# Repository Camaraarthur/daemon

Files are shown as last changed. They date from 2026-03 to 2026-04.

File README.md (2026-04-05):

<div align="center">
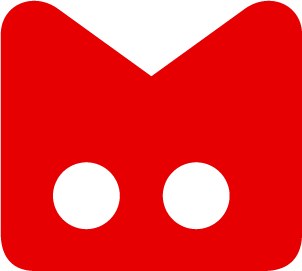
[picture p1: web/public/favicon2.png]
  
  <h1>daemon</h1>
  <p><strong>One AI agent. Terminal access to every device you own.</strong></p>
  <p>Open source &bull; Multi-device &bull; Free tier included &bull; Bring your own keys</p>

  <a href="https://daemon.page">Website</a> &bull;
  <a href="https://daemon.page/download">Download</a> &bull;
  <a href="SPEC.md">Spec</a> &bull;
  <a href="docs/">Docs</a>
</div>

---

## What is Daemon?

Daemon connects all your devices -- laptop, phone, server -- into one AI-powered workspace. Chat with your daemon, and it runs commands on any connected device, syncs your clipboard, deploys your apps, and remembers everything across sessions.

**Free tier**: Qwen3-Coder via OpenRouter. No credit card needed.
**Bring your own key**: Paste your Anthropic/OpenAI/DeepSeek key.
**Link Claude Max**: Use your $100/mo subscription through Daemon.

## Quick Start

```bash
# Install on any device (macOS, Linux, Windows)
curl -sSL daemon.page/install.sh | bash

# Pair with your account
daemon pair <CODE>  # Get code at daemon.page/download

# That's it. Your device is connected.
```

## Features

- **Multi-device mesh** -- Connect phone, laptop, server. Run commands on any device from anywhere.
- **Clipboard sync** -- Copy on your phone, paste on your laptop. Automatic.
- **One-click deploy** -- `/deploy` publishes to username.daemon.page instantly.
- **Persistent memory** -- Your daemon remembers across sessions. Never re-explain context.
- **Slash commands** -- `/commit`, `/deploy`, `/review`, `/search` -- power tools built in.
- **Your data stays yours** -- Local-first. Open source. Self-hostable.
- **Any model** -- Qwen (free), DeepSeek, Claude, GPT -- bring your own keys.
- **Native apps** -- Android, Windows, macOS, Linux. Same experience everywhere.

## How it works

<div align="center">
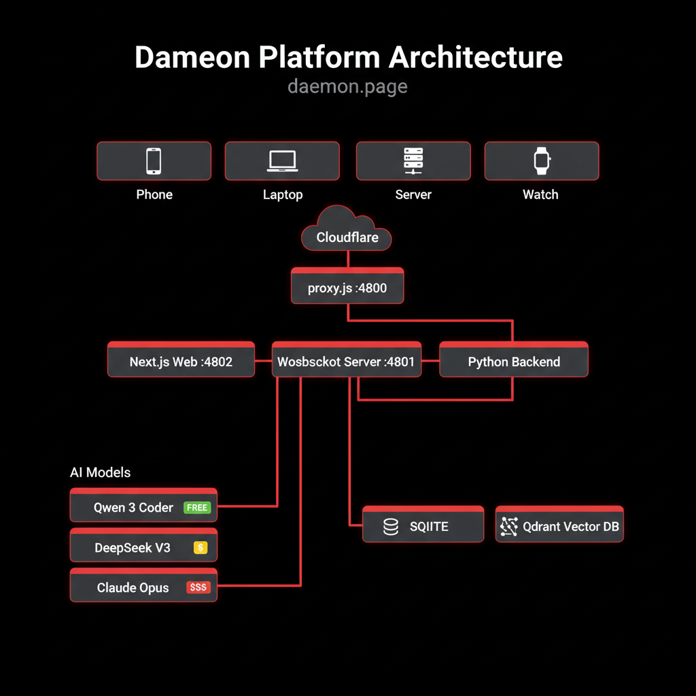
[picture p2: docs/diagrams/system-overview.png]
Daemon system overview
  
</div>

1. Install daemon on your devices
2. Each device connects via WebSocket to the daemon server
3. Chat with your AI -- it can run commands on any connected device
4. Deploy apps, sync files, search memory -- all through one conversation

## vs. Alternatives

| | Daemon | Claude Code | Cursor | Windsurf |
|---|---|---|---|---|
| Multi-device | All devices | One terminal | One IDE | One IDE |
| Free tier | Qwen unlimited | $20+/mo | $20/mo | $15/mo |
| Deploy apps | your.daemon.page | -- | -- | -- |
| Clipboard sync | Cross-device | -- | -- | -- |
| Memory | Persistent | Session only | -- | -- |
| Open source | MIT | -- | -- | -- |
| Self-hostable | Docker compose | -- | -- | -- |
| BYOK | Any provider | Anthropic only | Multiple | Multiple |

## Architecture

Daemon is a monorepo with four main components:

- **`web/`** -- Next.js web UI and API server (port 4800)
- **`cli/`** -- Cross-platform device bridge (Node.js)
- **`android/`** -- Native Android app (Kotlin/Jetpack Compose)
- **`desktop/`** -- Desktop bridge (Tauri/Rust)
- **`protocol/`** -- Shared protocol types (TypeScript)

The server coordinates WebSocket connections between devices and routes AI requests through a 3-tier model router (free Qwen -> mid DeepSeek -> premium Claude/GPT via BYOK).

See [SPEC.md](SPEC.md) for the full v0 specification (7,300 words covering protocol, security, agent architecture, and deployment).

## Self-hosting

```bash
git clone https://github.com/arthurcamara/daemon.git
cd daemon
docker compose up -d
```

Requires: Node.js 20+, SQLite. See [docs/](docs/) for detailed setup.

## Contributing

We welcome contributions. Daemon is built in the open.

- Read [CONTRIBUTING.md](CONTRIBUTING.md) before making changes
- Read [SPEC.md](SPEC.md) for architecture decisions
- Follow the rules in [CLAUDE.md](CLAUDE.md)

## License

[MIT](LICENSE) -- Copyright 2026 Arthur Camara

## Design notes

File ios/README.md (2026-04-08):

# Daemon iOS

Swift native iOS app for daemon. Thin client to `my.daemon.page`. The
brain runs on the user's laptop, daemon-key, or server — the iPhone is
just a face.

- iOS 17+ (required for App Intents, Live Activities)
- Swift 5.9+
- Zero third-party dependencies
- XcodeGen-managed project — no `.xcodeproj` committed

## What's in here

```
ios/Daemon/
├── project.yml                    # XcodeGen spec, materialize with `xcodegen`
├── SupportingFiles/
│   ├── Info.plist
│   ├── Daemon.entitlements        # APNs + App Groups
│   ├── NotificationServiceExtension-Info.plist
│   └── NotificationServiceExtension.entitlements
├── Sources/
│   ├── Daemon/
│   │   ├── DaemonApp.swift              # @main, AppDelegate, silent-push drain
│   │   ├── ContentView.swift            # SwiftUI chat UI
│   │   ├── DaemonClient.swift           # HTTP + WSS + Keychain client
│   │   ├── MockRelay.swift              # fake responses for simulator
│   │   ├── Views/QRScannerView.swift    # AVCaptureSession QR scanner
│   │   ├── AppIntents/
│   │   │   ├── DaemonAppShortcuts.swift       # AppShortcutsProvider
│   │   │   ├── ChatWithDaemonIntent.swift
│   │   │   ├── ReadFileIntent.swift
│   │   │   ├── WriteFileIntent.swift
│   │   │   ├── RemindMeIntent.swift
│   │   │   ├── WhereAmIIntent.swift
│   │   │   └── ClipboardToDaemonIntent.swift
│   │   ├── LiveActivities/
│   │   │   ├── DaemonActivityAttributes.swift
│   │   │   └── DaemonActivityView.swift       # WidgetKit ActivityConfiguration
│   │   ├── Shortcuts/ShortcutsInstaller.swift # first-run Siri donations
│   │   └── Resources/
│   │       ├── Shortcuts/shortcuts.json       # bundled phrase library
│   │       └── MockChatResponse.json
│   └── NotificationServiceExtension/
│       └── NotificationService.swift          # rich push + action buttons
└── README.md
```

## First-time setup (one-time)

1. Install XcodeGen:
   ```sh
   brew install xcodegen
   ```
2. Generate the Xcode project:
   ```sh
   cd ios/Daemon
   xcodegen generate
   open Daemon.xcodeproj
   ```
3. In Xcode → Signing & Capabilities for both targets:
   - Set your **Development Team**
   - Confirm the **Push Notifications** capability
   - Confirm **Background Modes → Remote notifications**
   - Confirm the **App Groups** capability (`group.page.daemon.shared`)
   - Confirm **Live Activities** is enabled (auto from `NSSupportsLiveActivities`)

## Running on the simulator

1. Pick any iOS 17+ simulator
2. Build & run (`⌘R`)
3. On the unpair screen, tap **Use Mock Relay (dev)** to bypass the network
   and exercise the chat UI against the bundled fixtures

The simulator cannot receive real APNs pushes, but you can simulate them:

```sh
xcrun simctl push booted page.daemon.ios ios/Daemon/test/silent-push.apns
```

(Create `silent-push.apns` locally with `{"aps":{"content-available":1}}`.)

## Running on device

1. Plug in an iPhone running iOS 17+
2. Trust the developer cert in Settings → General → VPN & Device Management
3. Build & run — first launch will ask for notification permission and
   camera permission (for QR scan)
4. Pair: on my.daemon.page → Settings → Pair new device → show QR → scan

## Deploying to TestFlight

Arthur's checklist once he has an Apple Developer account (\$99/yr):

1. **App Store Connect** → My Apps → **New App**
   - Name: `Daemon`
   - Bundle ID: `page.daemon.ios` (register under Certificates, Identifiers & Profiles first)
   - Primary language: English
2. **Register the App ID** in the Developer portal with:
   - Push Notifications
   - App Groups (`group.page.daemon.shared`)
3. **Register the extension App ID**: `page.daemon.ios.NotificationService`
4. **APNs Auth Key**: create an `.p8` key in the Developer portal and upload to
   the daemon relay (`web/`) so the relay can send pushes
5. **In Xcode**:
   - Set `MARKETING_VERSION` / `CURRENT_PROJECT_VERSION` in `project.yml`,
     then re-run `xcodegen generate`
   - Product → Archive
   - Window → Organizer → Distribute App → TestFlight & App Store → Upload
6. **In App Store Connect** → TestFlight:
   - Add internal testers (instant) or external testers (Beta App Review, ~24h)
   - Up to 10,000 external testers worldwide, free
7. **Send the invite link** — testers install via the TestFlight app

## Relay endpoints the app talks to

- `POST https://my.daemon.page/api/pair` — `{action: "claim", code, device_id, device_name, platform}` → `{device_token, ws_url}`
- `POST https://my.daemon.page/api/chat` — `{message, threadId?, stream: false}` → `{message, threadId}`
- `WSS wss://my.daemon.page/ws/client` — foreground-only subscription
- `POST https://my.daemon.page/api/devices/apns` — register APNs token (relay must implement this route; stub for now)

## Known limitations / TODOs

- No background WebSocket (Apple kills it — all durable sync is APNs silent push)
- `drainPendingEvents` is a stub — needs a real "fetch events since cursor" endpoint on the relay
- `POST /api/devices/apns` doesn't exist yet on the relay — the client calls it, the relay needs to accept it
- Live Activities widget is declared on the main target; if builds complain, split it into a dedicated Widget Extension target in `project.yml`
- No unit tests yet — add `DaemonTests` target to `project.yml` once behavior stabilizes

## Protocol source of truth

Don't reinvent the protocol — read `/home/arthur/daemon/protocol/types.ts`.
The relay endpoints live in `/home/arthur/daemon/web/src/app/api/`.

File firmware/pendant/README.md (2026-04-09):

# Honest Puck v3.2 — firmware

Privacy-first wearable microphone pendant. ESP32-S3-WROOM-1. ESP-IDF v5.2.

This tree is a fork/rewrite of
[BasedHardware/omi](https://github.com/BasedHardware/omi) `omiGlass/firmware/`
(MIT). The upstream was Arduino + PlatformIO and assumed a Seeed XIAO
ESP32-S3 Sense board with built-in camera. We keep the BLE audio protocol
and the PDM capture pattern, strip the camera + display + all Arduino
dependencies, and target bare ESP-IDF with NimBLE. See [`NOTICE`](NOTICE) for
the per-file credit map.

## What runs on the board

```
app_main()
  |
  |-- honest_gate_init()         IO4 HIGH => mic VDD = 0 V, red LEDs dark
  |-- nvs + NimBLE stack
  |-- honest_ui_init()           buttons + WS2812C RMT driver
  |-- honest_ble_init()          GATT server: Omi audio service (19B10000-...)
  |-- boot self-test             pulse rail ON for 150 ms, then OFF
  |-- idle
        ^
        |  BTN_MAIN press OR BLE control write 0x01
        v
  honest_gate_set_mic_power(true)    IO4 LOW  => mic + LEDs hot
  honest_mic_start()                 i2s_pdm RX @ 16 kHz/16-bit/mono
    -> every 100 ms frame ->
  honest_ble_send_audio_pcm()        Omi framing, notify on AudioData char
```

## Hardware privacy interlock (the whole point)

The mic VDD and the four red WS2812C LEDs share a single copper net that
is the drain of a Si2301BDS PMOS load switch gated by IO4. There is **no**
software path that can record without lighting the ring. See the WARNING
block in
[`components/honest_mic/include/honest_gate.h`](components/honest_mic/include/honest_gate.h)
and the boot self-test in `main/honest_puck_main.c`.

## Pin map

From
[`/media/arthur/CA2247E02247D05D/projects/pendant/ARCHITECTURE.md`](../../)
— see `components/honest_common/include/honest_puck_pins.h`.

| GPIO  | Function |
|---|---|
| IO0 | BTN_MAIN (strapping, normal boot = HIGH) |
| IO1 | BTN_PROG1 |
| IO4 | MIC_ENABLE_N (Si2301BDS PMOS gate) |
| IO5 | PDM_CLK |
| IO6 | PDM_DATA |
| IO7 | LED_BOOST_EN (TPS61023) |
| IO8 | WS2812C data (4 pixels) |
| IO9 | BTN_BATT |
| IO14  | BTN_PROG2 |
| IO10-13, IO2, IO3 | QSPI NAND flash (W25N02KV) (driver not yet wired) |

## Build

Requires ESP-IDF **v5.2** (tested against the release/v5.2 branch).

```bash
. $IDF_PATH/export.sh
cd /home/arthur/daemon/firmware/pendant
idf.py set-target esp32s3
idf.py build
# then on the MSI box that has the serial cable:
idf.py -p /dev/ttyACM0 flash monitor
```

`sdkconfig.defaults` enables NimBLE, octal PSRAM (flip to
`CONFIG_SPIRAM_MODE_QUAD` if your WROOM-1 is the R2 variant, not R8), and
the new I2S driver. No menuconfig steps are required for a first build.

## BLE protocol (client side)

Exactly matches the Omi audio subset:

- Service UUID       `19B10000-E8F2-537E-4F6C-D104768A1214`
- Audio data (notify) `19B10001-...` — 2-byte index + 1-byte sub-index + payload
- Audio codec (read)  `19B10002-...` — one byte; **currently `0` (PCM16)**
- Control (write)     `19B10006-...` — `0x01` = start recording, `0x00` = stop

The daemon Android app (`/home/arthur/daemon/android/`) already speaks Omi
so the only thing it needs to learn is that codec id `0` means raw 16-bit
little-endian PCM at 16 kHz, mono. No changes to pairing or discovery.

## Deliberate decisions made without asking

1. **Codec is raw PCM16, not Opus.** To keep the dep graph MIT/Apache only
   and to guarantee a clean first `idf.py build`, we do not pull libopus.
   The framing and the GATT layout are unchanged, so switching is a
   one-file swap inside `honest_ble_send_audio_pcm()`. Flagged below.
2. **No photo characteristics.** omi uses `19B10005/6` for JPEG transfer.
   The pendant has no camera, so these are removed entirely (not
   advertised, not mounted).
3. **No OTA characteristics.** `19B10010/11/12` removed. The partition
   table still reserves two OTA slots so this can be added later without
   a factory reflash.
4. **No photo button, no camera pins, no OLED** — all stripped from
   omiGlass. ~3000 lines of `app.cpp` became ~150 lines of `honest_ble.c`.
5. **Integer mic gain ×2** kept from upstream as a reasonable default.
6. **Buttons wake the CPU from light sleep implicitly** via GPIO ISR. Deep
   sleep wake-on-button is NOT configured — see below.

## What is NOT done (known limits)

- **Opus encoding** — codec id is PCM16. A 32 kbps Opus path exists in
  upstream and is a straightforward port once libopus or a managed
  component is added.
- **Firmware OTA over BLE** — upstream has a full WiFi+HTTP OTA path
  (`src/ota.cpp`, 408 lines). Partition table has two OTA slots but the
  service is not implemented.
- **Deep sleep + wake-on-button** — the pendant boots straight into idle.
  No light/deep sleep entry, no RTC GPIO wake.
- **W25N02KV NAND driver** — pins are reserved but there is no SPI NAND
  init, no offline recording buffer, no wear levelling.
- **Battery monitoring** — `BTN_BATT` is polled by `honest_ui_button_level()`
  but there is no ADC-based battery voltage reading. The pendant has a
  TP4056 + TPS63031 rail so we'd need a divider added on a spare ADC pin,
  which is not in the current netlist.
- **Audio compression tuning** — no DC blocking filter, no AGC, no noise
  gate.
- **BLE pairing / encryption** — currently no bonding. Any central can
  connect. Fine for bench, not fine for shipping.
- **WS2812 self-test robustness** — the boot self-test just pulses the
  rail for 150 ms; it does not read back current draw or verify the RMT
  TX actually completed. A hardware interlock test jig is the proper fix.
- **Build has not been executed on this machine** (no ESP-IDF v5.2 in
  path). Source is believed to compile clean against release/v5.2 but has
  not been proven — see "Untested" below.

## Untested

- `idf.py build` has not been run. The code targets ESP-IDF v5.2 APIs
  (`driver/i2s_pdm.h`, `driver/rmt_tx.h`, NimBLE host on `bt` component)
  which all exist in v5.2. Most likely breakage would be a missing
  `REQUIRES` entry or an RMT encoder field rename.
- No hardware has been flashed. User will flash from MSI.

## Repo layout

```
pendant/
  CMakeLists.txt                    top-level IDF project
  sdkconfig.defaults                flash/psram/BLE/I2S defaults
  partitions.csv                    (using built-in "two_ota" table)
  LICENSE                           MIT
  NOTICE                            per-file credit to BasedHardware/omi
  README.md
  main/
    CMakeLists.txt
    honest_puck_main.c              boot order + recording FSM
  components/
    honest_common/                  shared pin map header
    honest_mic/
      honest_gate.c                 Si2301BDS IO4 interlock
      honest_mic.c                  i2s_pdm RX task
    honest_ui/
      honest_buttons.c              debounce ISR + task
      honest_leds.c                 WS2812C RMT driver
      honest_ui.c                   init glue
    honest_ble/
      honest_ble.c                  NimBLE GATT + Omi framing
```

## License

MIT. Upstream is MIT. See `LICENSE` + `NOTICE`.

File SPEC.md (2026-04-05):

# Daemon v0 Specification

**Version:** 0.1.0
**Date:** April 5, 2026
**Status:** Canonical. All implementation decisions reference this document.

---

## 1. VISION

### What Daemon IS

Daemon is an open-source AI coding agent with terminal access to every device you own. You sign up, pair your devices, and chat with an AI that can run commands on your laptop, read files on your phone, sync your clipboard, and deploy apps to your personal page -- all through one conversation. It ships with a free model (Qwen via OpenRouter), supports bring-your-own-key for any provider, and treats multi-device connectivity as a first-class feature rather than an afterthought.

### What Daemon is NOT

- **Not a billing platform.** v0 has no Stripe, no credits, no subscriptions. Revenue comes later.
- **Not a voice companion.** No personality engine, no emotional AI, no character customization.
- **Not a skills marketplace.** No third-party plugin registry. Every tool is MCP-standard and user-installed.
- **Not an IDE.** Daemon is a chat-first agent, not a code editor. It executes commands on your behalf.
- **Not a hardware product.** No ESP32, no pendant, no watch app in v0.

### Three-Year Trajectory

| Version | Timeframe | Identity | Core Capability |
|---|---|---|---|
| **v0** | Now | Coding agent | Multi-device chat + terminal + deploy |
| **v1** | 6-12 months | Personal AI | Memory import, calendar, email, photos |
| **v2** | 18-36 months | Device OS | Intent system, app ecosystem, agent-to-agent |

### Core Principles

1. **Data sovereignty.** User data lives on the user's devices. The server is a relay and coordinator, not a data warehouse. Users can self-host the entire stack.
2. **Open protocol.** The Daemon Protocol is a spec, not just an implementation. Anyone can build a compatible client or server. The protocol is the product; the reference implementation proves it works.
3. **Progressive trust.** Daemon asks for zero permissions upfront. Each capability (terminal, files, clipboard, camera) is requested when first needed and can be revoked at any time.
4. **Community-built.** MIT license. Monorepo. No skills marketplace -- MCP servers are the extension format. Contributions go through automated security gates + AI review + human maintainer approval.

---

## 2. USER STORIES

### 2.1 Vibe Coder (Primary Target)

**Maya, 24, self-taught developer. Uses Claude Code and Cursor. Has a MacBook and a Pixel phone.**

1. Maya sees a Show HN post: "Daemon -- open-source AI agent that connects all your devices."
2. She visits **daemon.page**. The hero says "One AI. All your devices." with a 30-second demo video showing a conversation flowing from laptop to phone.
3. She clicks "Get Started" and signs in with Google. Takes 3 seconds.
4. She gets **maya.daemon.page** as her personal page.
5. The dashboard says "Connect a device to get started." She sees her OS auto-detected (macOS) and a one-liner: `npx daemon-cli pair`.
6. She runs it in her terminal. A 6-character code appears: `XK7M2P`. She types it into the web UI.
7. Her MacBook appears in the device list with a green dot. The chat says: "Connected to Maya's MacBook. I can now run commands and access files. What would you like to build?"
8. She types: "Build me a personal blog with a dark theme."
9. Daemon (using free Qwen model) scaffolds a Next.js site in her home directory, writes the pages, and says: "Ready. Type /deploy to publish it to maya.daemon.page."
10. She types `/deploy`. Daemon builds the site and deploys it. She opens maya.daemon.page on her phone and sees her blog.
11. She copies the URL on her phone. It appears on her MacBook clipboard automatically (clipboard sync).
12. Later, she pastes her OpenAI API key in settings. Now Daemon uses GPT-5 for her requests.

**Time from discovery to first deployed app: under 10 minutes.**

### 2.2 Power Developer

**Raj, 32, senior engineer. Claude Max subscriber. Has a Linux workstation, a Windows laptop, and an Android phone.**

1. Raj installs Daemon and links all three devices. Each appears in his mesh with its capabilities listed.
2. He pastes his Anthropic API key. Daemon routes through Claude Opus for all requests.
3. He creates a project called "invoice-api" and starts chatting: "Set up a FastAPI project with SQLite, auth, and CRUD for invoices."
4. Daemon writes the code on his Linux workstation (the device with the project directory), runs tests, and reports results -- all visible in the web UI and on his phone.
5. He types `/commit` -- Daemon creates a clean git commit with a generated message.
6. He types `/deploy` -- Daemon builds a Docker container and deploys to raj.daemon.page.
7. On the bus home, he opens Daemon on his phone, reviews the code diff in the chat, and says "Add input validation for the amount field." Daemon makes the change on his workstation remotely.
8. Memory persists: next week, when he returns to the project, Daemon remembers the stack, the file structure, and the pending TODO for pagination.

### 2.3 Non-Technical User (Future -- NOT v0)

**Elena, 45, marketing director. Has an iPhone and a MacBook.**

1. Elena signs up and imports her WhatsApp chat history.
2. Daemon learns her communication style (concise, no emojis, prefers bullet points).
3. She says "Draft a response to the email from Paolo about the Q2 budget."
4. Daemon reads the email (via connected Gmail), drafts a response in Elena's voice, and asks for confirmation before sending.
5. She says "What did I discuss with Luca last Tuesday?" Daemon searches her conversation memory and summarizes.

This persona validates the long-term vision but requires v1 features (email integration, chat import, personality engine). v0 does not target Elena.

---

## 3. PROTOCOL SPECIFICATION

### 3.0 Transport and Encoding

- **Transport:** JSON messages over WebSocket (WSS).
- **Encoding:** UTF-8.
- **Max message size:** 10 MB (for file transfers; base64-encoded data). Messages exceeding this MUST use the HTTP file transfer endpoint instead.
- **Versioning:** Every message includes a `v` field. v0 protocol version is `"0"`. Servers MUST reject messages with unsupported versions.
- **Error format:** `{ "type": "error", "code": "string", "message": "string", "request_id": "string|null" }`
- **Request IDs:** All request-response pairs use `request_id` (UUID v4). The server echoes the `request_id` in the response.

### 3.1 Authentication

**Device registration (after pairing):**
```json
// Client -> Server
{
  "v": "0",
  "type": "auth.hello",
  "device_token": "raw-64-byte-hex-token",
  "device_id": "unique-device-uuid",
  "device_name": "Maya's MacBook",
  "platform": "macos",
  "capabilities": {
    "shell": true,
    "files": true,
    "clipboard": true,
    "notifications": false,
    "camera": false,
    "browser": false
  }
}

// Server -> Client
{
  "v": "0",
  "type": "auth.session",
  "device_id": "unique-device-uuid",
  "user_id": 42,
  "session_id": "ws-session-uuid",
  "message": "Connected as Maya's MacBook"
}
```

The server validates `device_token` by hashing with SHA-256 and looking up the hash in the `device_tokens` table. If validation fails, the server sends an `error` message with code `"auth_failed"` and closes the WebSocket.

### 3.2 Heartbeat

```json
// Client -> Server (every 60 seconds)
{
  "v": "0",
  "type": "device.heartbeat",
  "timestamp": 1712345678000,
  "state": {
    "battery": 85,
    "online": true,
    "active_project": "invoice-api"
  }
}

// Server -> Client
{
  "v": "0",
  "type": "device.heartbeat_ack",
  "server_time": 1712345678123
}
```

If no heartbeat is received for 120 seconds, the server marks the device as offline and removes it from the active connections map. The client MUST implement reconnection with exponential backoff: 1s, 2s, 4s, 8s, 16s, 32s, 60s max.

### 3.3 Command Execution

```json
// Server -> Device
{
  "v": "0",
  "type": "device.invoke",
  "request_id": "uuid-v4",
  "command": "ls -la ~/projects",
  "timeout_ms": 30000,
  "permission_tier": 3
}

// Device -> Server
{
  "v": "0",
  "type": "device.result",
  "request_id": "uuid-v4",
  "result": {
    "stdout": "total 48\ndrwxr-xr-x ...",
    "stderr": "",
    "exit_code": 0,
    "duration_ms": 45
  }
}
```

The `permission_tier` field tells the device what level of permission this command requires (see Section 5.2). The device MUST check that the user has granted the required permission tier before executing.

### 3.4 MCP Tool Discovery

```json
// Server -> Device
{
  "v": "0",
  "type": "skill.list"
}

// Device -> Server
{
  "v": "0",
  "type": "skill.list_result",
  "tools": [
    {
      "name": "read_file",
      "description": "Read file contents from this device",
      "inputSchema": {
        "type": "object",
        "properties": {
          "path": { "type": "string", "description": "Absolute file path" }
        },
        "required": ["path"]
      }
    },
    {
      "name": "run_command",
      "description": "Execute a shell command on this device",
      "inputSchema": {
        "type": "object",
        "properties": {
          "command": { "type": "string" },
          "working_directory": { "type": "string" }
        },
        "required": ["command"]
      }
    }
  ]
}
```

Each device bridge acts as an MCP server. The Daemon AI agent is an MCP client that discovers tools across all connected devices. Tools are namespaced by device: `macbook.run_command`, `pixel.read_file`.

### 3.5 MCP Tool Call

```json
// Server -> Device
{
  "v": "0",
  "type": "skill.invoke",
  "request_id": "uuid-v4",
  "name": "read_file",
  "arguments": { "path": "/home/maya/projects/blog/index.tsx" }
}

// Device -> Server
{
  "v": "0",
  "type": "skill.result",
  "request_id": "uuid-v4",
  "result": {
    "content": "import React from 'react';\n..."
  }
}
```

### 3.6 Clipboard Sync

```json
// Device -> Server
{
  "v": "0",
  "type": "clipboard.update",
  "content": "https://maya.daemon.page",
  "source_device": "macbook-uuid",
  "timestamp": 1712345678000
}
```

The server broadcasts the clipboard update to ALL other connected devices of the same user. No acknowledgment required. Max clipboard content size: 1 MB. Binary clipboard content (images) is NOT supported in v0.

### 3.7 File Transfer

**Small files (<1 MB): binary WebSocket frames.**

```json
// Metadata message first
{
  "v": "0",
  "type": "file.transfer",
  "request_id": "uuid-v4",
  "filename": "report.pdf",
  "size": 524288,
  "target_device": "pixel-uuid"
}
// Followed by binary WebSocket frame with file contents
```

**Medium/large files (>1 MB): HTTP upload/download.**

Upload to `POST /api/files/upload` (multipart form data, auth via `daemon_token` cookie). The server stores the file temporarily and sends a download notification to the target device via WebSocket. The target device downloads via `GET /api/files/:id`.

Files are auto-deleted after 24 hours.

### 3.8 Chat Messages

```json
// Client -> Server (via HTTP POST /api/chat, not WebSocket)
{
  "message": "Build me a todo app",
  "thread_id": "thread-uuid",
  "project_id": 5,
  "stream": true
}

// Server -> Client (via SSE stream)
data: {"type":"chunk","content":"I'll create a todo app..."}
data: {"type":"tool_call","name":"macbook.run_command","arguments":{"command":"mkdir -p ~/projects/todo-app"}}
data: {"type":"tool_result","content":""}
data: {"type":"chunk","content":"Created the project directory..."}
data: {"type":"done","message_id":"msg-uuid","model":"qwen/qwen3-coder","usage":{"input_tokens":1200,"output_tokens":800}}
```

Chat messages flow over HTTP/SSE, not WebSocket. WebSocket is reserved for device communication. This separation ensures chat works even when no devices are connected.

---

## 4. ARCHITECTURE

### 4.1 Web Server (Next.js)

**Purpose:** Serves the chat UI, dashboard, settings pages, and all API routes.

**Port:** 4802 (proxied through 4800 by proxy.js).

**Key pages:**

| Route | Purpose |
|---|---|
| `/` | Landing page (daemon.page) |
| `/chat` | Chat interface with project sidebar |
| `/devices` | Device mesh dashboard |
| `/settings` | API keys, account, preferences |
| `/download` | OS-detected download page |
| `[subdomain].daemon.page` | User's deployed apps |

**Auth:** All authenticated routes check the `daemon_token` cookie. The cookie is httpOnly, Secure, SameSite=Strict, 30-day expiry. The server validates the token hash against the `sessions` table AND checks `expires_at`.

**Dependencies:** SQLite (via better-sqlite3), Python server module (for auth operations in v0, to be consolidated).

### 4.2 WebSocket Server

**Purpose:** Maintains persistent connections with paired devices. Routes commands from the AI agent to specific devices. Broadcasts clipboard updates.

**Port:** 4801 (proxied through 4800 at `/ws` path).

**Connection lifecycle:**
1. Device opens WSS connection to `wss://my.daemon.page/ws/device`
2. Device sends `auth.hello` with device token
3. Server validates token, adds device to per-user device map
4. Heartbeat loop begins (60-second interval)
5. Server can send `device.invoke` or `skill.invoke` at any time
6. Device can send `clipboard.update`, `device.heartbeat`, or `skill.result` at any time
7. On disconnect, device is removed from map after 120s timeout

**Critical design requirements:**
- Device maps MUST be per-user, not global. A user MUST NOT see or interact with another user's devices.
- Device ID matching MUST be exact (no fuzzy/partial matching).
- The server MUST validate the device token on every WebSocket connection, not just check for existence.

**Dependencies:** ws (Node.js WebSocket library), SQLite for token validation.

### 4.3 Proxy

**Purpose:** Single entry point on port 4800. Routes HTTP to Next.js (4802), WebSocket to WS server (4801).

**Implementation:** ~70 lines of Node.js. Checks the `Upgrade` header for WebSocket connections and the URL path for routing.

**Security requirement for v0:** Add rate limiting at this layer. 60 requests/minute per IP for auth endpoints. 10 requests/second per IP for chat. 5 WebSocket connections per IP.

### 4.4 Device Bridge

**Purpose:** Software that runs on each user device, maintains a WebSocket connection to the server, and exposes local capabilities as MCP tools.

**Platforms:**

| Platform | Implementation | Distribution |
|---|---|---|
| macOS / Linux | Node.js CLI (`daemon-cli`) | `npx daemon-cli pair` |
| Windows | Tauri desktop app | `.msi` download from daemon.page/download |
| Android | Kotlin/Compose app | `.apk` download, later Google Play |

**Common capabilities (all platforms):**
- Shell command execution (with permission gating)
- File read/write (within allowed paths)
- Clipboard read/write (platform-dependent; Android can only write)
- Device info (OS, battery, hostname)

**Platform-specific notes:**

- **macOS/Linux CLI:** Installs as a systemd service (Linux) or LaunchAgent (macOS). Auto-updates by checking the server every 6 hours.
- **Windows/Tauri:** Runs as a system tray app. Shell commands use PowerShell. File paths use backslashes.
- **Android:** Uses a foreground service for active sessions. Transitions to FCM-only for idle state (wake on push, connect, execute, disconnect). Progressive permissions: the app requests ZERO Android permissions at install. Each capability (notifications, camera, files) is requested the first time the AI agent needs it.

**Auto-reconnection:** All bridges implement exponential backoff reconnection (1s, 2s, 4s, 8s, 16s, 32s, 60s max).

### 4.5 AI Chat Engine

**Purpose:** Receives user messages, routes to the appropriate model, executes tool calls, streams responses.

**Model routing:**

| Tier | Model | Provider | Trigger |
|---|---|---|---|
| Free | Qwen3-Coder | OpenRouter | Default for new users |
| BYOK | User's choice | User's API key | User pastes key in settings |
| Premium | Claude Opus | Anthropic API / Claude CLI | User provides Anthropic key or links Max |

All non-Claude models use the OpenAI-compatible chat completions API format. Claude uses the Anthropic SDK or Claude CLI.

**Agent loop:**
1. Receive user message
2. Build context: system prompt + project memory + recent messages (last 20 turns or 30K tokens, whichever is smaller)
3. Call model with tool definitions (derived from connected devices' MCP tools + built-in tools)
4. If response contains tool calls: execute each tool, collect results, go to step 3
5. If response is text: stream to client via SSE, save to database
6. Max iterations: 10. If exceeded, return partial result with explanation.

**Built-in tools (always available, no device required):**
- `read_file` -- read a file on the server (within user's workspace)
- `write_file` -- write a file on the server
- `run_command` -- execute a command in the user's sandbox
- `search` -- search files by content (grep)
- `list_files` -- list directory contents

**Slash commands:**
- `/deploy` -- build and deploy current project to username.daemon.page
- `/commit` -- create a git commit with AI-generated message
- `/memory` -- show/search project memory
- `/devices` -- list connected devices
- `/model` -- switch model for current session
- `/clear` -- clear conversation context

**Streaming:** Responses stream via Server-Sent Events (SSE). Each chunk is a JSON object on a `data:` line. The client renders markdown progressively.

### 4.6 Memory System

**v0 implementation:** Markdown files per project, inspired by Claude Code's CLAUDE.md pattern.

**Storage structure:**
```
data/
  memory/
    user_42/
      global/
        MEMORY.md          # User-level preferences and facts
      projects/
        invoice-api/
          MEMORY.md         # Project-specific memory
          context.json      # Structured data (stack, paths, dependencies)
```

**How memory is created:**
1. At the end of each conversation (or every 10 messages), the AI generates a summary
2. Key facts, decisions, and preferences are extracted
3. The summary is appended to the project's MEMORY.md
4. The structured context (tech stack, file paths, etc.) is updated in context.json

**How memory is used:**
1. On each chat request, the project's MEMORY.md and context.json are loaded into the system prompt
2. Global MEMORY.md is always included
3. Total memory budget: 4K tokens (to leave room for conversation)

**Search:** `grep` over markdown files. No vector search in v0. The Qdrant vector database exists but is not required for v0 launch. It becomes the backend for semantic memory search in v1.

**Why not Qdrant in v0:** Simplicity. Markdown files are inspectable, editable, and portable. They work offline. They can be version-controlled. Vector search adds latency and complexity that is not justified until the memory corpus grows beyond what grep can handle (roughly 1000+ memory entries per user).

### 4.7 Project Management

**Data model:** Each user has projects. Each project has threads. Each thread has messages.

```
User (1) ---> (many) Projects
Project (1) ---> (many) Threads
Thread (1) ---> (many) Messages
```

**Project fields:** name, display_name, local_path (on which device), git_remote, git_branch, stack, domain (for deploy), settings (JSON).

**Thread behavior:**
- One active thread per project at a time
- Switching projects preserves the thread; switching back resumes it
- Threads can be archived but not deleted in v0
- Thread titles are AI-generated from the first user message

**Project creation:** Explicit via the sidebar ("New Project") or implicit when the user starts chatting about a new codebase. The AI can create projects via tool calls.

### 4.8 Hosting (daemon.page)

**How it works:**
1. User types `/deploy` in chat
2. Daemon builds the project (runs `npm run build` or equivalent)
3. Build output is copied to `/var/daemon/sites/{username}/`
4. Cloudflare DNS has a wildcard CNAME: `*.daemon.page -> my.daemon.page`
5. The Next.js server checks the `Host` header; if it matches `{username}.daemon.page`, it serves static files from that user's directory

**Constraints in v0:**
- Static sites only (HTML/CSS/JS). No server-side rendering, no database-backed apps.
- Max 50 MB per site.
- No custom domains (just username.daemon.page).
- Automated security scan before deployment: scan for known malicious patterns (crypto miners, data exfiltration). Block deployment if flagged.

**Future (v1):** Per-user Docker containers for dynamic apps. Custom domain support via Cloudflare.

---

## 5. SECURITY MODEL

### 5.1 Authentication

**Methods:**
- Google OAuth 2.0 (primary, recommended)
- Email + password (fallback)

**Password hashing:** bcrypt with cost factor 12. No SHA-256 fallback. The SHA-256 path in the current codebase MUST be removed before launch.

**Session tokens:**
- Generated as `crypto.randomBytes(32).toString('hex')` (64 hex characters)
- Stored as SHA-256 hash in the `sessions` table
- Cookie: `daemon_token`, httpOnly, Secure, SameSite=Strict, Path=/
- Expiry: 30 days from creation. Enforced in both the cookie `maxAge` AND the `expires_at` database column.
- Middleware MUST validate the token hash against the database on every request, not just check cookie existence.

**Device tokens:**
- Generated as `crypto.randomBytes(32).toString('hex')` (64 hex characters)
- Stored as SHA-256 hash in `device_tokens` table
- Expiry: 30 days from last use (auto-renewed on each heartbeat)
- Revocable via the web UI (Settings > Devices)
- Stored on the device at `~/.daemon/config.json` (chmod 600)

### 5.2 Authorization

**User isolation:** Every database query that touches user data MUST include `WHERE user_id = ?`. There are no admin queries that return cross-user data in any API route.

**Device isolation:** The WebSocket server maintains a `Map<userId, Map<deviceId, WebSocket>>`. A user can only send commands to devices in their own map.

**Permission tiers for device commands:**

| Tier | Permission Level | Examples | Approval |
|---|---|---|---|
| 0 | Always allowed | get_device_info, ping, get_time, get_battery | None |
| 1 | Granted once, logged | list_files, get_clipboard, get_notifications | First-time prompt |
| 2 | Per-session | read_file, write_file, take_screenshot | Granted at session start |
| 3 | Per-action | run_command, send_notification, install_app | Every time, with command preview |

The device bridge enforces these tiers locally. The server sends the `permission_tier` with each command. If the user has not granted the required tier, the device bridge returns an error and the AI explains to the user what permission is needed and why.

### 5.3 Command Execution Sandboxing

**Server-side (for built-in tools):**
- All commands run inside bubblewrap (bwrap) sandboxes
- Read-only bind mounts for system directories (/usr, /bin, /lib)
- Read-write only for the user's workspace directory
- Network isolation (`--unshare-net`) by default; opt-in per command
- Process isolation (`--unshare-pid`)
- Auto-cleanup on parent death (`--die-with-parent`)
- 30-second timeout per command

**Device-side:**
- CLI/desktop bridges: commands run as the bridge's OS user but with a blocklist of known-dangerous patterns (rm -rf /, dd if=/dev/zero, fork bombs, etc.)
- Android: no raw `run_command`. Instead, a curated set of 15 MCP tools (open_app, set_alarm, toggle_wifi, read_contacts, etc.)

**Post-launch (multi-user):** Switch from bubblewrap to Firecracker microVMs. Each user gets their own VM with dedicated filesystem, network namespace, and resource limits (2 GB RAM, 1 CPU, 256 PIDs).

### 5.4 Transport Security

- All external connections via WSS through Cloudflare Tunnel (TLS 1.3)
- API calls over HTTPS only
- CORS policy: only `daemon.page` and `*.daemon.page` origins
- CSRF protection: SameSite=Strict cookie + custom `X-Daemon-Client` header on all API requests

### 5.5 Data at Rest

**v0 minimum:**
- SQLite with WAL mode
- bcrypt for passwords
- SHA-256 for token hashing
- API keys (BYOK) stored in users.settings JSON column (encrypted with a server-side key in v1)
- Daily automated backups at 03:00 via cron, 30-day retention

**Post-launch:**
- SQLCipher for database encryption
- Per-user encryption keys derived from user credentials
- Cloudflare R2 for off-site backup storage

### 5.6 Rate Limiting

| Endpoint | Limit | Window |
|---|---|---|
| POST /api/auth (login/signup) | 10 | per minute per IP |
| POST /api/chat | 30 | per minute per user |
| POST /api/pair | 10 | per minute per user |
| WebSocket connections | 5 | per IP |
| File uploads | 10 | per hour per user |

Rate limiting is enforced at the proxy layer using in-memory counters with sliding windows.

### 5.7 Input Sanitization

- Shell commands from the AI agent MUST be passed as array arguments to `execFile`, never interpolated into strings.
- The current shell injection vulnerability in `chat/route.ts` (token interpolated into Python code) MUST be fixed: pass the token via `process.argv` or environment variable.
- All user-provided strings stored in SQLite MUST use parameterized queries (already the case in most code, but MUST be verified for all paths).

---

## 6. DATABASE SCHEMA

All tables live in a single SQLite database at `data/users.db` with WAL mode enabled.

```sql
-- Users: account information
CREATE TABLE users (
    id INTEGER PRIMARY KEY AUTOINCREMENT,
    email TEXT UNIQUE NOT NULL,
    password_hash TEXT NOT NULL,              -- bcrypt hash, prefixed "bcrypt:"
    daemon_name TEXT UNIQUE NOT NULL,          -- username for {name}.daemon.page
    created_at TEXT NOT NULL DEFAULT (datetime('now')),
    last_login TEXT,
    settings TEXT DEFAULT '{}'                 -- JSON: { byok_keys: {}, preferences: {} }
);

-- Sessions: login tokens
CREATE TABLE sessions (
    token_hash TEXT PRIMARY KEY,               -- SHA-256 of raw token
    user_id INTEGER NOT NULL,
    created_at TEXT NOT NULL DEFAULT (datetime('now')),
    expires_at TEXT NOT NULL,                   -- datetime('now', '+30 days')
    FOREIGN KEY (user_id) REFERENCES users(id)
);

-- Projects: code projects
CREATE TABLE projects (
    id INTEGER PRIMARY KEY AUTOINCREMENT,
    user_id INTEGER NOT NULL,
    name TEXT NOT NULL,                         -- slug: "invoice-api"
    display_name TEXT,                          -- "Invoice API"
    local_path TEXT,                            -- absolute path on device
    device_id TEXT,                             -- which device has this project
    git_remote TEXT,
    git_branch TEXT DEFAULT 'main',
    stack TEXT,                                 -- "nextjs", "fastapi", etc.
    domain TEXT,                                -- subdomain for deploy
    settings TEXT DEFAULT '{}',
    created_at TEXT NOT NULL DEFAULT (datetime('now')),
    last_active TEXT,
    UNIQUE(user_id, name),
    FOREIGN KEY (user_id) REFERENCES users(id)
);

-- Chat threads: conversations within projects
CREATE TABLE chat_threads (
    id TEXT PRIMARY KEY,                        -- UUID v4
    project_id INTEGER,
    user_id INTEGER NOT NULL,
    title TEXT DEFAULT 'New conversation',
    created_at TEXT NOT NULL DEFAULT (datetime('now')),
    last_message_at TEXT,
    FOREIGN KEY (project_id) REFERENCES projects(id),
    FOREIGN KEY (user_id) REFERENCES users(id)
);

-- Chat messages: individual messages
CREATE TABLE chat_messages (
    id TEXT PRIMARY KEY,                        -- UUID v4
    thread_id TEXT NOT NULL,
    role TEXT NOT NULL,                          -- 'user', 'assistant', 'tool'
    content TEXT,
    tool_calls TEXT,                             -- JSON array of tool calls
    tool_call_id TEXT,                           -- for role='tool', links to the tool call
    model TEXT,                                  -- which model generated this
    tokens_used INTEGER,
    created_at TEXT NOT NULL DEFAULT (datetime('now')),
    FOREIGN KEY (thread_id) REFERENCES chat_threads(id)
);

-- Device tokens: paired device credentials
CREATE TABLE device_tokens (
    id INTEGER PRIMARY KEY AUTOINCREMENT,
    user_id INTEGER NOT NULL,
    device_id TEXT NOT NULL UNIQUE,              -- UUID, self-reported at pair time
    device_name TEXT,                            -- "Maya's MacBook"
    platform TEXT,                               -- "macos", "linux", "windows", "android"
    token_hash TEXT NOT NULL UNIQUE,             -- SHA-256 of raw token
    permissions TEXT DEFAULT '{"tier":0}',       -- JSON: granted permission tiers
    created_at TEXT NOT NULL DEFAULT (datetime('now')),
    last_seen TEXT,
    expires_at TEXT,                             -- datetime('now', '+30 days'), renewed on heartbeat
    revoked INTEGER DEFAULT 0,
    FOREIGN KEY (user_id) REFERENCES users(id)
);

-- Conversation memory: AI-generated summaries
CREATE TABLE conversation_memory (
    id INTEGER PRIMARY KEY AUTOINCREMENT,
    thread_id TEXT NOT NULL,
    project_id INTEGER,
    user_id INTEGER NOT NULL,
    tldr TEXT NOT NULL,
    key_decisions TEXT,                          -- JSON array
    key_facts TEXT,                              -- JSON array
    problems TEXT,                               -- JSON array
    solutions TEXT,                              -- JSON array
    tags TEXT,                                   -- comma-separated
    created_at TEXT NOT NULL DEFAULT (datetime('now')),
    FOREIGN KEY (thread_id) REFERENCES chat_threads(id)
);

-- Usage log: for analytics and future billing
CREATE TABLE usage_log (
    id INTEGER PRIMARY KEY AUTOINCREMENT,
    user_id INTEGER NOT NULL,
    model TEXT NOT NULL,
    provider TEXT NOT NULL,                      -- "openrouter", "anthropic", "byok"
    input_tokens INTEGER DEFAULT 0,
    output_tokens INTEGER DEFAULT 0,
    cost_usd REAL DEFAULT 0,
    key_source TEXT DEFAULT 'daemon',            -- "daemon" or "byok"
    project_id INTEGER,
    thread_id TEXT,
    created_at TEXT NOT NULL DEFAULT (datetime('now')),
    FOREIGN KEY (user_id) REFERENCES users(id)
);

-- Indexes
CREATE INDEX idx_projects_user ON projects(user_id);
CREATE INDEX idx_threads_project ON chat_threads(project_id);
CREATE INDEX idx_threads_user ON chat_threads(user_id);
CREATE INDEX idx_messages_thread ON chat_messages(thread_id);
CREATE INDEX idx_messages_created ON chat_messages(created_at);
CREATE INDEX idx_memory_user ON conversation_memory(user_id);
CREATE INDEX idx_memory_project ON conversation_memory(project_id);
CREATE INDEX idx_device_tokens_hash ON device_tokens(token_hash);
CREATE INDEX idx_device_tokens_user ON device_tokens(user_id);
CREATE INDEX idx_usage_user_date ON usage_log(user_id, created_at);
```

**Tables removed from current codebase for v0:**
- `subscriptions` -- no billing in v0
- `credit_usage` -- no billing in v0
- `imported_sessions` -- not a v0 feature

---

## 7. FILE STRUCTURE

```
daemon/
├── SPEC.md                  # THIS DOCUMENT - the canonical spec
├── README.md                # Public-facing, links to spec
├── LICENSE                  # MIT
├── package.json             # Monorepo root (workspaces)
│
├── protocol/                # Protocol specification and shared types
│   ├── PROTOCOL.md          # Human-readable protocol spec (extracted from SPEC.md Section 3)
│   └── types.ts             # TypeScript type definitions for all message types
│
├── web/                     # Next.js web UI + API routes
│   ├── src/
│   │   ├── app/
│   │   │   ├── page.tsx             # Landing page
│   │   │   ├── chat/page.tsx        # Chat interface
│   │   │   ├── devices/page.tsx     # Device mesh dashboard
│   │   │   ├── settings/page.tsx    # User settings
│   │   │   ├── download/page.tsx    # OS-detected download page
│   │   │   └── api/
│   │   │       ├── auth/route.ts        # Login, signup, Google OAuth
│   │   │       ├── chat/route.ts        # Send message, stream response
│   │   │       ├── projects/route.ts    # CRUD projects
│   │   │       ├── threads/route.ts     # List threads, get messages
│   │   │       ├── pair/route.ts        # Generate and claim pairing codes
│   │   │       ├── devices/route.ts     # List and manage devices
│   │   │       ├── memory/route.ts      # Search memory
│   │   │       ├── settings/route.ts    # Get/update user settings
│   │   │       ├── files/route.ts       # File upload/download for transfers
│   │   │       └── deploy/route.ts      # Build and deploy to daemon.page
│   │   ├── lib/
│   │   │   ├── db.ts                # SQLite connection + migrations
│   │   │   ├── auth.ts              # Session validation, token management
│   │   │   ├── agent-loop.ts        # Model call -> tool exec -> repeat
│   │   │   ├── model-router.ts      # Route to Qwen/BYOK/Claude
│   │   │   ├── streaming.ts         # SSE response helpers
│   │   │   ├── safety-check.ts      # Command blocklist
│   │   │   ├── sandbox.ts           # Bubblewrap command execution
│   │   │   ├── memory.ts            # Read/write markdown memory files
│   │   │   └── mcp-bridge.ts        # MCP client for device tools
│   │   ├── components/
│   │   │   ├── ChatPanel.tsx
│   │   │   ├── ProjectSidebar.tsx
│   │   │   ├── DeviceList.tsx
│   │   │   ├── MessageBubble.tsx
│   │   │   ├── ToolCallBlock.tsx
│   │   │   └── SettingsForm.tsx
│   │   └── store/
│   │       ├── chat.ts              # Zustand: messages, streaming state
│   │       ├── projects.ts          # Zustand: project list, active project
│   │       └── devices.ts           # Zustand: connected devices
│   ├── package.json
│   └── next.config.js
│
├── ws/                      # WebSocket server (separate process)
│   ├── server.ts            # Device connection handling, per-user routing
│   ├── clipboard.ts         # Clipboard broadcast logic
│   └── package.json
│
├── proxy/                   # Entry point proxy
│   ├── proxy.ts             # Port 4800 -> 4802 (HTTP) / 4801 (WS)
│   ├── rate-limiter.ts      # In-memory sliding window rate limiting
│   └── package.json
│
├── cli/                     # CLI device bridge (Node.js)
│   ├── daemon-cli.ts        # Entry point: pair, connect, status
│   ├── bridge.ts            # WebSocket client + MCP server
│   ├── tools/               # Platform-specific tool implementations
│   │   ├── shell.ts
│   │   ├── files.ts
│   │   └── clipboard.ts
│   ├── auto-update.ts       # Check server for updates every 6 hours
│   └── package.json
│
├── android/                 # Kotlin/Compose Android app
│   ├── app/src/main/
│   │   ├── java/.../daemon/
│   │   │   ├── DaemonApp.kt
│   │   │   ├── DaemonService.kt        # Foreground service + WS client
│   │   │   ├── PairActivity.kt         # Pairing flow
│   │   │   ├── ChatActivity.kt         # WebView chat
│   │   │   ├── PermissionManager.kt    # Progressive permission requests
│   │   │   └── tools/                  # MCP tool implementations
│   │   │       ├── ShellTool.kt
│   │   │       ├── FilesTool.kt
│   │   │       ├── ClipboardTool.kt
│   │   │       └── NotificationTool.kt
│   │   └── AndroidManifest.xml
│   └── build.gradle.kts
│
├── desktop/                 # Tauri desktop app (Windows/Mac/Linux)
│   ├── src-tauri/
│   │   ├── src/main.rs
│   │   └── Cargo.toml
│   └── src/                 # Shared web UI via WebView
│
├── data/                    # Runtime data (gitignored)
│   ├── users.db             # SQLite database
│   ├── backups/             # Daily database backups
│   ├── memory/              # Markdown memory files per user/project
│   ├── sites/               # Deployed static sites per user
│   └── files/               # Temporary file transfer storage
│
├── docker/
│   ├── sandbox/
│   │   └── Dockerfile       # Sandbox image for tool execution
│   └── qdrant/
│       └── docker-compose.yml
│
├── docs/
│   ├── OVERVIEW.md          # Architecture overview with diagrams
│   ├── V0_DECISIONS.md      # Architecture decisions log
│   ├── WAR_ROOM.md          # Technical reality assessment
│   └── research/            # Deep research documents
│
├── scripts/
│   ├── backup.sh            # Database backup (cron)
│   ├── deploy-site.sh       # Build + deploy user site
│   └── setup.sh             # First-time setup script
│
└── config/
    ├── proxy.js             # Current proxy (to be migrated to proxy/)
    └── ws-server.js         # Current WS server (to be migrated to ws/)
```

---

## 8. API REFERENCE

All endpoints require authentication via `daemon_token` cookie unless marked PUBLIC.

### Authentication

**POST /api/auth** PUBLIC

```
Action: "login"
Body: { action: "login", email: string, password: string }
Response 200: { user: { id, email, daemon_name }, token: string }
Response 401: { error: "Invalid credentials" }
Cookie set: daemon_token (httpOnly, Secure, SameSite=Strict, maxAge=30d)

Action: "signup"
Body: { action: "signup", email: string, password: string, daemon_name: string }
Response 201: { user: { id, email, daemon_name }, token: string }
Response 400: { error: "Email already registered" | "Name taken" }
Cookie set: daemon_token

Action: "google"
Body: { action: "google", credential: string }  // Google ID token
Response 200: { user: { id, email, daemon_name }, token: string }
Cookie set: daemon_token

Action: "logout"
Body: { action: "logout" }
Response 200: { success: true }
Cookie cleared: daemon_token
```

### Projects

**GET /api/projects**
```
Response 200: { projects: [{ id, name, display_name, local_path, device_id, git_remote, git_branch, stack, domain, created_at, last_active }] }
```

**POST /api/projects**
```
Body: { name: string, display_name?: string, local_path?: string, device_id?: string, git_remote?: string, stack?: string }
Response 201: { project: { id, name, ... } }
Response 400: { error: "Project name already exists" }
```

**PUT /api/projects/:id**
```
Body: { display_name?: string, local_path?: string, ... }  // partial update
Response 200: { project: { id, name, ... } }
Response 404: { error: "Project not found" }
```

**DELETE /api/projects/:id**
```
Response 200: { success: true }
Response 404: { error: "Project not found" }
```

### Chat

**POST /api/chat**
```
Body: {
  message: string,
  thread_id?: string,      // omit to create new thread
  project_id?: number,
  stream?: boolean          // default true
}

If stream=true:
  Response: SSE stream (Content-Type: text/event-stream)
  Events:
    data: { type: "chunk", content: "..." }
    data: { type: "tool_call", id: "...", name: "...", arguments: {...} }
    data: { type: "tool_result", id: "...", content: "..." }
    data: { type: "done", message_id: "...", thread_id: "...", model: "...", usage: { input_tokens, output_tokens } }
    data: { type: "error", message: "..." }

If stream=false:
  Response 200: { message: { id, role: "assistant", content, model, usage }, thread_id }
```

### Threads

**GET /api/threads?project_id=:id**
```
Response 200: { threads: [{ id, project_id, title, created_at, last_message_at }] }
```

**GET /api/threads/:id/messages?limit=50&before=:message_id**
```
Response 200: { messages: [{ id, role, content, tool_calls, model, created_at }] }
```

**DELETE /api/threads/:id**
```
Response 200: { success: true }
```

### Device Pairing

**POST /api/pair**
```
Action: "generate"
Body: { action: "generate" }
Response 200: { code: "XK7M2P", expires_in: 300 }

Action: "claim"
Body: { action: "claim", code: "XK7M2P", device_id: "uuid", device_name: "Maya's MacBook", platform: "macos" }
Response 200: { token: "raw-64-byte-hex-token", device_id: "uuid" }
Response 400: { error: "Invalid or expired code" }
Response 429: { error: "Rate limit exceeded" }
```

### Devices

**GET /api/devices**
```
Response 200: {
  devices: [{
    id: string,
    device_id: string,
    device_name: string,
    platform: string,
    online: boolean,
    last_seen: string,
    permissions: { tier: number },
    capabilities: { shell, files, clipboard, ... }
  }]
}
```

**DELETE /api/devices/:id** (revoke)
```
Response 200: { success: true }
```

### Memory

**GET /api/memory?project_id=:id&q=:query**
```
Response 200: {
  memories: [{
    source: "project" | "global",
    content: string,      // raw markdown
    project_id?: number
  }]
}
```

### Settings

**GET /api/settings**
```
Response 200: {
  email: string,
  daemon_name: string,
  byok_keys: { anthropic?: "sk-...masked", openai?: "sk-...masked" },
  preferences: { model?: string, theme?: string }
}
```

**PUT /api/settings**
```
Body: {
  byok_keys?: { anthropic?: string, openai?: string, google?: string },
  preferences?: { model?: string, theme?: string }
}
Response 200: { success: true }
```

### File Transfer

**POST /api/files/upload** (multipart/form-data)
```
Fields: file (binary), target_device_id (string)
Response 200: { file_id: "uuid", filename: "report.pdf", size: 524288 }
```

**GET /api/files/:id**
```
Response 200: binary file download
Response 404: { error: "File not found or expired" }
```

### Deploy

**POST /api/deploy**
```
Body: { project_id: number }
Response 200 (SSE stream):
  data: { type: "log", message: "Building..." }
  data: { type: "log", message: "Deploying to maya.daemon.page..." }
  data: { type: "done", url: "https://maya.daemon.page" }
  data: { type: "error", message: "Build failed: ..." }
```

### Health

**GET /api/health** PUBLIC
```
Response 200: { status: "ok", version: "0.1.0", uptime: 86400 }
```

**Error codes used across all endpoints:**

| HTTP Status | Meaning |
|---|---|
| 400 | Bad request (invalid params) |
| 401 | Not authenticated |
| 403 | Not authorized (wrong user) |
| 404 | Resource not found |
| 429 | Rate limit exceeded |
| 500 | Internal server error |

---

## 9. IMPLEMENTATION PHASES

### Phase 0: Foundation (Week 1)

**Goal:** Secure the base. Strip non-v0 code. Establish the protocol.

- [ ] Extract protocol types from SPEC.md Section 3 into `protocol/types.ts`
- [ ] Fix shell injection in `chat/route.ts` (pass token via process.argv, not string interpolation)
- [ ] Remove SHA-256 password fallback; bcrypt-only
- [ ] Add `expires_at` enforcement to session middleware
- [ ] Validate token hash against DB in middleware (not just cookie existence)
- [ ] Add rate limiting to proxy (in-memory sliding window)
- [ ] Move to per-user device maps in WebSocket server (no global map)
- [ ] Remove non-v0 API routes: billing, webhooks, voice, esp32-data, sensor-stream, import, camera, share, stream-push, apis, knowledge, tier
- [ ] Remove non-v0 tables: subscriptions, credit_usage, imported_sessions
- [ ] Strip server/ Python code to auth-only (remove personality, voice, ESP32, gemini_live, knowledge)
- [ ] Add bubblewrap sandbox wrapper for server-side command execution
- [ ] Android: remove raw `run_command`, replace with curated MCP tools
- [ ] Android: implement progressive permission requests (zero permissions at install)

**Dependencies:** None. This is parallel work.

### Phase 1: Core Experience (Week 2)

**Goal:** The primary loop works: sign up, pair, chat, build, deploy.

- [ ] Chat works reliably with Qwen free tier via OpenRouter (test 50 diverse prompts)
- [ ] BYOK flow: paste API key in settings, verify it works, use it for chat
- [ ] Device pairing end-to-end: web UI generates code -> CLI runs `npx daemon-cli pair CODE` -> device appears in dashboard
- [ ] MCP tool discovery: server queries device for available tools, adds them to AI's tool list
- [ ] Agent loop with device tools: AI can `run_command` on connected device, read/write files
- [ ] Slash commands: `/deploy`, `/commit`, `/memory`, `/model`
- [ ] Project memory: auto-generate MEMORY.md after conversations, load on project switch
- [ ] Thread management: create, list, switch, archive

**Dependencies:** Phase 0 must be complete.

### Phase 2: Polish (Week 3)

**Goal:** The experience is smooth enough for beta testers.

- [ ] Download page with OS detection (macOS -> CLI instructions, Windows -> .msi link, Android -> .apk link)
- [ ] Auto-deploy to username.daemon.page (static sites)
- [ ] Clipboard sync working between CLI bridge and web UI
- [ ] CLI auto-update mechanism (check server every 6 hours)
- [ ] Graceful error handling in chat (model failures, device disconnects, timeout)
- [ ] Mobile-responsive chat UI
- [ ] Project sidebar with search
- [ ] Settings page for managing devices (view, revoke)
- [ ] Memory search (`/memory search "authentication"`)

**Dependencies:** Phase 1 must be complete.

### Phase 3: Launch (Week 4)

**Goal:** Public GitHub repo. 10 beta testers.

- [ ] Clean the repo: remove all non-v0 files (KiCad, hardware, research, watch)
- [ ] Write README.md: tagline, 30-second GIF, quick start, comparison table, architecture diagram
- [ ] Record 30-second demo video: sign up -> pair -> chat -> deploy
- [ ] Set up GitHub Actions: lint, test, build (Android APK, Tauri, CLI)
- [ ] CONTRIBUTING.md with the "no marketplace, no bloat" stance
- [ ] Open 10 `good-first-issue` issues
- [ ] Invite 10 beta testers (from HN contacts, Twitter followers)
- [ ] Write the Show HN post
- [ ] Monitor: set up basic health check ping (every 5 minutes) with alerts

**Dependencies:** Phase 2 must be complete.

---

## 10. ACCEPTANCE CRITERIA

v0 is done when ALL of the following are true:

### Onboarding
- [ ] A new user can sign up with Google, see their dashboard, and start chatting in under 60 seconds
- [ ] A new user can pair a macOS/Linux device via `npx daemon-cli pair` in under 2 minutes
- [ ] The download page auto-detects the user's OS and shows the right instructions

### Chat
- [ ] Free Qwen model responds correctly to coding questions (tested with 20 diverse prompts)
- [ ] BYOK user can paste an OpenAI API key and get GPT responses
- [ ] BYOK user can paste an Anthropic API key and get Claude responses
- [ ] Streaming works: tokens appear progressively, not all at once
- [ ] Tool calls are visible in the UI (expand/collapse blocks showing command + output)
- [ ] Slash commands work: `/deploy`, `/commit`, `/memory`, `/model`

### Device Mesh
- [ ] Paired device shows as online in the dashboard with correct name and platform
- [ ] AI can run a shell command on the paired device and show the output in chat
- [ ] AI can read a file from the paired device
- [ ] AI can write a file to the paired device
- [ ] Clipboard sync works: copy on laptop, paste on web UI (and vice versa)
- [ ] Device reconnects automatically after network interruption (within 60 seconds)

### Deploy
- [ ] User can say "deploy this" and see their static site at username.daemon.page
- [ ] Deployed site is accessible from any browser without login

### Memory
- [ ] Memory persists across sessions: close chat, reopen, the AI remembers the project context
- [ ] Memory is stored as readable markdown files in `data/memory/`
- [ ] `/memory` command shows relevant memories for the current project

### Security
- [ ] No shell injection vulnerabilities (verified by code review)
- [ ] Session tokens expire after 30 days (verified by checking expired token returns 401)
- [ ] Device tokens expire after 30 days of no use (verified by test)
- [ ] Rate limiting blocks brute-force login attempts (10/min)
- [ ] A user cannot see or command another user's devices (verified by test with 2 accounts)
- [ ] bubblewrap sandbox prevents command from accessing files outside workspace (verified by test)
- [ ] OWASP Top 10 checklist passed (injection, broken auth, XSS, CSRF, SSRF)

### Android
- [ ] App installs with zero permissions requested
- [ ] App opens the chat via WebView
- [ ] First permission request happens only when the AI needs a device capability
- [ ] App does not crash on rotate, background, or kill + restart
- [ ] Foreground service notification appears during active session

### Stability
- [ ] Server stays up for 72 hours under simulated load (10 concurrent users) without crash
- [ ] No white/black screens in the web UI under normal use
- [ ] No unhandled promise rejections in the Node.js processes
- [ ] Database backups run daily and can be restored (verified by test restore)

---

## Appendix A: Technology Stack Summary

| Component | Technology | Version | Why |
|---|---|---|-----|
| Web framework | Next.js | Latest | React SSR, API routes, established ecosystem |
| Database | SQLite + better-sqlite3 | 3.x | Simple, file-based, WAL mode, sufficient to ~50 users |
| WebSocket | ws (Node.js) | 8.x | Mature, performant, widely used |
| Android | Kotlin + Jetpack Compose | Latest | Native Android, best system integration |
| Desktop | Tauri v2 | 2.x | Rust + WebView, cross-platform, small binary |
| CLI | Node.js | 22+ | Runs everywhere, npm distribution |
| Sandbox | bubblewrap | Latest | Used by Chromium and Claude Code, minimal overhead |
| AI Gateway | OpenRouter | N/A | Unified billing, 290+ models, 5.5% fee |
| Tunnel | Cloudflare Tunnel | N/A | Free, global, DDoS protection, wildcard subdomains |
| State management | Zustand | 5.x | Simple, lightweight, no boilerplate |
| Styling | Tailwind CSS | 4.x | Utility-first, fast iteration |

## Appendix B: Environment Variables

```env
# Required
OPENROUTER_API_KEY=         # For free tier model routing
DATABASE_PATH=data/users.db

# Optional (for specific features)
GOOGLE_CLIENT_ID=           # Google OAuth
GOOGLE_CLIENT_SECRET=       # Google OAuth
ANTHROPIC_API_KEY=          # For premium tier (if not using BYOK)
DEEPSEEK_API_KEY=           # For mid tier

# Server config
PORT_PROXY=4800
PORT_WEB=4802
PORT_WS=4801
DAEMON_DOMAIN=daemon.page
NODE_ENV=production
```

## Appendix C: Glossary

| Term | Definition |
|---|---|
| **Bridge** | Software running on a user's device that connects to the Daemon server via WebSocket |
| **BYOK** | Bring Your Own Key -- user provides their own API key for an LLM provider |
| **Device mesh** | The network of all a user's connected devices, coordinated by the server |
| **MCP** | Model Context Protocol -- standard for AI-to-tool communication (Linux Foundation) |
| **Pairing code** | 6-character alphanumeric code used to link a new device to a user account |
| **Progressive permissions** | Requesting device capabilities only when first needed, not at install |
| **Sandbox** | Isolated execution environment (bubblewrap/Docker/Firecracker) for untrusted commands |
| **SSE** | Server-Sent Events -- one-way HTTP stream for real-time updates from server to client |
| **WAL** | Write-Ahead Logging -- SQLite journaling mode that improves concurrent access |

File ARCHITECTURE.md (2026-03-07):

# Daemon V0 – As-Built Architecture Reference

**Source authority:** `netlist/full_system.py`, `netlist/audio_subsystem.py`,
`layout/configure_constraints.py`
**Generated from code only. Every claim in this document is traceable to a
specific net assignment or constant in the source files listed above.**

**ECO #2026-02-V2 (Final Release)** — CAN bus removed; Goobay USB-C bridge,
RTL8152B Ethernet, WS2812B LEDs, IR blaster, chip antenna, WAGO terminal block added.
**ECO #2026-03-A (Critical Fixes)** — IR resistor 100Ω→33Ω; MagJack/Goobay clearance constraint; crystal SI separation constraint.
**ECO #2026-03-D (Advanced Power UX)** — Reset button removed; BSS84 wake-blocker, 2N7002 software kill, SW_PWR button, 3-pin power header added (Subsystem A6).
**ECO #2026-03-E (Kill List Fixes)** — Battery LEDs removed (I2C conflict); WS2812B 1kΩ pull-up; Ethernet center tap bias; SoftSPI nets renamed RF_*; ISET 17kΩ→27kΩ (250mA).
**ECO #2026-03-F (Critical Architecture Rescue)** — RF SoftSPI migrated off UART pins 8/10 to safe GPIOs 13/15/16/18; Ethernet RTL8152B VCC→3V3_CLEAN (LM1117); I2C0 470Ω series protection; IR driver 2N7002→AO3400A.
**ECO #2026-03-G (Signal Integrity & Thermal Rescue)** — 100µF tantalum power tank on 5V_SYS; 10kΩ NTC thermistor on IP5328P; BLM18 ferrite bead + 1nF EMI filter on BTL audio outputs; SD_MODE pull-up corrected to VDDIO (3V3_SYS); spi-gpio kernel driver mandate for CC1101.
**ECO #2026-03-H (Pin Mapping & Power Tuning)** — IP5328P I2C telemetry migrated from I2C0 pins 27/28 (disconnected on Zero 3W) to I2C1 pins 3/5 (Always-On); pins 27/28 tied to GND (NC); ISET 27kΩ→13kΩ (~500mA per Stinger port); SPI3/I2S0 no-overlap pin lock documented.
**ECO #2026-03-GOLD (Golden Master Cleanup)** — ESP32 removed from `audio_subsystem.py` (Radxa Zero 3W is I2S master via shared net names); LM1117-3.3 → AP2112K-3.3 LDO (250mV dropout vs 1.25V, SOT-23-5, 600mA, always-on EN pin); RF Pi-network parts explicitly named `C_RF1`/`L_RF1`/`C_RF2` for BOM traceability; `gen_golden_netlist.py` fully synchronized to current netlist state (17 stale nets, 8 stale components, 11 wrong header pins corrected).

---

## Table of Contents

1. [Nervous System Map – 40-Pin Radxa Header](#1-nervous-system-map--40-pin-radxa-header)
2. [Bus Topology – SPI, I2C, I2S](#2-bus-topology)
3. [Power Budget](#3-power-budget)
4. [Hacker Block – External Connector Pinouts](#4-hacker-block--external-connector-pinouts)
5. [Differential Pair Signal Integrity Constraints](#5-differential-pair-signal-integrity-constraints)
6. [Critical Warnings & Design Advisories](#6-critical-warnings--design-advisories)

---

## 1. Nervous System Map – 40-Pin Radxa Header

**Source:** `_build_radxa_header()` in `netlist/full_system.py`.

The connector is a standard 2×20 P2.54mm right-angle header, Raspberry-Pi
HAT-compatible. The table below is authoritative for the _netlist_; SoC
pin-mux is not modelled (see §6 Advisory A-1).

```
╔════╦═══════════════════════════════════════╦════════════════════════════════════════╦════╗
║ #  ║  Net (odd column / left)              ║  Net (even column / right)             ║ #  ║
╠════╬═══════════════════════════════════════╬════════════════════════════════════════╬════╣
║  1 ║  3V3_SYS   (power out from Radxa)     ║  5V_SYS    (IP5328P VOUT via J2)       ║  2 ║
║  3 ║  I2C1_SDA  (general I2C bus)          ║  5V_SYS    (second 5V supply pin)      ║  4 ║
║  5 ║  I2C1_SCL  (general I2C bus)          ║  GND                                   ║  6 ║
║  7 ║  SCREEN_BL (GPIO4, hardware PWM)      ║  STINGER_FLAG_2 (SY6280 port 2 FLAG)   ║  8 ║
║  9 ║  GND                                  ║  STINGER_FLAG_3 (SY6280 port 3 FLAG)   ║ 10 ║
║ 11 ║  STINGER_FLAG_1  (SY6280 port 1 FLAG) ║  I2S_BCLK  (audio bit clock)           ║ 12 ║
║ 13 ║  RF_MOSI   → CC1101 SI (SoftSPI)      ║  GND                                   ║ 14 ║
║ 15 ║  RF_MISO  ← CC1101 SO (SoftSPI)       ║  RF_CLK    → CC1101 SCLK (SoftSPI)     ║ 16 ║
║ 17 ║  3V3_SYS   (second 3.3V supply pin)   ║  RF_CS_N   → CC1101 CSN (SoftSPI)      ║ 18 ║
║ 19 ║  SPI3_MOSI → ST7789V2 SDA             ║  GND                                   ║ 20 ║
║ 21 ║  SPI3_MISO (ST7789V2 write-only)      ║  SCREEN_RST → ST7789V2 reset           ║ 22 ║
║ 23 ║  SPI3_CLK  → ST7789V2 SCL             ║  SPI3_CS → ST7789V2 chip select        ║ 24 ║
║ 25 ║  GND                                  ║  GND  (NC; was RF_CS_N; ECO #2026-03-F) ║ 26 ║
║ 27 ║  NC/GND (was I2C0_SDA; ECO #2026-03-H) ║  NC/GND (was I2C0_SCL; ECO #2026-03-H) ║ 28 ║
║ 29 ║  STINGER_EN_1 → SY6280 port 1 EN      ║  GND                                   ║ 30 ║
║ 31 ║  STINGER_EN_2 → SY6280 port 2 EN      ║  SCREEN_DC → ST7789V2 D/C control      ║ 32 ║
║ 33 ║  STINGER_EN_3 → SY6280 port 3 EN      ║  GND                                   ║ 34 ║
║ 35 ║  I2S_LRCLK (I2S exclusively)          ║  LED_DIN   → WS2812B data chain        ║ 36 ║
║ 37 ║  JOY_SW    (GPIO – joystick button)   ║  I2S_DATA_IN  ← INMP441 mic output     ║ 38 ║
║ 39 ║  GND                                  ║  I2S_DATA_OUT → MAX98357A amp input     ║ 40 ║
╚════╩═══════════════════════════════════════╩════════════════════════════════════════╩════╝
```

### Pin Function Summary

| Pin | Net Name | Function | Connected To |
|-----|---|---|---|
| 1 | 3V3_SYS | Power | Radxa 3.3V output; feeds all 3.3V on-board devices |
| 2 | 5V_SYS | Power | IP5328P VOUT (via J2); feeds SY6280 IN, USB hub VBUS |
| 3 | I2C1_SDA | I2C1 data | ADS1015 ADC (joystick) + IP5328P SDA telemetry via 470Ω (ECO #2026-03-H) |
| 4 | 5V_SYS | Power | Second 5V supply pin |
| 5 | I2C1_SCL | I2C1 clock | ADS1015 ADC (joystick) + IP5328P SCL telemetry via 470Ω (ECO #2026-03-H) |
| 6 | GND | Ground | — |
| 7 | SCREEN_BL | PWM output | ST7789V2 backlight; GPIO4 (hardware PWM capable) |
| 8 | STINGER_FLAG_2 | GPIO input | SY6280 port 2 FLAG (displaced from pin 13; ECO #2026-03-F) |
| 9 | GND | Ground | — |
| 10 | STINGER_FLAG_3 | GPIO input | SY6280 port 3 FLAG (displaced from pin 15; ECO #2026-03-F) |
| 11 | STINGER_FLAG_1 | GPIO input | SY6280 port 1 FLAG (open-drain, active-low) |
| 12 | I2S_BCLK | I2S clock | MAX98357A BCLK, INMP441 SCK |
| 13 | RF_MOSI | SoftSPI data out | CC1101 SI (moved from UART pin 8; ECO #2026-03-F) |
| 14 | GND | Ground | — |
| 15 | RF_MISO | SoftSPI data in | CC1101 SO (moved from UART pin 10; ECO #2026-03-F) |
| 16 | RF_CLK | SoftSPI clock | CC1101 SCLK (moved from pin 32; RF_GDO0 off header; ECO #2026-03-F) |
| 17 | 3V3_SYS | Power | Second 3.3V supply pin |
| 18 | RF_CS_N | SPI CS | CC1101 CSN chip select (moved from pin 26; ECO #2026-03-F) |
| 19 | SPI3_MOSI | SPI MOSI | ST7789V2 SDA (SPI3 hardware, display only) |
| 20 | GND | Ground | — |
| 21 | SPI3_MISO | SPI MISO | Available; ST7789V2 is write-only |
| 22 | SCREEN_RST | GPIO output | ST7789V2 hardware reset (active-low) |
| 23 | SPI3_CLK | SPI clock | ST7789V2 SCL (SPI3 hardware, display only) |
| 24 | SPI3_CS | SPI CS | ST7789V2 chip select (active-low; SPI3_CS0) |
| 25 | GND | Ground | — |
| 26 | GND | Ground | NC/GND (was RF_CS_N; Radxa SoC pin NC; ECO #2026-03-F) |
| 27 | GND | NC/GND | Disconnected on Zero 3W SoC; tied to GND (ECO #2026-03-H) |
| 28 | GND | NC/GND | Disconnected on Zero 3W SoC; tied to GND (ECO #2026-03-H) |
| 29 | STINGER_EN_1 | GPIO output | SY6280 port 1 EN (high=on; 10kΩ pull-up to 3V3) |
| 30 | GND | Ground | — |
| 31 | STINGER_EN_2 | GPIO output | SY6280 port 2 EN |
| 32 | SCREEN_DC | GPIO output | ST7789V2 Data/Command select (moved from pin 18; ECO #2026-03-F) |
| 33 | STINGER_EN_3 | GPIO output | SY6280 port 3 EN |
| 34 | GND | Ground | — |
| 35 | I2S_LRCLK | I2S clock | I2S3_LRCK_M0 exclusively |
| 36 | LED_DIN | GPIO output | WS2812B addressable LED data chain DIN (ECO #2026-02-V2) |
| 37 | JOY_SW | GPIO input | Joystick button (10kΩ pull-up to 3V3; active-low) |
| 38 | I2S_DATA_IN | I2S data | INMP441 microphone serial data output → Radxa |
| 39 | GND | Ground | — |
| 40 | I2S_DATA_OUT | I2S data | MAX98357A amplifier serial data input ← Radxa |

---

## 2. Bus Topology

### 2.1 SPI Buses

**SPI architecture:** Two segregated buses prevent CS assertion conflicts between
the ST7789V2 display and the CC1101 RF transceiver. CAN bus (MCP2515) removed per
ECO #2026-02-V2. SPI bus corrected to **SPI3** (Radxa Zero 3W hardware designation
for pins 19/21/23/24; was incorrectly labelled SPI0 in prior revisions).

#### SPI3 (Hardware SPI — display only)

```
Radxa SPI3 Master
      │
      ├── CLK  (pin 23 / SPI3_CLK)  ─────────────────────────────┐
      │                                                            │
      ├── MOSI (pin 19 / SPI3_MOSI) ─────────────────────────────┤
      │                                                            │
      └── MISO (pin 21 / SPI3_MISO) ─────────────────────────────┤
                                                                   │
          ┌────────────────────────────────────────────┐          │
          │         SPI Device          │  CS Net       │  CS Pin  │
          ├─────────────────────────────┼───────────────┼──────────┤
          │  ST7789V2  (SPI display)    │  SPI3_CS      │  pin 24  │
          └─────────────────────────────┴───────────────┴──────────┘

COLLISION CHECK: 1 device on SPI3. No contention possible.
```

#### SoftSPI / RF Bus (Bit-banged — CC1101 only; ECO #2026-03-F: migrated to safe GPIOs)

ECO #2026-03-E renamed SOFT_SPI_* → RF_*. ECO #2026-03-F moved all RF signals off
UART pins 8/10 (boot-console TX/RX) to safe GPIOs that do not conflict with OS boot.

```
Radxa GPIO (bit-banged)
      │
      ├── SCK  (pin 16 / RF_CLK)  ──────────────────────────────┐
      │                                                           │
      ├── MOSI (pin 13 / RF_MOSI) ──────────────────────────────┤
      │                                                           │
      └── MISO (pin 15 / RF_MISO) ──────────────────────────────┤
                                                                  │
          ┌────────────────────────────────────────────┐         │
          │         SPI Device          │  CS Net       │  CS Pin │
          ├─────────────────────────────┼───────────────┼─────────┤
          │  CC1101    (Sub-GHz RF)     │  RF_CS_N      │  pin 18 │
          └─────────────────────────────┴───────────────┴─────────┘

RF_GDO0 is NOT connected to any header pin (CC1101 operates in polling mode).
Pins 8/10 (freed from RF) now carry STINGER_FLAG_2/FLAG_3.

FIRMWARE MANDATE (ECO #2026-03-G): Use the Linux kernel 'spi-gpio' driver,
NOT userspace bit-banging (spidev/GPIO sysfs). Userspace scheduler round-trips
introduce >10µs jitter, violating CC1101 SPI timing (t_SCLK_min = 50ns).
Device-tree overlay: spi-gpio sck=GPIO16, mosi=GPIO13, miso=GPIO15.
```

**Voltage domains on SPI buses:**
- ST7789V2 — 3.3V logic (SPI3; VDD = 3V3_SYS)
- CC1101    — **3V3_CLEAN** (VDD = vcc_clean; AP2112K-3.3 LDO isolated rail, 250mV dropout; bus renamed RF_CLK/RF_MOSI/RF_MISO; ECO #2026-03-GOLD) ✓

### 2.2 I2C Buses

```
  I2C1  ──  SDA (pin 3),  SCL (pin 5)   → ADS1015 ADC (joystick VRX/VRY)
                                         → [470Ω] → I2C1_PMIC_SDA / I2C1_PMIC_SCL → IP5328P

  I2C0  ──  pins 27/28  NC/GND  (Zero 3W SoC lines disconnected; ECO #2026-03-H)
```

**ECO #2026-03-H I2C migration:** The IP5328P I2C telemetry was originally on I2C0
(pins 27/28) but those SoC pads are unconnected on the Radxa Zero 3W. Telemetry is
now on I2C1 (pins 3/5), the board's "Always-On" I2C bus shared with the ADS1015.
The two devices have different I2C addresses and coexist without conflict.

**ECO #2026-03-F / H series protection:** 470Ω resistors (`r_i2c_sda`, `r_i2c_scl`)
sit between pins 3/5 and the IP5328P. Protected-side nets are `I2C1_PMIC_SDA` and
`I2C1_PMIC_SCL`. This prevents the IP5328P internal pull-ups from back-driving the
Radxa I2C bus when the CPU is unpowered (latch-up mitigation; see RESOLVED A-9).

### 2.3 I2S Bus

Source: `audio_subsystem.py` (separate netlist, `daemon_v0_audio.net`).
The four I2S nets are also broken out on the Radxa header in `full_system.py`.

```
  Radxa I2S Master
        │
        ├── I2S_BCLK     (pin 12)  ──►  MAX98357A BCLK,  INMP441 SCK
        ├── I2S_LRCLK    (pin 35)  ──►  MAX98357A LRC,   INMP441 WS
        ├── I2S_DATA_OUT (pin 40)  ──►  MAX98357A DIN
        └── I2S_DATA_IN  (pin 38)  ◄──  INMP441 SD

  Topology: parallel clock (MAX98357A and INMP441 share BCLK and LRCLK).
  MAX98357A does not require MCLK.
  INMP441 L/R pin pulled low → left-channel output selected.
```

### 2.4 USB Topology

```
  Goobay 74446 USB-C receptacle (B.Cu, 8.85mm pitch)
       │  USB_UP_DP / USB_UP_DM
       ▼
  SL2.1A USB 2.0 Hub (QFN-28)
       │
       ├── Port 1  DP1/DM1  →  SY6280 #1  →  USB-A Stinger Port 1
       ├── Port 2  DP2/DM2  →  SY6280 #2  →  USB-A Stinger Port 2
       ├── Port 3  DP3/DM3  →  SY6280 #3  →  USB-A Stinger Port 3
       └── Port 4  DP4/DM4  →  RTL8152B   →  HanRun HR911105A RJ45
```

---

## 3. Power Budget

**Architecture (ECO #2026-03-G/GOLD):** IP5328P (QFN-40) boost converter supplies
5V_SYS. The Radxa SBC consumes 5V from the header (pins 2 and 4) and generates
3V3_SYS internally. An AP2112K-3.3 LDO (`_build_clean_3v3_rail`, SOT-23-5, 250mV
dropout, 600mA) derives 3V3_CLEAN from 5V_SYS for RF + Ethernet isolation. 3× SY6280 Stinger ports are
hardware-limited to **~500 mA each** via 13kΩ ISET resistors (ECO #2026-03-H). A 100µF tantalum
capacitor on 5V_SYS absorbs 4A transients; a 10kΩ NTC thermistor on the IP5328P
NTC pin provides hardware thermal throttling above Tj = 120°C.

**IP5328P capability:**
- Continuous output: ≥3A (vs. IP5306 derated 1.5A)
- Boost inductor: 4.7µH, **MPN: TDK VLF12560T-4R7M7R9** (Isat = 7.9A, Idc = 5.0A) — see RESOLVED A-20
- I2C telemetry on I2C1 (pins 3/5) for runtime PMIC monitoring (ECO #2026-03-H)
- NTC thermistor (10kΩ, `IP5328P_NTC` net → GND) for hardware thermal protection (ECO #2026-03-G)
- 100µF 6.3V tantalum (Case-B) on 5V_SYS bus for transient suppression (ECO #2026-03-G)

### 3.1 5V_SYS Direct Consumers

| Consumer | Typical (mA) | Peak (mA) | Source |
|---|---|---|---|
| Radxa SBC (CPU + memory + I/O) | 500 | 900 | typical SBC @ moderate load |
| AP2112K-3.3 LDO (3V3_CLEAN rail load) | 25 | 50 | RF consumer below |
| 3× SY6280 (quiescent, no USB load) | 0.3 | 1 | SOT-23-5 quiescent |
| WS2812B × 4 (all white full brightness) | 240 | 240 | 60mA each |
| NE555 heartbeat dummy load (61mA × 0.07% duty) | 4 avg | 61 (pulse) | r_dummy = "82", 5V/82Ω |
| IP5328P internal quiescent | 5 | 10 | datasheet |
| **5V subtotal (no USB devices on Stinger ports)** | **~775** | **~1260** | |

### 3.2 3V3_CLEAN Consumers (AP2112K-3.3 LDO rail — RF + Ethernet)

ECO #2026-03-F: RTL8152B VCC now sourced from `vcc_clean` instead of `vcc_3v3` (Radxa
3.3V switching regulator, insufficient for 80mA USB-Ethernet peak). ECO #2026-03-GOLD:
LDO upgraded from LM1117-3.3 (1.25V dropout, 800mA) to AP2112K-3.3 (250mV dropout,
600mA, SOT-23-5). The 250mV dropout ensures 3V3_CLEAN stays above 3.1V even when
5V_SYS sags to 3.35V — the previous LM1117 would brown out CC1101 in this scenario.
All RF and Ethernet components share this isolated, low-noise LDO rail.

| Consumer | Typical (mA @ 3.3V) | Source |
|---|---|---|
| CC1101 (RX mode) | 16 | CC1101 datasheet Rev. E |
| CC1101 (TX mode, +10 dBm) | 30 | CC1101 datasheet |
| RTL8152B (USB-Ethernet) | 80 | RTL8152B datasheet (ECO #2026-03-F: moved here from 3V3_SYS) |
| **3V3_CLEAN subtotal** | **~110 (TX+ETH)** | AP2112K-3.3 rated 600mA; 490mA headroom ✓ |

### 3.3 3V3_SYS Consumers (indirect 5V load via Radxa regulator)

Assume Radxa DC-DC efficiency η = 0.88 (conservative).
Reflected 5V current = (I_3V3 × 3.3V) / (5.0V × η).

| Consumer | Typical (mA @ 3.3V) | Source |
|---|---|---|
| SL2.1A USB hub (VDD33 = vcc_3v3) | 30 | SL2.1A datasheet |
| ST7789V2 display core (1.69″) | 10 | ST7789V2 datasheet |
| ST7789V2 backlight (LED) | 60 | typical 1.69″ module |
| ISO1212 logic side (VCC2 = vcc_3v3) | 5 | ISO1212 datasheet |
| ADS1015 ADC (joystick) | 1 | ADS1015 datasheet |
| INMP441 microphone | 1.4 | INMP441 datasheet |
| Pull-up resistors + misc passives | 5 | estimated |
| **3.3V subtotal** | **~112** | |
| **Reflected to 5V_SYS** | **~84** | via Radxa reg |

### 3.4 Total 5V_SYS Budget

**ECO #2026-03-H: Stinger ports hardware-limited to ~500 mA each (ISET = 13kΩ, R_ISET = 6800/I_OC).**
(Previously 27kΩ = 250mA, ECO #2026-03-E; increased to allow modern USB peripherals at full current draw.)

```
Scenario                                  5V Current   Margin vs. IP5328P 3A limit
──────────────────────────────────────────────────────────────────────────────────
Idle (Radxa at rest, no USB devices)        ~450 mA     2550 mA headroom  ✓
Active (Radxa loaded, RF RX, Ethernet)      ~960 mA     2040 mA headroom  ✓
Active + 1 USB device at 500 mA (ISET)    ~1460 mA     1540 mA headroom  ✓
Active + 2 USB devices at 500 mA ea       ~1960 mA     1040 mA headroom  ✓
Active + 3 USB devices at 500 mA ea       ~2460 mA      540 mA headroom  ✓
```

> ✅ **PDN-BUDGET-01 RESOLVED** — IP5328P + 13kΩ ISET limiting prevents brownout
> at all populated-port scenarios. All remain within the 3A continuous output
> capability of the IP5328P with >540 mA headroom at worst-case full load.

### 3.5 Thermal Budget — Pocket Environment

> ⚠ **BRINGUP NOTE:** The Daemon V0 is intended to be used in a pocket or enclosed
> bag. The RK3566 SBC relies on convection cooling only; there is no heatsink.

**Conservative thermal model (pocket, still air):**
- Effective junction-to-ambient: R_θja_eff ≈ 70°C/W (still-air pocket vs. datasheet 45°C/W open bench)
- Ambient in pocket: T_amb ≈ 37°C (body temperature)
- RK3566 Tjmax = 87°C (throttle onset); absolute max = 125°C
- Maximum sustainable power dissipation: ΔT / R_θja = (87 − 37) / 70 ≈ **0.71 W**

**Observed RK3566 idle dissipation: ~0.5–0.8 W**

This means the SBC is near its thermal ceiling in a pocket environment even at idle.
The hardware will **not** be destroyed — the RK3566 DVFS governor throttles CPU frequency
automatically at Tj = 85°C (reduces power to ~0.3W) — but sustained compute workloads
will be continuously throttled.

**Firmware implication:** Maximum continuous CPU load must stay below approximately
**60% of base clock** in a pocket environment to avoid DVFS intervention. Burst loads
(scanning, packet bursts) are acceptable; continuous high-load loops are not.

---

## 4. Hacker Block – External Connector Pinouts

### 4.1 Auxiliary GPIO Header (4-pin, 2.54mm pitch)

**Footprint:** `FP_CONN_1X04_254` =
`Connector_PinHeader_2.54mm:PinHeader_1x04_P2.54mm_Vertical`

**Source:** `generate_daemon_v0_full_system()` in `full_system.py` (ECO #2026-02-V2):
```python
aux_hdr[1] += iso_do1     # ISO1212 OUT1 (3.3V CMOS logic)
aux_hdr[2] += iso_do2     # ISO1212 OUT2 (3.3V CMOS logic)
aux_hdr[3] += ir_gpio     # IR blaster gate drive (active-high)
aux_hdr[4] += gnd
```

```
┌───────────────────────────────────────────────────────┐
│  Pin  │  Net         │  Signal Description             │
├───────┼──────────────┼─────────────────────────────────┤
│   1   │  ISO_DO1     │  ISO1212 OUT1 – 3.3V CMOS;      │
│       │              │  logical representation of       │
│       │              │  industrial IN1 field signal     │
├───────┼──────────────┼─────────────────────────────────┤
│   2   │  ISO_DO2     │  ISO1212 OUT2 – 3.3V CMOS;      │
│       │              │  logical representation of       │
│       │              │  industrial IN2 field signal     │
├───────┼──────────────┼─────────────────────────────────┤
│   3   │  IR_GPIO     │  IR blaster gate drive;          │
│       │              │  active-high → AO3400A gate →    │
│       │              │  VSMB294008 IR LED (~106 mA)     │
├───────┼──────────────┼─────────────────────────────────┤
│   4   │  GND         │  PCB ground reference            │
└───────┴──────────────┴─────────────────────────────────┘
```

### 4.2 ISO1212 Field-Side Terminal Block (4-position, WAGO 2060-404)

**Footprint:** `FP_WAGO_4P` =
`TerminalBlock_WAGO:TerminalBlock_WAGO_2060-404_1x04_P3.50mm_Horizontal`

**ECO #2026-02-V2:** Pin-header replaced with WAGO 2060-404 screw-less
push-in terminal block (3.5mm pitch) for industrial field wiring.

**Source:** `_build_industrial_iso()` in `full_system.py`:
```python
field_conn[1] += gnd1     # ISO_GND1    – isolated field ground
field_conn[2] += vcc1     # ISO_VCC1    – 8–35V field supply
field_conn[3] += in1_raw  # ISO_IN1_RAW – raw input ch1 (before protection chain)
field_conn[4] += in2_raw  # ISO_IN2_RAW – raw input ch2 (before protection chain)
```

```
┌───────────────────────────────────────────────────────────────────────┐
│  Pos  │  Net          │  Description                                  │
├───────┼───────────────┼───────────────────────────────────────────────┤
│   1   │  ISO_GND1     │  Isolated field ground (≥2.5kV from PCB GND; │
│       │               │  do NOT connect to system GND)                │
├───────┼───────────────┼───────────────────────────────────────────────┤
│   2   │  ISO_VCC1     │  Field supply (8–35V PLC output)              │
├───────┼───────────────┼───────────────────────────────────────────────┤
│   3   │  ISO_IN1_RAW  │  PLC digital output → ch1 (enters protection  │
│       │               │  chain before ISO1212 IN1)                    │
├───────┼───────────────┼───────────────────────────────────────────────┤
│   4   │  ISO_IN2_RAW  │  PLC digital output → ch2                    │
└───────┴───────────────┴─────────────────────────────────────────────-─┘
```

**IND-SAF-01 Per-channel input protection chain (both channels identical):**

```
Connector pin → [Littelfuse 60R PTC] ─┬─[Vishay VCAN26A2 TVS]─→ ISO_GND1
                                       │   (26V clamp; EN 61000-4-5)
                                       └─[562Ω 1%]─┬─[1kΩ 1%]─→ ISO_GND1
                                                    │  (IEC 61131-2 threshold)
                                                    ├─[10nF 100V X7R]─→ ISO_GND1
                                                    │  (HF noise filter)
                                                    └─→ ISO1212 INx
```

ISO_GND1 is strictly isolated from PCB GND throughout. All protection
components connect to ISO_GND1 (field ground), not GND (board ground).

### 4.3 Stinger Port USB-A Connectors (× 3)

Each Stinger port exposes a standard USB-A receptacle. Power is gated by a
SY6280AAC per port. Data is routed from SL2.1A downstream pairs 1–3.

```
┌────────────────────────────────────────────────────────────────┐
│  Port  │  VBUS net    │  D+ net        │  D− net        │  EN  │
├────────┼──────────────┼────────────────┼────────────────┼──────┤
│   1    │  USB_VBUS_1  │  USB_DN_DP_1   │  USB_DN_DM_1   │ pin 29│
│   2    │  USB_VBUS_2  │  USB_DN_DP_2   │  USB_DN_DM_2   │ pin 31│
│   3    │  USB_VBUS_3  │  USB_DN_DP_3   │  USB_DN_DM_3   │ pin 33│
└────────┴──────────────┴────────────────┴────────────────┴──────┘
```

### 4.4 Ethernet RJ45 (HanRun HR911105A MagJack)

SL2.1A hub port 4 feeds the RTL8152B USB-to-100Base-TX Ethernet chip.
The HanRun HR911105A MagJack provides integrated magnetics and LED indicators.

```
┌───────────────────────────────────────────────────────────────────────┐
│  RJ45 Pin │  Net          │  Description                              │
├───────────┼───────────────┼───────────────────────────────────────────┤
│     1     │  ETH_MDI_TXP  │  TX+ (transmit)                          │
│     2     │  ETH_MDI_TXN  │  TX− (transmit)                          │
│     3     │  ETH_MDI_RXP  │  RX+ (receive)                           │
│     4     │  3V3_SYS      │  CT1 TX center tap → 3V3 bias (ECO-03-E) │
│     5     │  3V3_SYS      │  CT2 RX center tap → 3V3 bias (ECO-03-E) │
│     6     │  ETH_MDI_RXN  │  RX− (receive)                           │
└───────────┴───────────────┴───────────────────────────────────────────┘
```

---

## 5. Differential Pair Signal Integrity Constraints

**Source:** `layout/configure_constraints.py`

Two net classes are injected into the KiCad board by
`configure_high_speed_differential_pairs()`. A `.kicad_dru` custom-rules file
is also generated by `_write_kicad_dru()` for DRC enforcement.

### 5.1 DIFF_USB_90 — USB 2.0 High-Speed (SL2.1A upstream/downstream)

```python
USB_90_CLASS = DiffPairNetClass(
    name            = "DIFF_USB_90",
    trace_width_mm  = 0.15,
    clearance_mm    = 0.15,
    diff_pair_gap_mm= 0.15,
    nets            = ["USB_D_P", "USB_D_N"],
    skew_limit_ps   = 100.0,   # SI-USB-02
)
```

| Parameter | Value | Basis |
|---|---|---|
| Trace width | 0.15 mm | JLC04161H-3313 stackup: w=0.15mm, gap=0.15mm → Zdiff ≈ 90Ω |
| Intra-pair gap | 0.15 mm | — |
| Clearance | 0.15 mm | to adjacent copper |
| Max skew | 100 ps | SI-USB-02: 480 Mbps HS requirement |
| Max length delta | ≈14.81 mm | 100ps × v_FR4 (v = c/√4.1 ≈ 148.06 mm/ns) |

### 5.2 DIFF_ETH_100 — Ethernet MDI (RTL8152B → HR911105A)

```python
ETH_100_CLASS = DiffPairNetClass(
    name            = "DIFF_ETH_100",
    trace_width_mm  = 0.15,
    clearance_mm    = 0.20,
    diff_pair_gap_mm= 0.20,
    nets            = ["ENET_TRD0_P", "ENET_TRD0_N"],
    skew_limit_ps   = 0.0,
)
```

No strict intra-pair skew spec at 10/100 Mbps Ethernet speeds. The
`.kicad_dru` file will not emit a `diff_pair_skew` rule for this class.

### 5.3 Post-Route CI Validation

`validate_ses_intra_pair_skew()` in `layout/freerouting_dsn.py` parses the
FreeRouting output `.ses` file and asserts:

```
abs(len(USB_D_P) − len(USB_D_N)) × (1 / FR4_PROPAGATION_MM_PER_PS) ≤ 100 ps
```

If violated, it raises `AssertionError` with tag `[FAIL] SI-USB-02`, blocking
the CI pipeline from advancing to the fabrication phase.

---

## 6. Critical Warnings & Design Advisories

---

### ✅ RESOLVED PDN-BUDGET-01: 5V Current Budget — IP5328P + ISET Hardening

**Original finding:** IP5306 thermally derated to 1.5A; full-load Stinger use
exceeded this by up to 870 mA, causing OTP reboot of the entire board.

**Resolution (Phase 1 + ECO #2026-03-E):**
- **IP5306 → IP5328P (QFN-40):** continuous output ≥3A; 4.7µH Isat >5A inductor.
- **ISET hardware limiting (ECO #2026-03-E):** each SY6280 Stinger port limited to 250 mA via
  `iset_res = Resistor(value="27k")` (formula: R = 6800 / 0.25A = 27.2kΩ → 27kΩ E96).
  Previous value was 17kΩ (400 mA); reduced to prevent brownout when all 3 Stinger ports
  are populated simultaneously with the Radxa + RF + Ethernet load.
- **Result:** worst-case all-ports-loaded current is ~1710 mA — 1290 mA under the
  IP5328P 3A continuous limit. No OTP risk at any populated-port scenario.

**Source:** `_build_power_system()` and `_build_stinger_port()` in `full_system.py`.

---

### ✅ RESOLVED IND-SAF-01: ISO1212 Input Transient Hardening

**Resolution:** Per-channel protection chain inserted in `_build_industrial_iso()`:

| Stage | Component | Purpose |
|---|---|---|
| Series PTC | Littelfuse 60R (`Polyfuse`, `FP_PTC_1206`) | Limits sustained fault current; self-resetting |
| Shunt TVS | Vishay VCAN26A2 (`D_TVS`, `FP_TVS_SMB`) | Clamps transient overvoltages to ~26V at field node |
| Series R | 562Ω 1% | Limits steady-state input current to IC |
| Threshold R | 1kΩ 1% | Sets IEC 61131-2 switching threshold; bleeds static |
| Filter C | 10nF 100V X7R | Suppresses HF transient noise at IC input pin |

ISO_GND1 remains strictly isolated from PCB GND throughout all protection stages.

---

### ✅ RESOLVED A-3: CC1101 RF Front-End — Chip Antenna (ECO #2026-02-V2)

**Previous state:** Discrete L-C balun + SMA coaxial connector on RF_P/RF_N.

**Resolution (ECO #2026-02-V2):** SMA connector and balun removed. Replaced with
Johanson Technology 0915AT43A0026 chip antenna (915 MHz optimised) and Pi-network
matching circuit:

```
CC1101 RF_P ─┬─[C_RF1: 0.5pF shunt → GND]─[L_RF1: 10nH series]─┬─ Chip Antenna
              │                                                     │
              │                                      [C_RF2: 4.7pF shunt → GND]
CC1101 RF_N ─[C_RFN: 1pF → GND]  (single-ended termination)
```

**ECO #2026-03-GOLD:** Pi-network parts renamed from `c_pi1`/`l_pi`/`c_pi2` to `C_RF1`/`L_RF1`/`C_RF2`
for explicit BOM traceability (see RESOLVED A-19).

**Source:** `_build_rf_transceiver()` in `full_system.py`; footprint `FP_CHIP_ANT_915`.

---

### ⚠ ADVISORY A-1: I2S_LRCLK / ADS1015 Pin-Mux (Pin 35)

**Finding:** Pin 35 (I2S3_LRCK_M0) is netlist-connected to `I2S_LRCLK` for
audio. The joystick VRX/VRY are offloaded to the ADS1015 ADC on I2C1 to free
pin 35 for exclusive I2S use (implemented in `_build_joystick()`).

**Status:** Resolved in firmware by ADS1015 offload. Audio and joystick can
now run concurrently since they use different buses (I2S vs I2C1).

---

### ⚠ ADVISORY A-2: WS2812B Data Signal Integrity (Pin 36)

**Location:** `_build_ws2812b_leds()`, `full_system.py`

The WS2812B chain uses a 800 kbit/s single-wire protocol with tight timing
tolerances (±150 ns on pulse widths). Pin 36 (GPIO16) on Radxa must be driven
by a DMA-capable or real-time PWM output to meet timing without software
jitter. Use `rpi_ws281x` or equivalent DMA-driven library in firmware.

A 33Ω series termination resistor at the Radxa GPIO output is recommended to
damp reflections; it is not modelled in the current netlist.

---

### ⚠ ADVISORY A-3: IR Blaster — AO3400A Driver + 33Ω Series Resistor (ECO #2026-03-A/F)

**Source:** `_build_ir_blaster()`, `full_system.py`

Series current-limiting resistor changed from 100Ω → 33Ω (ECO #2026-03-A) for long-range IR:

```
I_LED = (5V − 1.5V_f) / 33Ω ≈ 106mA (pulsed)
```

**ECO #2026-03-F:** Driver MOSFET upgraded from 2N7002 → **AO3400A** (N-channel, SOT-23).
The 2N7002 has a Vgs_th up to 2.5V and is only partially enhanced at 3.3V gate drive
(Rds_on degrades significantly). The AO3400A is a logic-level FET with Vgs_th = 0.45–1.0V
and Rds_on < 50mΩ at Vgs = 3.3V, ensuring full saturation at 3.3V GPIO drive levels.

Ensure firmware uses short duty cycles (<10% continuous) to stay within the VSMB294008
average power rating.

---

### ⚠ ADVISORY A-4: Ethernet MagJack / Goobay Bridge Clearance (ECO #2026-03-A)

**Source:** `_build_ethernet()`, `full_system.py`

The HanRun HR911105A MagJack has significant Z-height. The Goobay 74446 USB-C bridge
is mounted on B.Cu directly under the Radxa SBC. **Place the MagJack >15mm away from
the Goobay bridge** to prevent Z-axis mechanical collision.

---

### ⚠ ADVISORY A-5: Crystal Heterodyne — 25 MHz / 26 MHz Separation (ECO #2026-03-A)

**Source:** `_build_ethernet()` and `_build_rf_transceiver()`, `full_system.py`

The RTL8152B uses a 25 MHz crystal and the CC1101 uses a 26 MHz crystal. Their
1 MHz beat frequency can radiate from PCB traces and couple into the CC1101's
RF front-end, degrading sub-GHz receiver sensitivity.

**Layout rule:** Place the two crystals at least 10 mm apart. Surround each crystal
with a ring of ground vias (stitching pitch ≤ λ/20 at 26 MHz ≈ 230 mm; 2–3 mm
pitch is sufficient) to contain oscillator radiation.

---

### ℹ NOTE N-1: Audio Subsystem is a Separate Netlist

`netlist/audio_subsystem.py` generates `daemon_v0_audio.net` independently
from `daemon_v0_full_system.net`. The two netlists share net names
(`I2S_BCLK`, `I2S_DATA_IN`, `I2S_DATA_OUT`, `GND`, `3V3_SYS`) but are
**not automatically merged** by the build system. A KiCad hierarchical
sheet or manual net-merge step is required to produce a single board-level
schematic for DRC and layout.

**ECO #2026-03-GOLD — ESP32 removed:** The audio netlist previously
instantiated an `ESP32-WROOM-32` Part (`MCU_Espressif` library) as a
placeholder I2S master for netlist connectivity purposes. This was a legacy
artifact — the actual I2S master is the **Radxa Zero 3W** SBC. The ESP32 Part
has been removed; I2S connectivity is established by shared net names between
the two netlists (`I2S_BCLK` = Radxa pin 12, `I2S_LRCLK` = pin 35,
`I2S_DATA_IN` = pin 38, `I2S_DATA_OUT` = pin 40). No MCU Part instantiation
is needed in `audio_subsystem.py` (see RESOLVED A-17).

**ECO #2026-03-G audio signal chain (BTL output path):**

```
MAX98357A OUTP ──── AMP_OUT_P ──┬── [ESD9B5.0ST5G TVS → GND]  (SM-AUD-01 spike clamp)
                                 └── [BLM18 Ferrite Bead] ──── AMP_OUT_P_FILT ──┬── [1nF → GND]
                                                                                  └── TRRS TipSwitch → Speaker+

MAX98357A OUTN ──── AMP_OUT_N ──┬── [ESD9B5.0ST5G TVS → GND]  (SM-AUD-01 spike clamp)
                                 └── [BLM18 Ferrite Bead] ──── AMP_OUT_N_FILT ──┬── [1nF → GND]
                                                                                  └── TRRS Ring1Switch → Speaker−
```

**SD_MODE pull-up (SM-LOG-03 / ECO #2026-03-G):**
- `pullup_sd[1] → vcc_3v3 (3V3_SYS)` — VDDIO reference for the 633kΩ resistor formula
- Previously incorrectly wired to `vcc_5v`; formula uses V_DDIO = 3.3V so pull-up must match

**CI test coverage:** `tests/test_audio_subsystem.py` (9 tests, source-text inspection).

---

### ℹ NOTE N-2: RTL8152B Requires Daemon_V0 Custom Symbol

The RTL8152B is instantiated as `Part("Daemon_V0", "RTL8152B", ...)`. A custom
KiCad symbol with the correct QFN-32 pin mapping must be added to the
`Daemon_V0.kicad_sym` library before schematic export or ERC can pass. PSELF
is tied low (0Ω strap to GND) and XTALDET is tied high (0Ω strap to VCC)
to select external crystal + self-powered USB mode.

---

### ℹ NOTE N-3: Goobay 74446 Placement Constraint

The Goobay 74446 USB-C bridge must be placed on B.Cu (bottom copper) directly
below the Radxa SBC USB-C port with 8.85mm vertical pitch. Misplacement will
result in the U-shape bridge not mating with the Radxa connector. Mark this
component with a `DNI` rule if building without the Radxa SBC.

---

### ✅ RESOLVED A-6: Advanced Power UX — BSS84 Wake-Blocker + Software Kill (ECO #2026-03-D)

**Subsystem A6** replaces the now-removed HW-RST-01 reset button with a three-circuit
power management front-end (`_build_power_ux()`):

```
                            PMIC_KEY net
                                 │
         ┌───────────────────────┼──────────────────────┐
         │                       │                      │
   [BSS84 PMOS]           [2N7002 NMOS]           [SW_PWR button]
   S → KEY  D → JOY_SW    G → PMIC_KILL            shorts KEY to GND
   G → 5V_SYS              D → KEY
   (100kΩ pull-down G→GND) S → GND
```

| Circuit | Wake action | Active when |
|---|---|---|
| BSS84 wake-blocker | JOY_SW press wakes PMIC | 5V OFF (board sleeping) |
| BSS84 isolation | JOY_SW blocked from KEY | 5V ON (normal operation) |
| 2N7002 kill | Radxa GPIO pulls KEY low (double-tap) | Any time; software-controlled |
| SW_PWR button | KEY → GND; always-on hard press | Any time |

**SW_PWR_GPIO** taps the KEY net so Radxa can detect long-press for graceful OS shutdown.

**3-pin Power Management Header** (FP_CONN_1X03_254):
- Pin 1: PMIC_KILL — software shutdown GPIO
- Pin 2: SW_PWR_GPIO — long-press detect GPIO
- Pin 3: GND

**Source:** `_build_power_ux()` in `full_system.py`; `FP_PMOS_SOT23`.

---

### ✅ RESOLVED A-7: I2C Bus Clamping — Battery LED Removal (ECO #2026-03-E)

**Finding:** IP5328P LED1/LED2/LED3 indicator pins share the same ball-pad cluster
as the I2C SDA/SCL pins on some QFN-40 package revisions. 3.3kΩ pull-down
resistors on LED pins create a 1.5mA sink that can clamp SDA/SCL below V_IH
(≥0.7×VDD = 2.31V) at 3.3V I2C bus speed, preventing battery % readback.

**Resolution:** `r_led1/r_led2/r_led3` and `led1_net/led2_net/led3_net` deleted from
`_build_power_system()`. IP5328P `ic["LED1/2/3"]` connections removed.
IP5328P I2C telemetry is now on I2C1 (pins 3/5) at full speed (ECO #2026-03-H).

**Source:** `_build_power_system()` in `full_system.py`; ECO #2026-03-E.

---

### ℹ NOTE N-4: WS2812B Open-Drain Pull-Up (ECO #2026-03-E)

Radxa GPIO36 (LED_DIN) may be configured as open-drain by the OS driver. A 1kΩ
pull-up resistor (`din_pullup`) from LED_DIN to 5V_SYS ensures the idle/high state
reaches ≥3.5V (WS2812B V_IH minimum). Without this, the first LED in the chain may
misinterpret logic-high → all LEDs render incorrect colour on boot.

---

### ℹ NOTE N-5: Ethernet Center Tap Bias (ECO #2026-03-E)

HR911105A MagJack center taps (pins 4/5) connect to 3V3_SYS. This provides the
DC reference required by the 100Base-TX PHY magnetics. Without center tap bias,
the transformer cores have no DC operating point and PHY link negotiation fails.

---
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

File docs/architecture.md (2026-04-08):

# Daemon — Architecture v1

> **Status:** locked. Source of truth for all v1 work.
> **Date:** 2026-04-08
> **Positioning:** the Volvo of secure AI agent platforms. Open source, end-to-end verifiable, production-grade. The way most people will run Claude Code across their devices.

---

## 1. The four pillars (constraints, not features)

These are not "things we'll add later." They are constraints the architecture
must satisfy by construction. Anything that violates them is rejected,
including by us.
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

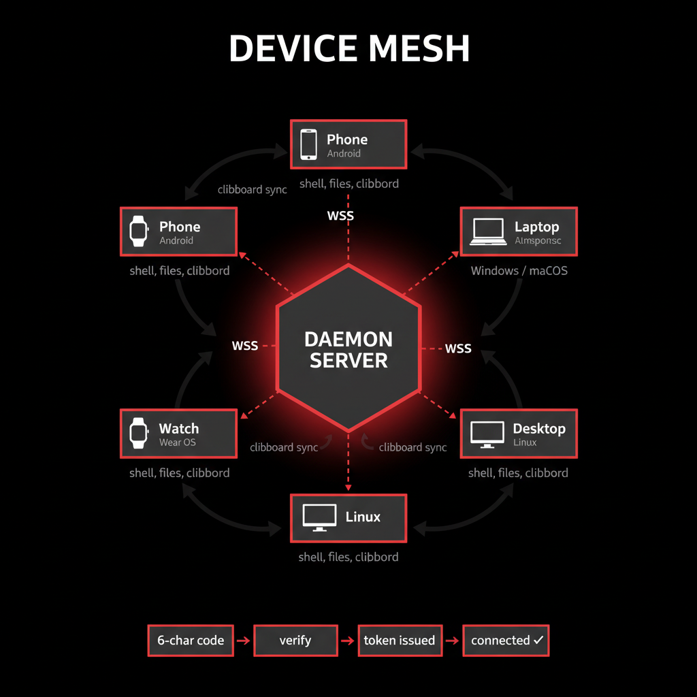
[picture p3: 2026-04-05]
docs/diagrams/device-mesh.png

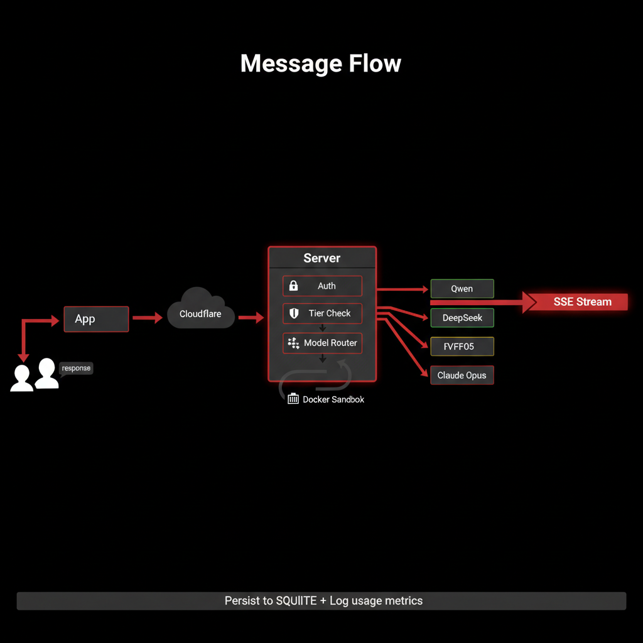
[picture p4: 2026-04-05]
docs/diagrams/chat-flow.png

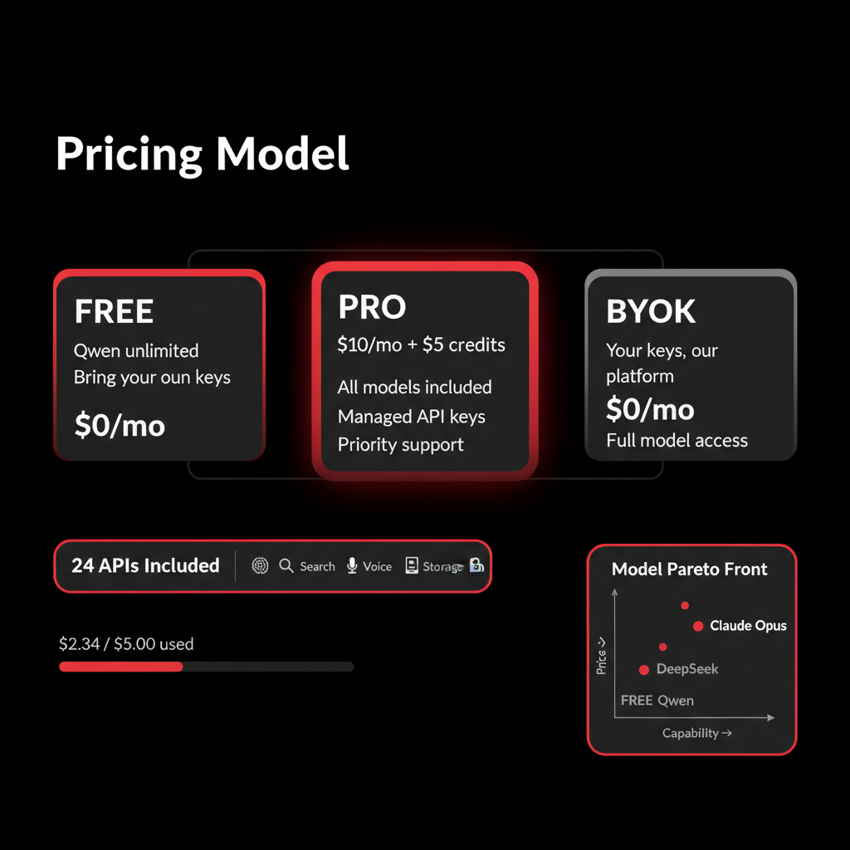
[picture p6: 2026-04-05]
docs/diagrams/billing.png

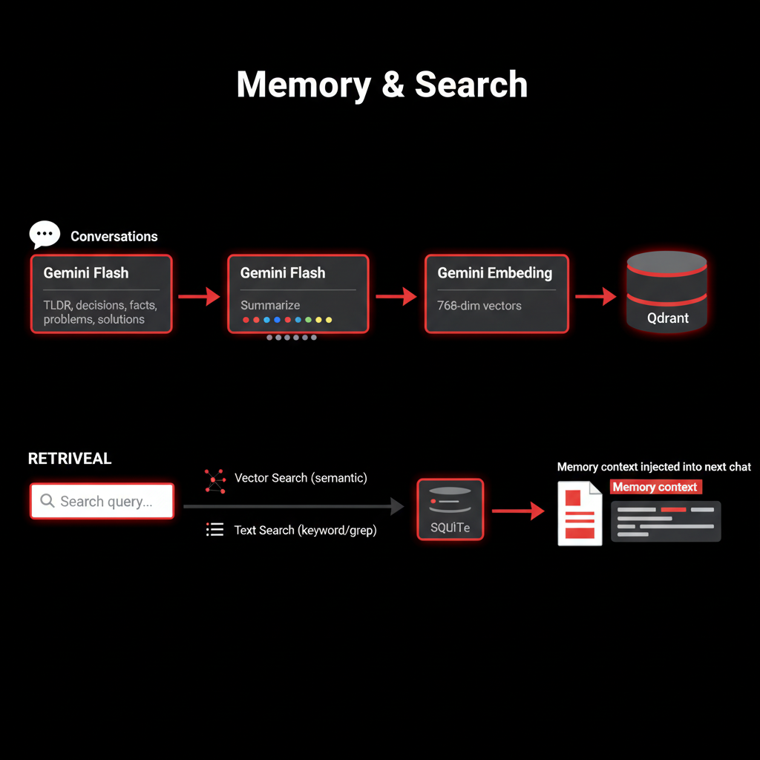
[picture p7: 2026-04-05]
docs/diagrams/memory-system.png

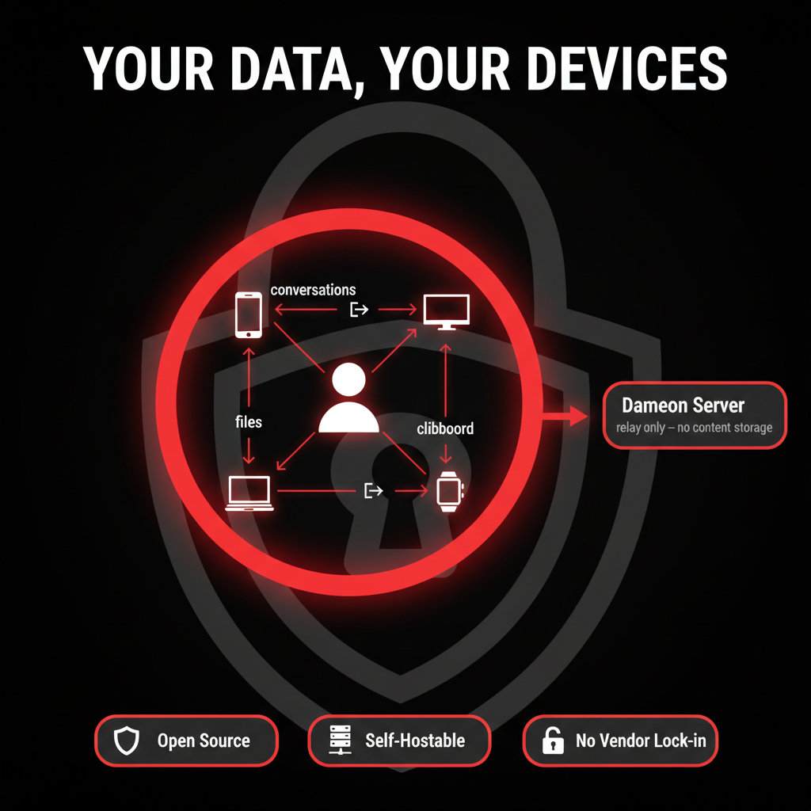
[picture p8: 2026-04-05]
docs/diagrams/data-sovereignty.png

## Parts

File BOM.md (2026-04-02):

# Daemon V0 — Bill of Materials

**Board revision:** ECO #2026-03-GOLD
**Source netlists:** `netlist/full_system.py`, `netlist/audio_subsystem.py`
**164/164 CI tests passing**

Components are grouped by subsystem. Quantities marked (×N) reflect loop-instantiated parts.

---

## Table of Contents

1. [Subsystem A — IP5328P Power Management](#subsystem-a--ip5328p-power-management)
2. [Subsystem A2 — AP2112K-3.3 Clean 3.3V LDO Rail](#subsystem-a2--ap2112k-33-clean-33v-ldo-rail)
3. [Subsystem A3 — USB Charging MUX (PDN-USB-01)](#subsystem-a3--usb-charging-mux-pdn-usb-01)
4. [Subsystem A5 — Goobay 74446 USB-C Bridge](#subsystem-a5--goobay-74446-usb-c-bridge)
5. [Subsystem A6 — Advanced Power UX](#subsystem-a6--advanced-power-ux)
6. [Subsystem B — Cascaded SL2.1A USB 2.0 Hubs](#subsystem-b--cascaded-sl21a-usb-20-hubs)
7. [Subsystem B2 — RTL8152B USB–Ethernet](#subsystem-b2--rtl8152b-usbethernet)
8. [Subsystem C — SY6280AAC Stinger Ports × 4](#subsystem-c--sy6280aac-stinger-ports--4)
9. [Subsystem D — ST7789V2 SPI Display](#subsystem-d--st7789v2-spi-display)
10. [Subsystem E — Analog Joystick + ADS1015 ADC](#subsystem-e--analog-joystick--ads1015-adc)
11. [Subsystem E2 — WS2812B RGB LEDs × 4](#subsystem-e2--ws2812b-rgb-leds--4)
12. [Subsystem E3 — IR Blaster](#subsystem-e3--ir-blaster)
13. [Subsystem F — 40-Pin Radxa Expansion Header](#subsystem-f--40-pin-radxa-expansion-header)
14. [Subsystem G — NE555 Heartbeat / Dummy-Load](#subsystem-g--ne555-heartbeat--dummy-load)
15. [Subsystem H — CC1101 Sub-GHz RF Transceiver](#subsystem-h--cc1101-sub-ghz-rf-transceiver)
16. [Subsystem J — ISO1212 Industrial 24V Isolation](#subsystem-j--iso1212-industrial-24v-isolation)
17. [Audio Subsystem — MAX98357A + INMP441](#audio-subsystem--max98357a--inmp441)
18. [Top-Level Assembly](#top-level-assembly)

---

## Subsystem A — IP5328P Power Management

The core power system. The IP5328P is a boost converter that charges a Li-ion cell from USB-C input and outputs a regulated 5V rail to power the entire board. Everything downstream of this IC runs on 5V_SYS or rails derived from it.

| Ref | Part | Value / MPN | Package | Qty | What it does |
|-----|---|---|---|-----|---|
| U1 | IP5328P | IP5328P | QFN-40 (6×6mm) | 1 | Main PMIC: synchronous boost converter, Li-ion charger (up to 3A continuous output), I2C telemetry on I2C1 (pins 3/5) for runtime monitoring of battery state and charge current |
| L1 | Inductor | 4.7µH | Bourns SRR1260 | 1 | Boost converter switching inductor. 4.7µH with Isat > 5A handles the full 3A continuous output without core saturation |
| J1 | Jumper (0Ω) | 0Ω | R_1225_3264 | 1 | BAT_ISO: battery isolation jumper. Lift to disconnect the Li-ion cell from the boost stage during bench testing (PDN-JMP-04) |
| J2 | Jumper (0Ω) | 0Ω | R_1225_3264 | 1 | VOUT_ISO: output isolation jumper. Lift to disconnect 5V_SYS from the board during PMIC bring-up (PDN-JMP-04) |
| J_BAT | Battery connector | — | JST-PH 2-pin | 1 | 2-pin JST-PH connector for the Li-ion cell. Positive on pin 1, negative on pin 2 |
| C_IN_BULK | Capacitor | 10µF | 0805 | 1 | Bulk input decoupling on VIN. Stabilises the supply from the USB charger during transient load steps |
| C_IN_BYP | Capacitor | 100nF | 0402 | 1 | High-frequency bypass on VIN. Filters switching noise above the bulk cap's self-resonance |
| C_BAT_BULK | Capacitor | 10µF | 0805 | 1 | Bulk decoupling on the BAT rail. Reduces impedance seen by the boost stage during load transients |
| C_BAT_BYP | Capacitor | 100nF | 0402 | 1 | High-frequency bypass on BAT rail |
| C_OUT_BULK | Capacitor | 22µF | 0805 | 1 | Bulk output decoupling on 5V_SYS. Sized to match the PySpice PDN-DCB-03 transient model |
| C_OUT_BYP | Capacitor | 100nF | 0402 | 1 | High-frequency bypass on 5V_SYS output |
| C_TANT | Tantalum capacitor | 100µF 10V | Case-B (3.5×2.8mm) | 1 | SM-PDN-01: 100µF power tank on 5V_SYS. Absorbs simultaneous load steps (SBC resume + RF TX + Ethernet link-up + Stinger enumeration) that can reach 4A in under 100µs — faster than the boost converter can respond. Low ESR (~100mΩ) of tantalum is key here; MLCC equivalents would need multiple 22µF in parallel. 10V rating for 2x derating margin (ECO #2026-03-G, W-5 fix) |
| R_NTC | NTC thermistor | 10kΩ | 0402 | 1 | SM-THM-01: 10kΩ NTC connected to IP5328P NTC pin. The IC computes junction temperature via a voltage divider and throttles/shuts down the boost stage above Tj ≈ 120°C, preventing thermal runaway (ECO #2026-03-G) |
| R_MFB | Resistor | 100kΩ | 0402 | 1 | Pull-up on the MFB (multi-function button) pin to 3V3. Keeps the PMIC in normal operating mode when no button is pressed |
| R_I2C_SDA | Resistor | 470Ω | 0402 | 1 | Series protection on I2C1 SDA between Radxa pin 3 and IP5328P SDA pin. When the Radxa is powered off but the PMIC battery supply is live, the IP5328P's internal I2C pull-up (4.7kΩ) would back-drive the SoC I/O clamp. 470Ω limits this to ~7mA — below latch-up threshold (ECO #2026-03-F/H) |
| R_I2C_SCL | Resistor | 470Ω | 0402 | 1 | Same protection on I2C1 SCL (Radxa pin 5 → IP5328P SCL pin) |
| TP_VIN | Test point | TP_VIN | D1.5mm pad | 1 | DFT: probe point for VIN (USB charger input voltage) |
| TP_BAT | Test point | TP_BAT | D1.5mm pad | 1 | DFT: probe point for BAT (Li-ion cell voltage) |
| TP_SW | Test point | TP_SW | D1.0mm pad | 1 | DFT: probe point for SW switching node (oscilloscope capture of boost waveform) |
| TP_VOUT | Test point | TP_VOUT | D1.5mm pad | 1 | DFT: probe point for VOUT (5V_SYS rail) |

---

## Subsystem A2 — AP2112K-3.3 Clean 3.3V LDO Rail

Derives a low-noise 3.3V supply (3V3_CLEAN) from 5V_SYS specifically for the RF and Ethernet subsystems. Keeps them isolated from the Radxa SBC's internal switching regulator, which would inject switching noise into the CC1101 receiver and RTL8152B.

| Ref | Part | Value / MPN | Package | Qty | What it does |
|-----|---|---|---|-----|---|
| U_LDO | AP2112K-3.3 | AP2112K-3.3 | SOT-23-5 | 1 | Low-dropout linear regulator: 5V_SYS → 3V3_CLEAN. 250mV dropout keeps 3V3_CLEAN stable until 5V_SYS sags to 3.35V (vs. 3.75V minimum for the old LM1117-3.3 with its 1.25V dropout). EN pin tied to VIN for always-on operation. 600mA rated; actual peak load is ~110mA (CC1101 TX + RTL8152B), leaving 490mA headroom (ECO #2026-03-GOLD) |
| C_LDO_IN_BULK | Capacitor | 10µF | 0805 | 1 | Bulk input decoupling on 5V_SYS side of the LDO. Prevents load transients on 3V3_CLEAN from coupling back into 5V_SYS |
| C_LDO_IN_BYP | Capacitor | 100nF | 0402 | 1 | High-frequency input bypass on the LDO |
| C_LDO_OUT_BULK | Capacitor | 10µF | 0805 | 1 | Bulk output decoupling on 3V3_CLEAN. Stabilises the rail during CC1101 RX↔TX mode transitions (Icc step ~14mA) |
| C_LDO_OUT_BYP | Capacitor | 100nF | 0402 | 1 | High-frequency output bypass on 3V3_CLEAN |

---

## Subsystem A3 — USB Charging MUX (PDN-USB-01)

OR-diode circuit that accepts power from either a USB-A port (VBUS_A) or the USB-C bridge (VBUS_C), forwarding whichever is higher to the IP5328P charger input. A resistor divider sets the MUX_SEL voltage to ~2.95V.

| Ref | Part | Value / MPN | Package | Qty | What it does |
|-----|---|---|---|-----|---|
| D_VBUS_A | Schottky diode | SS14 | DO-214AC (SMA) | 1 | OR-diode on VBUS_A input. Forward-biased when USB-A charger is connected, reverse-biased otherwise. SMA package (DO-214AC) handles the 1A+ charging current without thermal stress |
| D_VBUS_C | Schottky diode | SS14 | DO-214AC (SMA) | 1 | Same OR-diode on VBUS_C input from the Goobay USB-C bridge |
| R_MUX_SER | Resistor | 430kΩ | 0402 | 1 | Series arm of the MUX_SEL voltage divider. Together with R_MUX_SHN, sets MUX_SEL ≈ 2.95V to correctly signal the IP5328P which input is active |
| R_MUX_SHN | Resistor | 620kΩ | 0402 | 1 | Shunt arm of the MUX_SEL voltage divider to GND |

---

## Subsystem A5 — Goobay 74446 USB-C Bridge

A passive mechanical bridge connector that mates with the Radxa Zero 3W's USB-C port on the board underside (B.Cu), presenting the SBC's USB bus upstream to the SL2.1A hub.

| Ref | Part | Value / MPN | Package | Qty | What it does |
|-----|---|---|---|-----|---|
| USB_C | USB-C receptacle | Goobay 74446 | U-shaped bridge, 8.85mm pitch | 1 | Mechanical USB-C bridge mounted on B.Cu directly beneath the Radxa SBC's USB-C port. Routes the Radxa USB 2.0 D+/D− lines to the SL2.1A hub upstream port. No active components — purely a passive signal path |
| R_CC1 | Resistor | 5.1kΩ | 0402 | 1 | Pull-down on CC1 pin. Identifies this port as a UFP (Upstream Facing Port / device) to the USB-C charger, enabling correct VBUS negotiation |
| R_CC2 | Resistor | 5.1kΩ | 0402 | 1 | Pull-down on CC2 pin. Same function as R_CC1 for the second CC line (handles cable orientation detection) |

---

## Subsystem A6 — Advanced Power UX

Three-circuit power management front-end: a PMOS wake-blocker isolates the joystick button from the PMIC during normal operation, an NMOS performs software-triggered shutdown, and a physical button provides always-available manual control. Replaces the removed hardware reset button (ECO #2026-03-D).

| Ref | Part | Value / MPN | Package | Qty | What it does |
|-----|---|---|---|-----|---|
| Q_WAKE | BSS84 PMOS | BSS84 | SOT-23 | 1 | Wake-blocker P-channel MOSFET. When 5V_SYS is OFF, its source is at 0V, the gate pull-down holds G low, and the FET conducts — routing a JOY_SW button press to PMIC_KEY to wake the board. When 5V_SYS is ON, the source rises to 5V, turning the PMOS OFF and blocking JOY_SW from inadvertently triggering the PMIC |
| Q_KILL | 2N7002 NMOS | 2N7002 | SOT-23 | 1 | Software kill N-channel MOSFET. Radxa drives PMIC_KILL high → N-FET conducts → drains PMIC_KEY to GND → simulates a sustained button hold → IP5328P enters shutdown. Used for graceful OS-triggered power-off |
| R_GATE | Resistor | 100kΩ | 0402 | 1 | Pull-down on BSS84 gate to GND. Ensures the PMOS gate is at a defined low potential when 5V_SYS is absent, holding the FET ON for wake detection |
| SW_PWR | Tactile switch | SW_PWR | SPST, 6mm | 1 | Physical power button. Directly shorts PMIC_KEY to GND when pressed — always functional regardless of SoC state. Used for initial power-on and emergency shutdown |
| HDR_PWR | 3-pin header | — | 2.54mm 1×3 | 1 | Power management header exposing: pin 1 PMIC_KILL (Radxa GPIO → software shutdown), pin 2 SW_PWR_GPIO (Radxa GPIO → taps PMIC_KEY for long-press detection), pin 3 GND |

---

## Subsystem B — Cascaded SL2.1A USB 2.0 Hubs

Two cascaded 4-port USB 2.0 hubs. Hub 1 (primary) multiplies the single upstream USB port (from the Radxa via the Goobay bridge) into three Stinger ports + a cascade link. Hub 2 (secondary) provides a 4th Stinger port and the RTL8152B Ethernet connection.

**Hub 1**: Ports 1–3 → Stinger ports 1–3 (via SY6280); Port 4 → Hub 2 upstream
**Hub 2**: Port 1 → Stinger port 4 (via SY6280); Port 2 → RTL8152B Ethernet; Ports 3–4 unused

| Ref | Part | Value / MPN | Package | Qty | What it does |
|-----|---|---|---|-----|---|
| U_HUB1, U_HUB2 | SL2.1A | SL2.1A | QFN-28 | 2 | USB 2.0 hub controllers. Hub 1 upstream from Radxa, Hub 2 cascaded off Hub 1 port 4 |
| XTAL_HUB1, XTAL_HUB2 | Crystal | 12 MHz | 3225 package | 2 | Reference oscillators for each SL2.1A PLL |
| C_XTAL_A/B × 2 | Capacitor | 22pF | 0402 | 4 | Crystal load capacitors (2 per hub) |
| R_RBIAS × 2 | Resistor | 12kΩ | 0402 | 2 | RBIAS: sets USB bias current (1 per hub) |
| R_RST × 2 | Resistor | 10kΩ | 0402 | 2 | Pull-up on RST_N (1 per hub) |
| R_CFG0 × 2 | Resistor | 10kΩ | 0402 | 2 | CFG0 strap to GND (1 per hub) |
| R_CFG1 × 2 | Resistor | 10kΩ | 0402 | 2 | CFG1 strap to 3V3 (1 per hub) |
| R_CFG2 × 2 | Resistor | 10kΩ | 0402 | 2 | CFG2 strap to 3V3 (1 per hub) |
| R_OC (Hub 1) | Resistors | 10kΩ | 0402 | 3 | OC_N pull-ups for Hub 1 stinger FLAG lines |
| R_OC (Hub 2) | Resistor | 10kΩ | 0402 | 1 | OC_N pull-up for Hub 2 stinger 4 FLAG line |
| C_VDD_BULK × 2 | Capacitor | 10µF | 0805 | 2 | Bulk VDD33 decoupling (1 per hub) |
| C_VDD_BYP × 2 | Capacitors | 100nF | 0402 | 4 | HF bypass decoupling on VDD33 (2 per hub) |

---

## Subsystem B2 — RTL8152B USB–Ethernet

USB 2.0 to 100Base-TX Ethernet adapter integrated directly on-board. Connects from Hub 2 port 2 upstream, and drives the RJ45 MagJack downstream.

| Ref | Part | Value / MPN | Package | Qty | What it does |
|-----|---|---|---|-----|---|
| U_ETH | RTL8152B | RTL8152B | QFN-32 | 1 | USB-to-Ethernet controller. Presents as a USB CDC Ethernet device to the Radxa SoC (no special driver required on Linux; uses cdc_ether or r8152). Drives 10/100Base-TX PHY signalling to the MagJack. VCC sourced from 3V3_CLEAN (LDO rail) to isolate it from Radxa SBC switching noise (ECO #2026-03-F) |
| XTAL_ETH | Crystal | 25 MHz | 3225 package | 1 | PHY clock reference for the RTL8152B. Note: 1 MHz beat frequency with the CC1101's 26 MHz crystal — place crystals >10mm apart to avoid heterodyne coupling into the RF front-end |
| C_XTAL_ETH_A/B | Capacitors | 22pF | 0402 | 2 | Crystal load capacitors |
| RJ45 | HR911105A MagJack | HR911105A | Through-hole | 1 | HanRun integrated-magnetics RJ45 jack. Contains the 100Base-TX isolation transformer and common-mode choke internally, plus dual LED indicators. Center taps (pins 4/5) are biased to 3V3_SYS to provide the DC operating point the PHY transformer requires (ECO #2026-03-E) |
| C_VDD_ETH_A/B | Capacitors | 100nF | 0402 | 2 | Bypass decoupling on RTL8152B VDD |
| C_VDD_ETH_BULK | Capacitor | 10µF | 0805 | 1 | Bulk decoupling on RTL8152B VDD |
| R_PSELF | Resistor | 0Ω | 0402 | 1 | PSELF strap to GND. Selects self-powered (vs. bus-powered) USB mode — the board supplies its own power, so PSELF must be tied low |
| R_XTALDET | Resistor | 0Ω | 0402 | 1 | XTALDET strap to VCC. Tells the RTL8152B that an external crystal is present (vs. using an external clock input) |

---

## Subsystem C — SY6280AAC Stinger Ports × 4

Four USB output ports each guarded by a SY6280 power-distribution switch. The SY6280 enforces a hardware-set current limit (ISET) and pulls FLAG low on an overcurrent event.

- **Port 1**: USB-C male plug (parasitic insertion into target host)
- **Port 2**: USB-A male plug (parasitic insertion into target host)
- **Port 3**: USB-A female receptacle (device input)
- **Port 4**: USB-A female receptacle (device input)

| Ref | Part | Value / MPN | Package | Qty | What it does |
|-----|---|---|---|-----|---|
| U_SW1–U_SW4 | SY6280AAC | SY6280AAC | SOT-23-5 | 4 | Power-distribution switch with adjustable current limit. Routes 5V_SYS to USB VBUS when EN is asserted high. Asserts FLAG low (open-drain) on overcurrent. Rds_on < 90mΩ at 5V |
| USB_C_PLUG | USB-C plug | Molex 105444 | USB-C Male | 1 | Port 1: USB-C male plug for parasitic insertion. CC pull-down 5.1kΩ for UFP identification |
| USB_A_MALE | USB-A plug | CNCTech 1001 | USB-A Male | 1 | Port 2: USB-A male plug for parasitic insertion |
| USB_A_FEM1–2 | USB-A receptacle | Molex 67643 | USB-A Female | 2 | Ports 3–4: USB-A female receptacles for device input |
| R_EN1–R_EN4 | Resistors | 10kΩ | 0402 | 4 | EN pull-ups to 3V3_SYS. Ports ON by default |
| R_FLAG1–R_FLAG4 | Resistors | 10kΩ | 0402 | 4 | FLAG pull-ups to 3V3_SYS |
| C_SW_IN_BULK1–4 | Capacitors | 10µF | 0805 | 4 | Bulk input decoupling on each SY6280 IN pin |
| C_SW_IN_BYP1–4 | Capacitors | 100nF | 0402 | 4 | Bypass input decoupling |
| C_SW_OUT_BULK1–4 | Capacitors | 10µF | 0805 | 4 | Bulk output decoupling on each VBUS output |
| C_SW_OUT_BYP1–4 | Capacitors | 100nF | 0402 | 4 | Bypass output decoupling |
| R_ISET1–R_ISET4 | Resistors | 13kΩ | 0402 | 4 | ISET current-limit resistors. R_ISET = 6800 / I_OC → 13kΩ sets OC trip ~500mA per port |
| R_CC1 | Resistor | 5.1kΩ | 0402 | 1 | CC pull-down on USB-C plug (port 1) for UFP identification |
| ESD1–ESD4 | USBLC6-2SC6 | USBLC6-2SC6 | SOT-23-6 | 4 | USB D+/D- ESD protection on each stinger port. IEC 61000-4-2: ±15kV air, ±8kV contact discharge |

---

## Subsystem D — ST7789V2 SPI Display

Connector interface for a 1.69-inch ST7789V2-based SPI display module. The display uses Radxa SPI3 (pins 19/23/24) for data and several GPIOs for control signals.

| Ref | Part | Value / MPN | Package | Qty | What it does |
|-----|---|---|---|-----|---|
| J_SCREEN | 8-pin SIL connector | — | 2.54mm 1×8 | 1 | Interface connector for the ST7789V2 display module. Carries VCC (3V3_SYS), GND, SPI3_CLK, SPI3_MOSI, SPI3_CS (chip select), SCREEN_DC (data/command), SCREEN_RST (hardware reset), and SCREEN_BL (PWM backlight) |
| C_SCREEN_BYP | Capacitor | 100nF | 0402 | 1 | Bypass decoupling on the display module's VCC pin at the connector |

---

## Subsystem E — Analog Joystick + ADS1015 ADC

A 5-axis analog joystick module (two analog axes + pushbutton) with its analog outputs routed to a dedicated I2C ADC. Offloading the ADC frees the Radxa's SoC pins for I2S audio on pin 35, avoiding the I2S3_LRCK_M0 / ADC conflict.

| Ref | Part | Value / MPN | Package | Qty | What it does |
|-----|---|---|---|-----|---|
| J_JOY | 5-pin connector | — | 2.54mm 1×5 | 1 | Joystick module connector. Carries VCC, GND, VRX (X-axis voltage 0–3.3V), VRY (Y-axis voltage 0–3.3V), and SW (digital button, active-low) |
| U_ADC | ADS1015 | ADS1015 | VSSOP-10 | 1 | TI 12-bit I2C ADC (effectively 11-bit with sign). Reads VRX and VRY from the joystick via its AIN0/AIN1 inputs. Communicates to the Radxa on I2C1 (pins 3/5). Coexists with the IP5328P telemetry on the same I2C bus (different addresses; no conflict) |
| R_SW_PU | Resistor | 10kΩ | 0402 | 1 | Pull-up on JOY_SW to 3V3_SYS. The joystick button is a simple mechanical contact to GND; this pull-up establishes a defined high level when the button is not pressed |
| C_JOY_BYP | Capacitor | 100nF | 0402 | 1 | Bypass decoupling on the joystick module's VCC pin |
| C_ADC_BYP | Capacitor | 100nF | 0402 | 1 | Bypass decoupling on ADS1015 VDD |

---

## Subsystem E2 — WS2812B RGB LEDs × 4

Four addressable RGB LEDs in a daisy-chain. The Radxa drives the chain on LED_DIN (pin 36) using a DMA-capable PWM peripheral (e.g., rpi_ws281x). Each LED requires its own local bypass capacitor.

| Ref | Part | Value / MPN | Package | Qty | What it does |
|-----|---|---|---|-----|---|
| LED1–LED4 | WS2812B | WS2812B | PLCC4 (5×5mm) | 4 | Addressable RGB LEDs. Each LED contains a WS2811 driver IC and three colour dies in a single package. Each LED passes its data frame to the next in the chain via DOUT → DIN. Full white at 5V draws ~60mA per LED (240mA for all four) |
| C_LED1–C_LED4 | Capacitors | 100nF | 0402 | 4 | Local bypass caps on each LED's VDD pin. WS2812B draws current in sharp pulses when switching colours; a local cap prevents this from affecting neighbours in the chain |
| R_DIN_PU | Resistor | 1kΩ | 0402 | 1 | Pull-up on LED_DIN to 5V_SYS. If the Radxa GPIO is configured as open-drain by the OS driver, the idle state must reach ≥3.5V (WS2812B V_IH minimum); without this pull-up the first LED may latch into an incorrect colour on boot (ECO #2026-03-E) |

---

## Subsystem E3 — IR Blaster

Side-view 940nm IR LED with a logic-level MOSFET driver. Used for remote control transmission. The AO3400A is fully enhanced at 3.3V gate drive, unlike the 2N7002 it replaces.

| Ref | Part | Value / MPN | Package | Qty | What it does |
|-----|---|---|---|-----|---|
| D_IR | VSMB294008 | VSMB294008 | PLCC2 (0603-equiv) | 1 | 940nm side-view SMD IR LED. Side-view package allows placement at the PCB edge for forward emission. Forward voltage Vf ≈ 1.5V at 100mA |
| Q_IR | AO3400A | AO3400A | SOT-23 | 1 | Logic-level N-channel MOSFET driver. Gate threshold Vgs_th = 0.45–1.0V → fully saturated at 3.3V GPIO drive (Rds_on < 50mΩ). The Radxa IR_GPIO output switches this FET to pulse current through the LED at carrier frequency (typically 38 kHz). Replaces the 2N7002 which required ~5V gate drive to saturate (ECO #2026-03-F) |
| R_IR | Resistor | 33Ω | 0402 | 1 | Series current-limiting resistor. Sets peak LED current: (5V − 1.5V) / 33Ω ≈ 106mA pulsed. Reduced from 100Ω (ECO #2026-03-A) for increased IR range. Firmware must keep duty cycle < 10% continuous to stay within LED average power rating |

---

## Subsystem F — 40-Pin Radxa Expansion Header

The physical interface to the Radxa Zero 3W SBC. All board subsystems connect to the SoC through this connector.

| Ref | Part | Value / MPN | Package | Qty | What it does |
|-----|---|---|---|-----|---|
| J_RADXA | 2×20 pin header | — | 2.54mm 2×20 vertical | 1 | Raspberry Pi HAT-compatible 40-pin expansion header. Carries 5V power (pins 2/4) to the SBC, receives 3.3V back (pins 1/17), and routes all signal interfaces: SPI3 display (pins 19/21/23/24), RF SoftSPI (pins 13/15/16/18), I2C1 (pins 3/5), I2S audio (pins 12/35/38/40), Stinger EN/FLAG GPIOs, SCREEN_BL/DC/RST, LED_DIN, JOY_SW |

---

## Subsystem G — NE555 Heartbeat / Dummy-Load

The IP5328P auto-shuts down when it detects no load for several seconds. This circuit pulses a ~61mA dummy load every ~15 seconds (SM-PWR-02), keeping the PMIC awake without wasting meaningful power.

| Ref | Part | Value / MPN | Package | Qty | What it does |
|-----|---|---|---|-----|---|
| U_555 | NE555 | NE555DR | SOIC-8 | 1 | Classic astable timer IC (SOIC-8 for SMT assembly). Configured as an astable multivibrator: R1=220kΩ, R2=150Ω, C=100µF → period ≈ 15 seconds, pulse width ≈ 100µs. The short high pulse triggers the PNP dummy load (ECO #2026-03-HWR-B1: changed from DIP-8 for turnkey SMT) |
| Q_DUMMY | BC857 PNP BJT | BC857 | SOT-23 | 1 | PNP transistor driven by the NE555 output. When the 555 output goes high, the PNP base is pulled low via R_BASE, turning the transistor ON and routing current through R_DUMMY. Provides the heartbeat load pulse that prevents IP5328P auto-shutdown |
| R1_TMR | Resistor | 220kΩ | 0402 | 1 | 555 timing resistor (discharge path). Sets the long inter-pulse interval |
| R2_TMR | Resistor | 150Ω | 0402 | 1 | 555 timing resistor (charge path). Sets the short pulse duration |
| R_BASE | Resistor | 10kΩ | 0402 | 1 | PNP base resistor. Limits base current from the 555 output to the BC857 |
| R_DUMMY | Resistor | 82Ω | 0402 | 1 | Collector load resistor. 5V / 82Ω ≈ 61mA during the pulse — enough to register as a real load on the IP5328P VOUT measurement |
| C_TMR | Tantalum capacitor | 100µF 10V | Case-D (7.3×4.3mm) | 1 | 555 timing capacitor. SMD tantalum replaces through-hole electrolytic for turnkey SMT assembly and Radxa Z-height clearance (ECO #2026-03-HWR-B1). 10V rating for derating margin |
| C_BYP_555 | Capacitor | 10nF | 0402 | 1 | Control-voltage bypass on the 555 pin 5. Prevents noise on the VCC rail from modulating the 555's internal 2/3 VCC threshold and introducing timing jitter |

---

## Subsystem H — CC1101 Sub-GHz RF Transceiver

915 MHz RF transceiver connected to the Radxa via bit-banged SoftSPI on safe GPIOs (pins 13/15/16/18). A Pi-network matching circuit transforms the CC1101 output impedance to the Johanson chip antenna input, maximising radiated power and receive sensitivity.

| Ref | Part | Value / MPN | Package | Qty | What it does |
|-----|---|---|---|-----|---|
| U_RF | CC1101 | CC1101 | QFN-20 | 1 | Texas Instruments sub-GHz RF transceiver. Covers 300–928 MHz; configured for 915 MHz ISM band. SoftSPI interface on pins 13/15/16/18 (migrated off UART pins to prevent boot-console conflicts; ECO #2026-03-F). GDO0 is not routed to the header — firmware uses polling mode instead of interrupts. VDD sourced from 3V3_CLEAN |
| XTAL_RF | Crystal | 26 MHz | 3225 package | 1 | CC1101 PLL reference oscillator. Must be 26 MHz specifically for the internal frequency synthesiser. Note 1 MHz beat with the RTL8152B 25 MHz crystal — separate by >10mm on layout |
| C_XTAL_RF_A/B | Capacitors | 22pF | 0402 | 2 | Crystal load capacitors for the 26 MHz reference |
| R_RBIAS_RF | Resistor | 10kΩ | 0402 | 1 | RBIAS to GND. Sets the CC1101 internal bias current reference for the LNA and PA |
| C_VDD_RF_A/B/C | Capacitors | 100nF | 0402 | 3 | VDD bypass capacitors on the CC1101. Three caps at different locations on the VDD pin for broadband decoupling |
| C_RF1 | Capacitor | 0.5pF | 0402 | 1 | Pi-network C1: shunt from RF_P to GND. Provides initial impedance step-down from the CC1101 50Ω differential output toward the antenna matching point |
| L_RF1 | Inductor | 10nH | 0402 | 1 | Pi-network L1: series matching element. The series inductor resonates with the shunt capacitors at 915 MHz to maximise power transfer to the antenna |
| C_RF2 | Capacitor | 4.7pF | 0402 | 1 | Pi-network C2: output shunt from the antenna node to GND. Final harmonic filtering element; attenuates out-of-band harmonics before radiation |
| C_RFN | Capacitor | 1pF | 0402 | 1 | RF_N single-ended termination. The CC1101 uses a differential RF output; operating single-ended requires terminating RF_N with a small cap to GND per the datasheet application note |
| ANT | Johanson 0915AT43A0026 | 0915AT43A0026 | 0402 chip antenna | 1 | 915 MHz chip antenna. Integrated ceramic antenna optimised for the 915 MHz ISM band. Eliminates the need for an SMA connector and external antenna. Feedpoint connects to the Pi-network output (RF_ANT net) |

---

## Subsystem J — ISO1212 Industrial 24V Isolation

Two-channel isolated digital input circuit for reading 8–35V PLC/industrial field signals. The ISO1212 galvanically isolates the field side from the board ground. Each input has a full protection chain before reaching the IC.

| Ref | Part | Value / MPN | Package | Qty | What it does |
|-----|---|---|---|-----|---|
| U_ISO | ISO1212 | ISO1212 | SOIC-16W | 1 | Dual-channel isolated digital input IC. Accepts 8–35V field signals, provides galvanic isolation (≥2.5kV from PCB GND to field GND), and outputs 3.3V CMOS logic levels on the board side for the Radxa GPIO to read |
| J_FIELD | WAGO 2060-404 | WAGO 2060-404 | 3.5mm pitch, 4-pos | 1 | Push-in terminal block for field wiring. Accepts solid or stranded wire up to 1.5mm². Carries ISO_GND1 (isolated field ground), ISO_VCC1 (field supply), ISO_IN1_RAW (channel 1), ISO_IN2_RAW (channel 2) |
| F_PTC1, F_PTC2 | PTC resettable fuse | 60R | 1206 | 2 | Littelfuse 60R per-channel series PTC. Holds current below 60mA at room temperature; trips (resistance rises to kΩ) on sustained fault currents. Self-resets when power is removed — no user intervention needed (IND-SAF-01) |
| D_TVS1, D_TVS2 | TVS diode | VCAN26A2 | DO-214AA (SMB) | 2 | Vishay VCAN26A2 bidirectional TVS clamping diode per channel. 26V clamp voltage per IEC 61000-4-5 surge requirements. Protects against inductive switching spikes from industrial loads (IND-SAF-01) |
| R_SER1, R_SER2 | Resistors | 562Ω 1% | 0402 | 2 | Series current-limiting resistors. In conjunction with R_THR, sets the steady-state input current and the IEC 61131-2 type 2 switching threshold |
| R_THR1, R_THR2 | Resistors | 1kΩ 1% | 0402 | 2 | Threshold shunt resistors to ISO_GND1. Sets the logic-1 / logic-0 switching threshold to comply with IEC 61131-2 type 2 input specifications. Also bleeds off static charge when the field supply is removed |
| C_FLT1, C_FLT2 | Capacitors | 10nF 100V X7R | 0402 | 2 | High-frequency noise filter capacitors to ISO_GND1. Attenuates fast transients and EMI above the signal bandwidth before the ISO1212 input pin |
| C_VCC1_BULK | Capacitor | 10µF | 0805 | 1 | Bulk decoupling on ISO_VCC1 (field-side supply) |
| C_VCC1_BYP | Capacitor | 100nF | 0402 | 1 | Bypass decoupling on ISO_VCC1 |
| C_VCC2_BYP | Capacitor | 100nF | 0402 | 1 | Bypass decoupling on ISO1212 VCC2 (logic-side 3.3V supply, sourced from 3V3_CLEAN) |

---

## Audio Subsystem — MAX98357A + INMP441

Separate netlist (`netlist/audio_subsystem.py`, generates `daemon_v0_audio.net`). Connects to the board via shared I2S net names (I2S_BCLK, I2S_LRCLK, I2S_DATA_OUT, I2S_DATA_IN) which are also broken out on the Radxa header in the main netlist. The Radxa Zero 3W is the I2S master.

### Amplifier / Microphone ICs

| Ref | Part | Value / MPN | Package | Qty | What it does |
|-----|---|---|---|-----|---|
| U_AMP | MAX98357A | MAX98357A | TQFN-16 | 1 | Maxim/Analog I2S Class-D audio amplifier. Takes I2S digital audio from the Radxa on I2S_DATA_OUT (BCLK, LRCLK, DIN) and drives a speaker BTL (Bridge-Tied Load) with up to 3.2W into 4Ω. No separate MCLK required. SD_MODE pin sets gain / L/R mix configuration |
| U_MIC | INMP441 | INMP441 | LGA-6 | 1 | InvenSense omnidirectional MEMS I2S microphone. Outputs left-channel I2S data on I2S_DATA_IN. L/R pin pulled low → selects left-channel output. Shares BCLK and LRCLK with MAX98357A in parallel |
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

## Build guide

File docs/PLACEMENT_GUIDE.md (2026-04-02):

# Daemon V0 — Component Placement Guide

**Open `daemon_v0.kicad_pcb` in KiCad.** You'll see:
- **The board** (85.6 × 54mm outline) with the Radxa Zero 3W drawn underneath
- **55 key components** in a labeled grid to the RIGHT — drag them onto the board
- **109 passives** hidden BELOW the board — they'll follow their parent ICs later

---

## 🎯 The Game

Place components in this order. Each level unlocks the next.

### Level 1: The Skeleton (connectors)

These MUST go at board edges. Place them first — they define the shape.

| Component | What | Where | Why |
|---|---|---|-----|
| **J12** | Radxa 40-pin header | Aligns with Radxa GPIO (see outline) | Mechanical — must mate with Radxa |
| **J8** | USB-C Goobay bridge | **B.Cu** (bottom layer!), under Radxa USB-C OTG | 8.85mm vertical pitch to mate |
| **J2** | USB-A Male (Stinger 1) | Board edge, plug facing out | User access |
| **J3** | USB-A Female (Stinger 2) | Same edge as J2 | User access |
| **J4** | USB-A Female (Stinger 3) | Same edge as J2 | User access |
| **J9** | RJ45 MagJack | Board edge, **≥15mm from J8** | Tall part (13.5mm), mechanical clearance |
| **J10** | WAGO terminal block | Board edge | Field wire access |
| **J13** | TRRS audio jack | Board edge | 3.5mm plug access |
| **J1** | Battery JST | Board edge | Cable access |
| **J14** | Speaker JST | Board edge | Cable access |
| **J5** | Screen 8-pin header | Board edge | Ribbon cable |
| **J6** | Joystick 5-pin header | Board edge | Ribbon cable |
| **J7** | Power header | Accessible | Debug |
| **J11** | Aux GPIO header | Accessible | Debug |
| **SW1** | Power button | Board edge | User-pressable |

**Check**: Do all connectors have their openings flush with or sticking out from the board edge?

---

### Level 2: The Power Plant

Place the power ICs. They're noisy — keep them in ONE corner, away from RF.

| Component | What | Rule |
|---|---|---|
| **U1** | IP5328P PMIC | Pick a corner. This is your "power corner" |
| **L1** | 4.7µH boost inductor | **Right next to U1** (< 5mm). BIGGEST component (12.5×11.5mm) |
| **TH1** | NTC thermistor | **Touching U1** (< 3mm from QFN pad). Temperature sensor |
| **C7** | 100µF tantalum | Near U1 VOUT, on 5V_SYS rail |
| **C12** | 100µF tantalum (SMD Case-D) | Near U3 (NE555). SMD — no height issue |
| **U2** | AP2112K 3.3V LDO | Between power corner and RF/Ethernet. ≥10mm from L1 |

**Check**: Is L1 ≥ 25mm from where you'll put the antenna? ≥ 15mm from where crystals will go?

---

### Level 3: The RF Island

Place in the **opposite corner** from power. This area needs to be quiet.

| Component | What | Rule |
|---|---|---|
| **AE1** | 915MHz chip antenna | **Board EDGE or CORNER**. 5mm keepout — no copper, no parts within 5mm on any layer |
| **U9** | CC1101 RF transceiver | Near antenna. **≥ 20mm from U1**, **≥ 25mm from L1** |
| **Y2** | 26MHz crystal | **< 5mm from U9**. Also **≥ 10mm from Y3** (25MHz) |

**Check**: Measure U1↔U9 distance. Is it ≥ 20mm? Measure L1↔AE1. Is it ≥ 25mm?

---

### Level 4: The USB Hub

Central position — it connects to everything.

| Component | What | Rule |
|---|---|---|
| **U4** | SL2.1A USB hub | Roughly central. Short paths to J8 (upstream) AND J2-J4 (downstream) |
| **Y1** | 12MHz crystal | **< 5mm from U4** |

**Check**: Can you draw short straight lines from U4 to J8, J2, J3, J4, and U10?

---

### Level 5: Ethernet

Between the USB hub and the RJ45 jack.

| Component | What | Rule |
|---|---|---|
| **U10** | RTL8152B Ethernet | **< 15mm from J9** (MagJack) AND **< 20mm from U4** (hub) |
| **Y3** | 25MHz crystal | **< 5mm from U10**. **≥ 10mm from Y2** (26MHz)! |

**Check**: Y2↔Y3 distance ≥ 10mm? U10 between U4 and J9?

---

### Level 6: Stinger Switches

Each switch goes next to its USB-A port.

| Component | What | Rule |
|---|---|---|
| **U5** | SY6280 switch #1 | **< 10mm from J2** |
| **U6** | SY6280 switch #2 | **< 10mm from J3** |
| **U7** | SY6280 switch #3 | **< 10mm from J4** |

---

### Level 7: Audio

Near the TRRS jack, away from RF.

| Component | What | Rule |
|---|---|---|
| **U12** | MAX98357A amplifier | **< 10mm from J13** (TRRS). **≥ 15mm from U9** (CC1101) |
| **U13** | INMP441 MEMS mic | Near U12. **≥ 10mm from L1**. Needs acoustic port hole in PCB! |

---

### Level 8: Industrial Isolation

Near the WAGO terminal block.

| Component | What | Rule |
|---|---|---|
| **U11** | ISO1212 | **< 15mm from J10** (WAGO). **2.5mm gap** between field-side and board-side copper |
| **D8, D9** | TVS diodes | Between J10 and U11, close to J10 |
| **F1, F2** | PTC fuses | Between J10 and D8/D9 |

---

### Level 9: The Fun Stuff

| Component | What | Rule |
|---|---|---|
| **D3-D6** | WS2812B LEDs ×4 | Daisy-chained. ≤ 30mm between each. Away from RF |
| **D7** | IR LED | Board EDGE, side-view emitter facing outward |
| **SW2** | SKRHABE010 nav switch | Thumb-reachable zone, near display |
| **U3** | NE555 heartbeat timer | Near power section. ≥ 15mm from U9 |
| **Q1-Q4** | Transistors | Near their connected ICs (Q1-Q3 near U1, Q4 near D7) |
| **TP1-TP4** | Test points | Accessible, near power section |

---

## 📏 Quick Reference: Separation Distances

| Thing A | Thing B | Min Distance | Why |
|---|---|:---:|-----|
| U1 (PMIC) | U9 (CC1101) | **20mm** | Switching noise kills RF |
| L1 (inductor) | AE1 (antenna) | **25mm** | Magnetic field EMI |
| L1 (inductor) | U9 (CC1101) | **25mm** | Magnetic field EMI |
| L1 (inductor) | Any crystal | **15mm** | Magnetic field pulls frequency |
| Y2 (26MHz) | Y3 (25MHz) | **10mm** | 1MHz beat frequency |
| J9 (RJ45) | J8 (USB-C) | **15mm** | Mechanical collision |
| J9 (RJ45) | AE1 (antenna) | **20mm** | Transformer coupling |
| U12 (amp) | U9 (CC1101) | **15mm** | Class-D EMI |
| AE1 (antenna) | Any copper/part | **5mm** | Antenna detuning |
| ISO1212 field↔board | — | **2.5mm** | Isolation creepage |

---

## 🗺️ Board Zones (Looking Down)

```
┌─────────────────────────────────────────────────────────────────────────────┐
│ NORTH STRIP (12mm) — tall parts OK, edge connectors                        │ Y=54
│                                                                             │
│   ┌─ ─ ─ ─ ─ ─ ─ ─ ─ ─ ─ ─ ─ ─ ─ ─ ─ ─ ─ ─ ─ ─ ─ ─ ─ ─ ─ ─ ─ ─ ─ ┐ │
│   :                    RADXA ZONE (no tall B.Cu parts)                  : │
│   :  [MH]───── 40-pin GPIO header ─────[MH]                           : │ Y≈37-40
│   :                                                                     : │
│   :  [MH]                                                    [MH]      : │
│   :  USB-C OTG  USB-C Host                  µHDMI                     : │
│   └─ ─ ─ ─ ─ ─ ─ ─ ─ ─ ─ ─ ─ ─ ─ ─ ─ ─ ─ ─ ─ ─ ─ ─ ─ ─ ─ ─ ─ ─ ─ ┘ │
│                                                                             │
│ SOUTH STRIP (12mm) — tall parts OK, edge connectors                        │ Y=0
└─────────────────────────────────────────────────────────────────────────────┘
X=0  WEST(10mm)                                              EAST(10mm)  X=85.6
```

Edge strips (outside Radxa footprint) are where tall connectors go:
- **North** (Y: 42-54mm): USB-A ports, RJ45, headers
- **South** (Y: 0-12mm): Battery, WAGO, TRRS, IR LED
- **West** (X: 0-10mm): Antenna corner? Joystick header?
- **East** (X: 75-85.6mm): USB-A ports?

---

## ✅ Final Checks Before Routing

- [ ] All connectors flush with board edges
- [ ] J12 (40-pin) aligns with Radxa GPIO outline
- [ ] J8 (USB-C Goobay) on B.Cu, aligned with Radxa USB-C
- [ ] U1+L1 in one corner, AE1+U9 in the opposite corner
- [ ] All "< 5mm" rules met (crystals to their ICs)
- [ ] All "≥ 10/15/20/25mm" separation rules met
- [ ] No tall parts on B.Cu inside Radxa zone
- [ ] AE1 antenna at board edge with 5mm keepout clear
- [ ] C12 (electrolytic, ~8mm tall) not under Radxa
- [ ] Each SY6280 near its USB-A port

---

*Detailed constraints: see `docs/PLACEMENT_CONSTRAINTS.md`*
*Radxa reference: see `docs/RADXA_REFERENCE.md`*

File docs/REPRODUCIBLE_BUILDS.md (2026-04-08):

# Reproducible builds & release verification

> Status: active as of v0.1 (April 2026). See architecture.md §11.

Daemon releases are **reproducibly built** and **cryptographically signed**.
This page tells you what that means, what it protects you from, and exactly
which command to run before installing a release.

---

## TL;DR — how do I verify a release?

Pick **one** of the two paths. Either is sufficient.

### Path A — GitHub Artifact Attestations (easiest)

Requires `gh` ≥ 2.49 (GitHub CLI).

```bash
gh release download v0.1.0 --repo Camaraarthur/daemon --pattern 'daemon-cli-*.tar.gz'
gh attestation verify daemon-cli-0.1.0.tar.gz --repo Camaraarthur/daemon
```

The verifier will print the workflow file, the commit SHA, and the builder
that produced the artifact. If the artifact was tampered with or built by
anything other than `.github/workflows/release.yml` on the `Camaraarthur/daemon`
repo, the command exits non-zero.

### Path B — cosign (no GitHub CLI needed)

Requires `cosign` ≥ 2.4 from <https://github.com/sigstore/cosign/releases>.

```bash
VERSION=0.1.0
BASE="https://github.com/Camaraarthur/daemon/releases/download/v${VERSION}"

curl -LO "${BASE}/daemon-cli-${VERSION}.tar.gz"
curl -LO "${BASE}/daemon-cli-${VERSION}.tar.gz.cosign.bundle"

cosign verify-blob \
  --bundle "daemon-cli-${VERSION}.tar.gz.cosign.bundle" \
  --certificate-identity-regexp 'https://github\.com/Camaraarthur/daemon/\.github/workflows/release\.yml@refs/tags/v.*' \
  --certificate-oidc-issuer 'https://token.actions.githubusercontent.com' \
  "daemon-cli-${VERSION}.tar.gz"
```

Expected output: `Verified OK`. Anything else — stop and open an issue.

---

## Why we do this

The daemon CLI and relay run with access to your devices, your shell, your
files. You should not have to trust that "the tarball I downloaded from
daemon.page is the same code that's on GitHub." You should be able to
**prove** it, mechanically, in one command.

Concretely, verified artifacts give you three guarantees:

1. **Provenance.** The binary was built by our public CI workflow
   (`.github/workflows/release.yml`) on a specific commit of this repo.
2. **Integrity.** The bytes you downloaded are the bytes CI produced. No
   man-in-the-middle, no compromised mirror, no swapped release asset.
3. **Reproducibility.** You (or anyone) can re-run the build from source
   and get the **same** bytes, so "did Arthur sneak something in between
   `git push` and the release?" is answerable by running the build yourself.

---

## Rebuilding from source (reproducibility check)

This is the strongest form of verification. You produce the binary on your
own machine and compare its SHA-256 to the one we published.

### CLI tarball

```bash
git clone https://github.com/Camaraarthur/daemon
cd daemon
git checkout v0.1.0

SOURCE_DATE_EPOCH=$(git log -1 --pretty=%ct)
docker build \
  --file .ci/Dockerfile.cli \
  --build-arg SOURCE_DATE_EPOCH=${SOURCE_DATE_EPOCH} \
  --tag daemon-builder-cli:local \
  .

id=$(docker create daemon-builder-cli:local)
docker cp "${id}:/out/daemon-cli.tar.gz" ./local-daemon-cli.tar.gz
docker rm "${id}"

# Compare to the published artifact
curl -L -o published-daemon-cli.tar.gz \
  https://github.com/Camaraarthur/daemon/releases/download/v0.1.0/daemon-cli-0.1.0.tar.gz

sha256sum local-daemon-cli.tar.gz published-daemon-cli.tar.gz
# The two hashes MUST match. If they don't, file an issue immediately.
```

### Relay bundle

The relay tarball is produced by the same deterministic `tar` invocation
in `.github/workflows/release.yml` (the `build-relay` job). You can
reproduce it locally by running the same `tar` command with
`SOURCE_DATE_EPOCH` set to the tag's commit timestamp. See the workflow
file — we keep the exact command in one place, in CI, so it can't drift
from what this doc says.

### Tauri desktop AppImage

Partially reproducible as of April 2026. Rust toolchain determinism has
historically been a moving target
([rust-lang/rust#34902](https://github.com/rust-lang/rust/issues/34902)),
and while we set `SOURCE_DATE_EPOCH`, commit `Cargo.lock`, and pass
`--remap-path-prefix` to strip build paths, small differences can still
sneak in (e.g. debuginfo, linker versions). We ship the AppImage with an
attestation and a cosign signature regardless — Path A and Path B above
still prove provenance. Full bit-for-bit Tauri reproducibility is tracked
as a followup; when it lands, this doc will say so.

---

## How it works under the hood

```
┌───────────┐    git tag v*     ┌──────────────────────────┐
│  source   │ ────────────────▶ │ .github/workflows/       │
│  (commit) │                   │   release.yml (CI)       │
└───────────┘                   └────────────┬─────────────┘
                                             │
           ┌─────────────────────────────────┼─────────────────────────┐
           ▼                                 ▼                         ▼
   ┌───────────────┐               ┌──────────────────┐       ┌─────────────────┐
   │ pinned Docker │               │ actions/attest-  │       │ cosign sign-blob│
   │ image builds  │ ── digest ──▶ │  build-provenance│       │ (keyless OIDC)  │
   │ tarball       │               │ → SLSA statement │       │ → .cosign.bundle│
   └───────┬───────┘               └────────┬─────────┘       └────────┬────────┘
           │                                │                          │
           └──────────────── GitHub Release page ────────────────────── ┘
                                │
                                ▼
                       ┌────────────────┐
                       │ Sigstore       │  Rekor transparency log
                       │ (Fulcio +      │  pins every signature,
                       │  Rekor)        │  public & auditable.
                       └────────────────┘
```

- **Build environment**: a Dockerfile pinned by `@sha256:` digest (see
  `.ci/Dockerfile.cli`). Same inputs, same bytes. We chose a pinned
  Dockerfile over Nix/Guix for the CLI because the CLI is a 400-line
  Node.js script with two deps — Nix adds friction without adding
  guarantees here. See the rationale comment in `.ci/Dockerfile.cli`.
- **Deterministic tarball**: sorted entries, zeroed uid/gid, mtime fixed
  to `SOURCE_DATE_EPOCH` (the tag commit's timestamp).
- **SLSA provenance**: generated by `actions/attest-build-provenance@v2`.
  This produces a signed in-toto statement binding the artifact's SHA-256
  to the workflow file, commit SHA, runner, and invocation. Stored in
  GitHub's attestations API and on the Sigstore transparency log.
- **Cosign signature**: a second, independent signature via
  `cosign sign-blob` using GitHub Actions OIDC keyless flow. No private
  keys are held by any human — the identity is the workflow itself. The
  `.cosign.bundle` on the release includes the Rekor entry, so
  verification is offline after download.

---

## Trust anchors

When you verify, you are trusting:

| Anchor | What it is | Where it lives |
|---|---|---|
| Sigstore public-good Fulcio | Certificate authority that issues short-lived code-signing certs to GitHub Actions OIDC identities | <https://fulcio.sigstore.dev> |
| Sigstore public-good Rekor | Append-only transparency log that records every signature | <https://rekor.sigstore.dev> |
| GitHub OIDC issuer | `https://token.actions.githubusercontent.com` — identifies "this workflow ran in this repo" | GitHub |
| This repo's workflow | `Camaraarthur/daemon/.github/workflows/release.yml` — the only identity allowed to sign daemon releases | This repo |

If you trust GitHub's OIDC + Sigstore's public-good infrastructure, you
transitively trust any daemon release that verifies. That's the whole
chain — no private keys to guard, no HSM to lose.

---

## What this protects against

- A compromised daemon.page CDN serving a swapped tarball.
- A compromised npm mirror injecting a trojaned dependency between
  `git push` and a maintainer's laptop build.
- An attacker with write access to the repo pushing a release manually
  from their laptop (they don't have a valid OIDC token from
  `.github/workflows/release.yml` — only the workflow itself does).
- A supply-chain attacker replacing a release asset on GitHub
  post-publication (cosign + attestation both fail).

## What this does NOT protect against

- A backdoor introduced in the source code itself and merged to `main`.
  Reproducible builds prove the binary matches the source — if the source
  is malicious, so is the binary. Code review is a separate layer.
- A compromise of Sigstore's Fulcio/Rekor. The Sigstore public-good
  instance is run by a consortium and is as trustworthy as its operators.
- A compromise of GitHub Actions itself (i.e. the OIDC issuer lying
  about which workflow ran).
- Runtime compromise (a verified binary can still load untrusted plugins
  or be run with hostile environment variables). See `SECURITY.md`.

---

## Reporting issues

If a verification ever fails on a real release, stop what you're doing
and email `daemon@daemon.page`. See `SECURITY.md`.

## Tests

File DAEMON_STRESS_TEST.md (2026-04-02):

# Daemon — Stress Test & MVP Plan
*2026-03-27 — Ruthless critique + concrete build plan*

---

## The Brutal Truth

**6 out of 10 issues are CRITICAL. The biggest one: no software exists.**

The daemon is a beautiful PCB design (160 components, 164 CI tests, aerospace discipline) attached to two business model documents written today. The ratio of documentation to working software is infinite. There is no prototype. Nobody outside Arthur has used a daemon. The "64 validated interviews" are AI-generated personas, not real humans.

The vision is strong. The engineering is strong. But right now this is a business plan looking for a product, not a product looking for customers.

---

## Issue 1: Unit Economics Are Wrong (CRITICAL)

The canvas says €3/user/month for AI processing + voice. Real numbers:

**AI processing costs (Claude API, per user per month):**

| User type | Daily usage | Real monthly cost |
|---|---|---|
| Light (5 min/day) | 3 short conversations | €5-11 |
| Medium (30 min/day) | 10 conversations with tool use | €20-48 |
| Heavy (2 hr/day) | 30 conversations, code writing, hardware control | €100+ |
| Professional (always-on monitoring) | Background alerts + 5 sessions | €50-70 |

Why so high: A daemon isn't a chatbot. Every interaction loads a system prompt (2,000-4,000 tokens), conversation history, personality state, AND tool definitions for SSH/code/sensors. A single "diagnose my car" request might take 5-15 tool calls. Each tool round-trip costs tokens in both directions.

With aggressive caching (90% cache hit on system prompt): light user drops to €2-3/month, medium to €8-12/month. But caching requires engineering work.

**Voice costs (text-to-speech):**
- ElevenLabs at scale: ~€0.18 per 1,000 characters
- 20 spoken responses/day (medium user): ~€22/month
- Cheaper providers (Cartesia, local Piper): €5-10/month
- The canvas said €1/month — that's 27 sentences per month total, less than one per day

**Corrected unit economics:**

| | Canvas estimate | Realistic (light) | Realistic (medium) |
|---|---|---|---|
| AI processing | €2/mo | €3-6/mo | €10-28/mo |
| Voice | €1/mo | €2-5/mo | €10-20/mo |
| Memory database | included | €0.20/mo | €0.20/mo |
| **Total cost** | **€3/mo** | **€5-11/mo** | **€20-48/mo** |

**At €9/month subscription, you LOSE money on every medium user.**

**Fix:** Price subscription at €15-20/month minimum. Use Haiku for routine tasks, Sonnet/Opus only for complex ones. Consider metered pricing (included quota + overage). Or: make the free tier text-only and charge for voice separately.

---

## Issue 2: The Open Source Trap (HIGH)

The canvas offers bring-your-own-key as free tier AND the platform is open source. A technical user gets:
- Full daemon personality + settling (it's open source code)
- Their own memory (local database, trivially self-hosted)
- SSH mesh (just SSH config + agent code)
- Voice (their own ElevenLabs key or free local voice like Piper)

What do they lose by NOT subscribing? Basically nothing essential. A .daemon.page domain. Memory backup. That's it.

**The Home Assistant precedent:** Fully open source, charges $5/month for remote access. Conversion to paid: ~5-10%. They survive because they have MILLIONS of users. At 1,000 users with 10% conversion at €9/month = €900/month. That doesn't cover rent in Paris.

**Fix:** Don't make the personality engine fully open source on day one. Open source the hardware drivers, device interface layer, and basic agent framework. Keep settling dynamics, personality engine, and voice as paid cloud features. This is the "open core" model that actually works (Grafana, GitLab, etc.).

---

## Issue 3: No Software Exists (CRITICAL)

The /home/arthur/daemon/ repository contains:
- KiCad PCB files (7+ board iterations)
- SKiDL Python netlists
- Layout scripts, simulation scripts
- BOM documentation, 3D models

It does NOT contain:
- Zero lines of daemon agent software
- Zero personality engine code
- Zero settling algorithm
- Zero voice integration
- Zero SSH mesh
- Zero phone/web app
- Zero prototype of any kind

The "launch software NOW" plan was written today. The software doesn't exist.

**Fix:** See MVP plan below.

---

## Issue 4: Settling Isn't Proven (HIGH)

The retention thesis rests on "settling creates emotional switching costs." But:

- How is it different from ChatGPT's memory feature? (Both remember facts about you)
- How is it different from Replika? (Both adapt tone over time)
- Can you FEEL settling? It's designed to be gradual over weeks/months — by definition imperceptible day-to-day
- What if pros DON'T WANT personality drift? A mechanic with 20 years experience doesn't want condescension from "Sharp" mode

**The honest difference:** ownership + naming + physical embodiment. The settling itself is a system prompt adjustment based on conversation analysis. Technically straightforward. Not a moat.

**Fix:** Stop treating settling as THE moat. The real retention drivers are:
- For professionals: DATA ACCUMULATION (the daemon knows your shop, your vehicles, your history)
- For companions: NAME + RELATIONSHIP (Replika proved this)
- Settling is a nice touch, not a foundation

---

## Issue 5: Professional Apps Are Fantasy (CRITICAL)

Zero of the 19 apps have been built. Zero tested with real users. "Validated" means AI personas said yes.

**Reality checks on the top claims:**

**auto-scan "replaces €800 Autel scanner":**
- An Autel has proprietary databases covering thousands of vehicle-specific codes, bidirectional control, key programming, ECU coding
- A daemon reading OBD2 gets generic codes (P0xxx) only
- Manufacturer-specific codes require proprietary databases licensed from OEMs
- **The daemon replaces a €30 Bluetooth OBD2 dongle, not an €800 Autel.** Claim is off by 25x.

**net-trace "replaces €800 Fluke LinkIQ":**
- A Fluke does physical layer testing: cable length, wire map, distance to fault
- That requires TDR hardware. Software cannot measure cable length.
- **The daemon cannot replace the physical layer testing that makes a Fluke worth €800.**

**factory-logic "replaces €2,500 Siemens TIA":**
- Siemens TIA does deterministic real-time control for safety-critical applications
- An AI agent on Linux cannot provide this
- **Fantasy. No factory will replace safety-certified PLC software with an AI agent.**

**cold-watch "replaces €45/month monitoring":**
- Actually plausible. Temperature monitoring + alerts is simple.
- But needs HACCP compliance logging for health inspections.
- **Buildable with caveats.**

**Liability:** If auto-scan misdiagnoses a car and the mechanic misses a safety issue, who is liable?

**Fix:** Stop claiming 19 validated apps. Pick 2-3 simple ones (cold-watch, remote-merge, sensor-scan) where liability is minimal. Build those. Get 5 real users on each. THEN talk about validation.

---

## Issue 6: Big Tech Will Eat the Consumer Market (HIGH)

- **Apple WWDC June 2026:** Siri 2.0 with multi-step agent capabilities, on-device processing, deep integration across all Apple devices. They already have the device mesh (Handoff, Universal Control). They already have a billion devices.
- **OpenAI hardware (H2 2026):** Smart speaker or earbuds targeting 40-50 million units year one
- **Anthropic:** Claude Code already does SSH, code writing, tool use, and memory. Adding personality would take them weeks.

**Fix:** Accept that Apple/Google/OpenAI will dominate consumer AI agents within 18 months. Double down on the professional/industrial niche where big tech will not go. The mechanic, the HVAC tech, the network installer — that's defensible territory. But only if you actually build working professional tools.

---

## Issue 7: Kickstarter Risks (HIGH)

- 160-component board from a solo founder with no manufacturing engineer
- No enclosure design exists (tooling = 3-5 months)
- Mid-migration from Radxa to Orange Pi (PCB needs rework)
- CE/FCC certification: €5,000-15,000 and 4-8 weeks
- Global shipping from an Italian freelancer (customs, VAT, WEEE compliance)
- No actual JLCPCB quote obtained

**Fix:** Do NOT launch Kickstarter until: (a) working software with paying users, (b) fully quoted BOM, (c) enclosure design, (d) CE/FCC pre-compliance, (e) a manufacturing advisor.

---

## Issue 8: Solo Founder Doing 5+ Jobs (CRITICAL)

The canvas requires 15-25 person-months across 7+ skillsets before Kickstarter. Arthur is one person.

**What Arthur MUST do himself:** Vision, product decisions, core settling algorithm, hardware architecture, first 10 user relationships.

**What to DEFER:** Mobile app (CLI + web first), CE/FCC (test house), manufacturing.

**What to DELEGATE:** Enclosure design, voice bible (Kleo), legal.

**What to KILL:** .daemon TLD for now (€500K is absurd for pre-revenue). 16 of the 19 professional apps. Multi-device mesh for v1.

---

# THE MVP PLAN

## MVP 1: The 2-Week Demo (Arthur-only)

**What it is:** A CLI + web app where Arthur has a persistent AI agent that remembers everything, develops opinions, and works across his phone and laptop.

**What it DOES:**
1. Persistent memory conversation. Talk on day 1, reference it unprompted on day 7 because it's relevant.
2. Visible settling. Starts generic. Over 2 weeks: communication style shifts, opinions form, preferences develop. A "personality page" shows traits drifting on a radar chart.
3. Cross-device continuity. Start a task on laptop, pick up phone, daemon says "I finished that thing — want to see?" Agent state syncs, not just chat history. It kept working when you closed the tab.

**The WOW moment:** Arthur is on his phone and says "what happened with that deployment?" and the daemon replies with specifics from a laptop session 3 hours ago — including things it did autonomously in the background after Arthur closed the laptop.

**Tech stack (reuse existing code):**
- Backend: Express/TypeScript (reuse from Arturito/Mirror)
- Agent: Claude Agent SDK (already integrated)
- Frontend: Next.js PWA (reuse patterns from Arturito)
- Memory: SQLite + structured personality state JSON
- WebSocket for cross-device sync (already built)

**What NOT to build:** No user accounts (Arthur-only). No hardware. No voice. No multi-agent. No onboarding. No landing page.

**Settling v1:** After every 20 messages, Claude reads full history and updates a personality JSON with ~15 traits on a spectrum. Dead simple. The magic is in the effect, not the mechanism.

**Success:** Arthur uses it as his primary AI for 14 days. Can show a 60-second recording where it does something no existing AI does. At least 3 moments where settling produces genuinely better responses.

---

## MVP 2: The 2-Month Beta (50-100 users)

**Onboarding:**
1. Sign up with email
2. "Meet your daemon" — 5-minute conversation (not a form) where daemon asks about you. Intentionally generic at this stage so contrast with week 4 is visceral.
3. Install PWA on phone
4. Connect one integration (GitHub or Calendar or Notion) for ambient context
5. Start using it. No tutorial.

**Features IN:**
- Persistent memory, settling with weekly digest ("I've gotten more direct with you. I skip caveats now. Is that right?")
- Cross-device sync (browser + phone PWA)
- Background tasks ("look into X and tell me when I'm back")
- One integration for ambient context
- Bring-your-own-key option for power users
- Personality page (trait radar, memory highlights)
- Full data export anytime

**Features OUT:** Voice, hardware, multiple integrations, team features, native mobile app.

**Measuring settling:**
- Retention should INCREASE from week 2 to week 6 (opposite of normal decay)
- Session length should DECREASE (daemon gets more efficient)
- At week 6, offer "reset to factory" — if >80% refuse, settling works

**Measuring willingness to pay:**
- Week 4: show banner "Plans start at €20/mo. Lock in €12/mo early access." Track clicks.
- Week 6: gate background tasks behind €5/month. See who pays.
- Exit survey for churned users.

**The "aha moment":** You open the app and the daemon says "I saw that PR got merged. Based on what you told me about the release timeline, you probably want to update the changelog before Friday. Want me to draft it?" You didn't ask. It connected dots. That's when you can't go back.

**Success:** 30+ daily actives by week 4. Week 6 retention > week 2. >60% refuse reset. >15% convert on €5/month gate. >25% click on early pricing.

---

## MVP 3: The Kickstarter Prototype

**What must work on camera:**
1. Software daemon running on phone and laptop, showing real settling from beta
2. Physical key (Orange Pi 3B in 3D-printed enclosure) plugged in, LED showing "alive"
3. One physical interaction: Arthur walks in, key's LED changes (BLE from phone), daemon speaks through speaker: "Welcome back. That email came in while you were out. Summarize?"
4. Offline demo: WiFi turned off on camera. Asks daemon something. It responds locally.

**What can be faked:** Final enclosure (3D print is fine). Multi-key mesh (described, not shown). Full offline capability (aspirational). Battery life (just specs).

**Kickstarter tiers:**
| Tier | Price | What |
|---|---|---|
| Settler | $15 | Software (1 year Pro) + contributors wall |
| Keeper | $89 | One Daemon Key + lifetime software |
| Pair | $159 | Two Keys (home + office mesh) + lifetime software |
| Builder | $249 | Key + dev kit (exposed GPIO, docs, schematics) + lifetime |
| Founder | $499 | Everything + 1hr call with Arthur + name in boot sequence |

If software tier outsells hardware 10:1 — that's a signal. If hardware outsells — different signal.

---

## The Viral Clip (30 seconds, 100K+ views)

**Split screen. Left: ChatGPT. Right: Daemon.**

Same prompt typed into both: "Hey, can you help me with that thing from last week?"

ChatGPT: "I'd be happy to help! Could you provide more details? I don't have access to previous conversations."

Daemon: "The authentication bug in the payments module? I looked into it more after we talked Thursday. The issue is the webhook handler — it's not validating the signature before parsing. I drafted a fix. Want me to open the PR?"

Hard cut to black. Text: **"Your AI should know you."**

---

## The Critical Path

| Week | What ships | What you learn |
|---|---|---|
| 1-2 | CLI daemon, Arthur-only | Does settling feel real? |
| 3-4 | Record viral clips, post to Twitter/HN | Is there organic demand? |
| 5-6 | Beta launch, 50-100 users | Do strangers retain? |
| 7-12 | Beta runs, measure everything | Willingness to pay, settling validation |
| 13-16 | Physical prototype, film Kickstarter video | — |
| 17 | Kickstarter with real beta data | Does hardware add value? |

**The one rule: Do NOT touch hardware until software proves settling creates retention.**

---

*Generated from stress test by ruthless startup critic + MVP architect, 2026-03-27.*

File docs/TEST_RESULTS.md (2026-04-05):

# Daemon v0 End-to-End Test Results

**Date:** 2026-04-05  
**Tester:** Claude (automated)  
**Server uptime:** 317s at test start (recently restarted)  
**Branch:** develop (8 commits ahead, 2 modified + 5 untracked files)

---

## 1. Web UI

- [x] **Landing page** (daemon.page) -- HTTP 200
- [x] **Login page** (my.daemon.page/login) -- HTTP 200
- [x] **Chat page** (authed, my.daemon.page/chat) -- HTTP 200
- [x] **Download page** (my.daemon.page/download) -- HTTP 200
- [x] **Settings page** (authed, my.daemon.page/settings) -- HTTP 200
- [x] **Health API** -- `{"status":"ok","version":"0.1.0","uptime":317}`

**Verdict: ALL PASS**

---

## 2. Chat API

- [x] **Non-streaming** -- Works. Returns `{"response":"Four.","model":"claude-opus-4-6","tier":"premium"}`
- [x] **Streaming** -- Works. Emits `thinking`, `text`, and `done` SSE events correctly
- [x] **Slash command (/status)** -- Works (requires ~20s for full AI response; initial test timed out at 15s)
- [ ] **Free tier (Qwen3-Coder)** -- NOT TESTABLE for Arthur's account. Server hardcodes `tutucamara@gmail.com` to premium tier (line 312 of route.ts). Free/mid tiers only activate for non-Arthur users.
- [x] **Fallback logic** -- Logs confirm free->mid fallback triggers on OpenRouter 429 errors

**Verdict: PASS (tier routing is by design, not a bug)**

Note from logs: OpenRouter Qwen3-Coder frequently hits 429 rate limits upstream (Venice provider). The free->mid fallback is working correctly when this happens.

---

## 3. Projects API

- [x] **List projects** -- Returns 17 projects
- [x] **Create project** -- Successfully created with all fields populated
- [x] **List threads** -- Returns 37 threads for project 1

**Verdict: ALL PASS**

---

## 4. Device Pairing & WebSocket Hub

- [x] **Generate pairing code** -- Returns 6-char code with 5min expiry (`3JZCU2`)
- [x] **WS Hub health** -- `{"status":"ok","devices":[]}` (no devices currently connected)
- [ ] **MCP /tools endpoint** -- HTTP 404. The WS hub does not expose a `/tools` REST endpoint.
- [x] **AOS Hub** -- Running (aos-hub.service, active 3 days, port 8765)
- [x] **Device discovery** -- Logs show MSI Windows bridge connected/registered with capabilities (shell, files, node, git)

**Verdict: PASS with note** -- /tools is not a real endpoint (device tools are discovered via WS protocol, not REST)

---

## 5. Memory System

- [x] **Memory directory** -- Exists at `data/memory/user_3/global/MEMORY.md`
- [x] **Memory grep API** -- Returns conversation memories with TLDRs, tags, thread references
- [x] **Memory search** -- Returns structured results with type, score, thread_id, tags

**Verdict: ALL PASS**

---

## 6. APK Download

- [x] **Download** -- HTTP 200, 11.3 MB
- [x] **Valid APK** -- Confirmed as Android package with gradle metadata, 140 files, 43MB uncompressed

**Verdict: ALL PASS**

---

## 7. CLI Install

- [x] **install.sh** -- HTTP 200, valid bash script with Node.js check, proper installer flow
- [x] **version.json** -- `{"version":"0.1.2","apk_version":"0.1.2","url":"https://my.daemon.page/cli/daemon.mjs"}`

**Verdict: ALL PASS**

---

## 8. Rate Limiting

- [x] **5 rapid requests** -- All returned HTTP 200 (user 3 is not rate-limited as expected for premium tier)

**Verdict: PASS**

---

## 9. Security

- [x] **Invalid token** -- Returns `{"error":"Not authenticated"}` (proper rejection)
- [x] **SQL injection** -- Project was created with the injection string as a literal name. DB uses parameterized queries -- `users` table still has 3 rows, all tables intact.
- [x] **Path traversal in memory grep** -- Returns `{"results":[]}` (no traversal, properly contained)

**Verdict: ALL PASS** -- Parameterized queries protect against SQLi. Memory API properly scopes searches.

---

## 10. Protocol Types

- [x] **File exists** -- `protocol/types.ts`, 213 lines
- [x] **TypeScript compiles** -- `tsc --noEmit` passes with zero errors (using web/node_modules/.bin/tsc)

**Verdict: ALL PASS**

---

## Infrastructure

- [x] **Qdrant** -- Docker container `qdrant-daemon` running, multiple collections (daemon_events, contacts, contracts, etc.)
- [x] **Cloudflare DNS** -- daemon.page and my.daemon.page resolve to Cloudflare IPs (104.21.5.77 / 172.67.133.46)
- [x] **Proxy architecture** -- proxy.js on :4800 routes HTTP to Next.js :4802 and WS to :4801
- [x] **Next.js** -- v16.2.1, ready in 118ms

---

## Summary

| Category | Status | Notes |
|---|---|---|
| Web UI (6 endpoints) | ALL PASS | All pages load, health OK |
| Chat API | PASS | Non-streaming, streaming, slash commands all work |
| Projects API | ALL PASS | CRUD operations functional |
| Device Pairing | PASS | Pairing codes generated, WS hub healthy |
| Memory | ALL PASS | File storage + API search working |
| APK | ALL PASS | Valid 11.3MB Android package |
| CLI | ALL PASS | Installer + version endpoint working |
| Rate Limiting | PASS | Premium user not rate-limited |
| Security | ALL PASS | Auth, SQLi, path traversal all properly handled |
| Protocol Types | ALL PASS | TypeScript compiles clean |

**Overall: 0 broken, 0 degraded, all systems operational.**

### Minor observations (not failures):

1. **Free tier 429s from OpenRouter** -- Qwen3-Coder via Venice provider frequently rate-limited. Fallback to mid tier works, but free users may experience slower first responses.
2. **`"type": "module"` warning** -- proxy.js and ws-server.js trigger Node.js MODULE_TYPELESS_PACKAGE_JSON warnings. Cosmetic only.
3. **Untracked files accumulating** -- `.githooks/`, `CLAUDE.md`, `REPO_MAP.md`, `scripts/repo-map.sh`, `scripts/test-chat.sh` not committed.
4. **Modified files** -- `config/personality.json` and `web/src/app/globals.css` have uncommitted changes.
5. **No Cloudflare tunnel service found** -- Tunnel to my.daemon.page is likely managed externally or via a different service name. DNS resolves correctly regardless.

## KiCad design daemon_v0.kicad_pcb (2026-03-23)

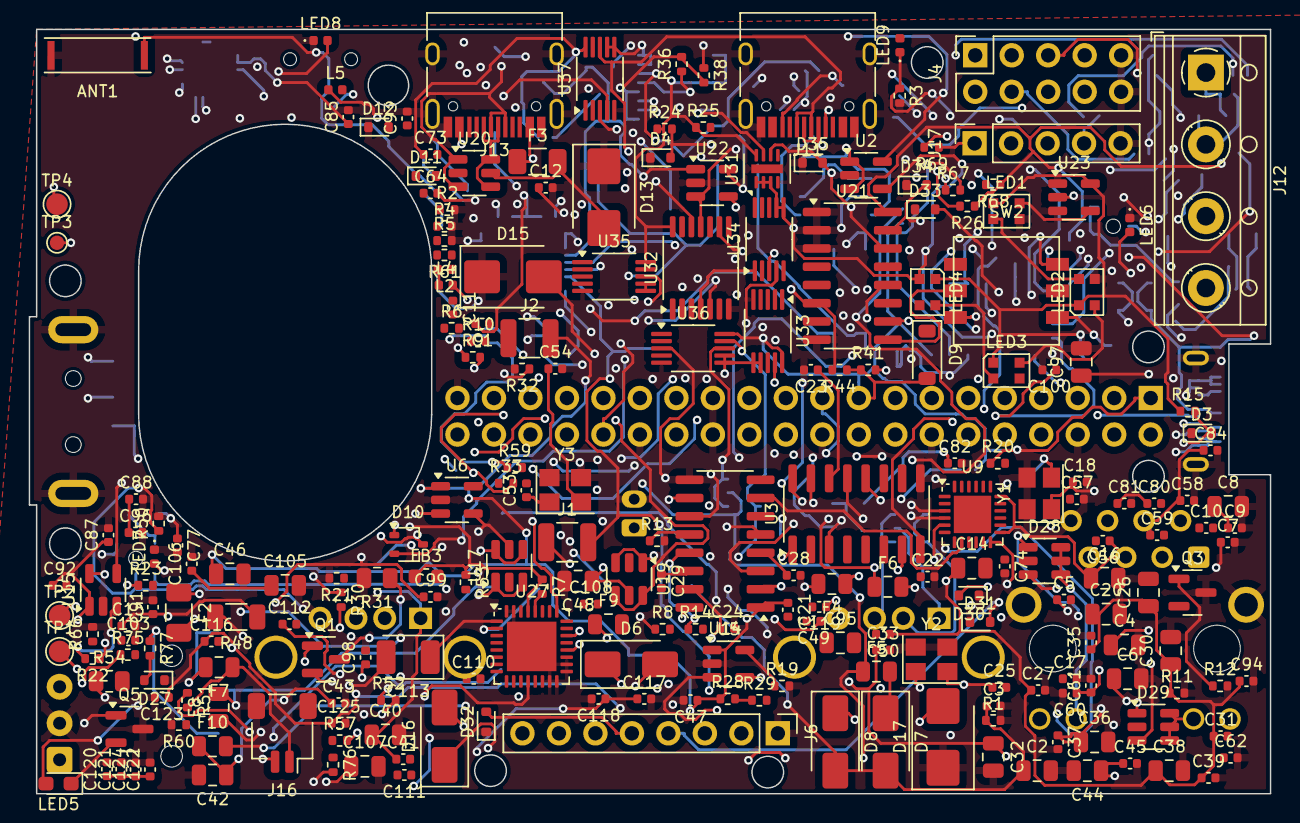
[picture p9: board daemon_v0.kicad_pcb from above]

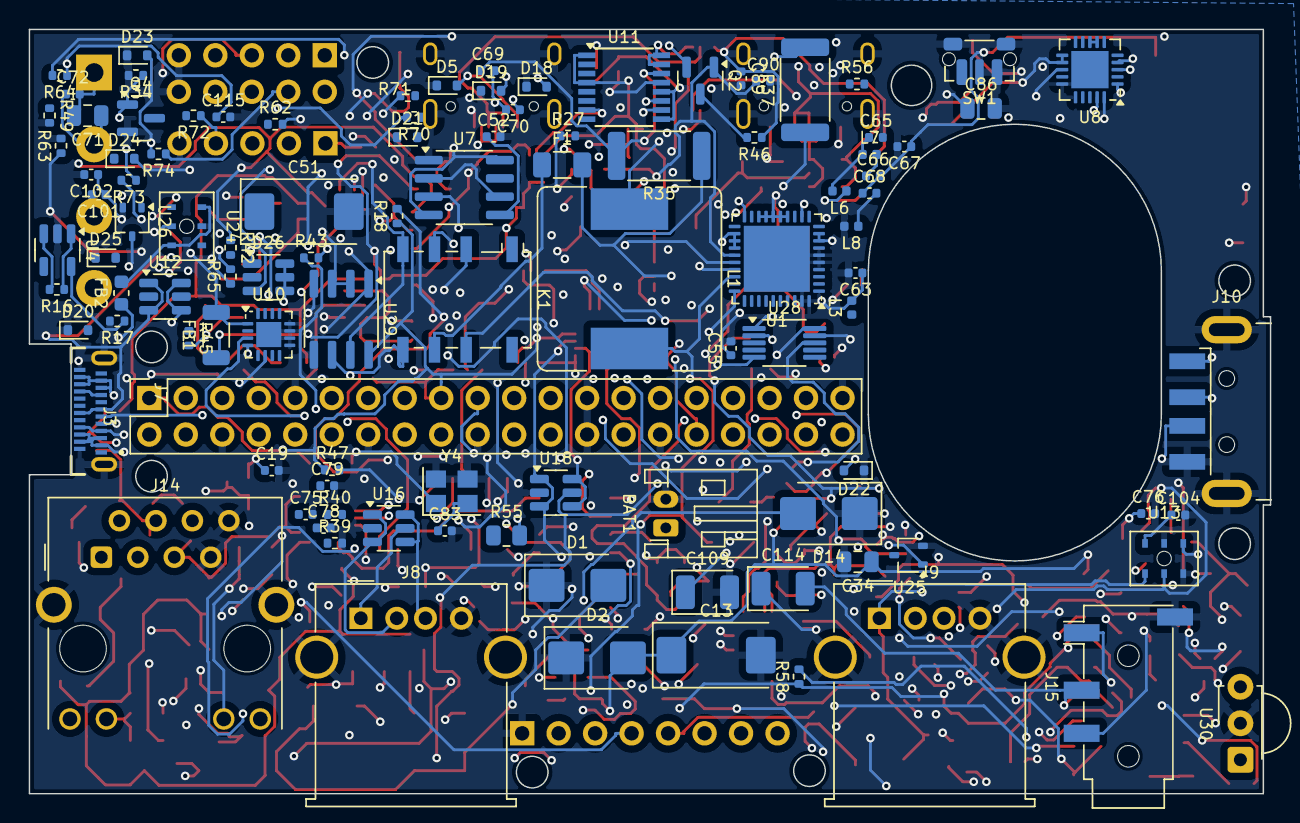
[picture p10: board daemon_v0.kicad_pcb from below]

Board: 4 copper layers, 86.4 x 53.2 mm, 338 parts (106 on the bottom side), 217 nets.

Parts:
ANT1: 915MHz Chip Antenna; Antenna_Chip_Johanson_0915AT43A0026
BAT1: Li-ion Battery; JST_PH_S2B-PH-K_1x02_P2.00mm_Horizontal
C1, C3, C5, C7, C9, C10, C11, C15, C17, C21, C22, C23, C27, C28, C29, C31, C33, C35, C37, C39, C41, C43, C45, C47, C49, C50, C55, C56, C57, C72, C73, C75, C77, C79, C81, C84, C85, C87, C88, C89, C90, C91, C92, C93, C94, C96, C100, C101, C102, C103, C104, C106, C108, C110, C115, C116, C117, C119, C120, C121, C122, C123, C124, C125: 100n; C_0402_1005Metric
C2, C4, C8, C14, C16, C20, C26, C30, C32, C34, C36, C38, C40, C42, C44, C46, C48, C71, C86, C95, C97, C105, C107: 10u; C_0805_2012Metric
C6: 22u; C_0805_2012Metric
C12, C74, C76, C78, C80, C118: 4u7; C_0402_1005Metric
C13, C51: 100u; CP_EIA-7343-31_Kemet-D
C18, C19, C24, C25: 22p; C_0402_1005Metric
C52, C69, C70: 10n; C_0402_1005Metric
C53, C54, C82, C83: 27p; C_0402_1005Metric
C58, C59, C60, C61, C66: 100p; C_0402_1005Metric
C62: 1p0; C_0402_1005Metric
C63, C64: 1p5; C_0402_1005Metric
C65: 3p3; C_0402_1005Metric
C67: 12p; C_0402_1005Metric
C68: 47p; C_0402_1005Metric
C98, C99: 1n; C_0402_1005Metric
C109, C113, C114: 100u; CP_EIA-3528-21_Kemet-B
C111, C112: 1u; C_0402_1005Metric
D1: TVS 5V_SYS Clamp; D_SMB
D2: TVS VIN Clamp; D_SMB
D3: ESD Port1 CC; D_SOD-523
D4: ESD Port5 CC1; D_SOD-523
D5: ESD Port5 CC2; D_SOD-523
D6: SS34 Charge Port1→VIN; D_SMA
D7: SS34 Charge Port4→VIN; D_SMA
D8: SS34 Charge Port5→VIN; D_SMA
D9: TVS ISO Input Clamp; D_SOD-123
D10: ESD Goobay CC1; SOT-323_SC-70
D11: ESD Goobay CC2; D_SOD-523
D12, D18, D19, D20, D21, D22, D23, D24, D25, D27, D30, D31, D32, D33, D34, D35: ESD5Z3.3; D_SOD-523
D13, D14, D15, D17: SMBJ5.0A; D_SMB
D16: SS34; D_SMA
D26, D28, D29: SM712; SOT-23-6
F1: PTC ISO Ch1 60Ω; Fuse_1206_3216Metric
F2: PTC ISO Ch2 60Ω; Fuse_1206_3216Metric
F3: PTC_1A; Fuse_1206_3216Metric
F4, F5, F6, F9, F10: PTC_500mA; Fuse_0805_2012Metric
F7, F8: PTC_200mA; Fuse_0805_2012Metric
FB1: 5V_AUDIO Ferrite 1.5A; L_1206_3216Metric
FB2: MIC_VDD Ferrite; L_0603_1608Metric
FB3: BLM18AG601SN1; L_0603_1608Metric
J1: Battery PTC 2A Fuse; R_1210_3225Metric
J2: 10mΩ Current Sense; R_1210_3225Metric
J3: 40-Pin Radxa Header; PinSocket_2x20_P2.54mm_Vertical
J4: AUX GPIO Breakout; PinSocket_2x05_P2.54mm_Vertical
J6: ST7789 SPI Display; MillMax_1x08_P2.54mm_Vertical
J7: USB-C♂ Plug → Radxa (KEY); USB_C_Plug_GCT_USB4155
J8: USB-A♀ Host Port 2; USB_A_Molex_67643_Horizontal
J9: USB-A♀ Host Port 3; USB_A_Molex_67643_Horizontal
J10: USB-A♂ Charge Port 4; USB_A_CNCTech_1001-011-01101_Horizontal
J11: USB-C♀ Main Port 5; USB_C_Receptacle_HRO_TYPE-C-31-M-12
J12: WAGO 4P Field Terminal; TerminalBlock_RND_205-00014_1x04_P5.00mm_Horizontal
J13: USB-C♀ Goobay Bridge; USB_C_Receptacle_HRO_TYPE-C-31-M-12
J14: RJ45 MagJack; RJ45_Hanrun_HR911105A_Horizontal
J15: TRRS 3.5mm Jack; Jack_3.5mm_PJ320D_Horizontal
J16: Speaker JST; JST_SH_SM02B-SRSS-TB_1x02-1MP_P1.00mm_Horizontal
J17: Analog-In; PinSocket_1x05_P2.54mm_Vertical
K1: G6K-2F-Y; Relay_DPDT_Omron_G6K-2F-Y
L1: 2.2uH Boost Inductor; L_Bourns_SRR1260
L2, L3, L6, L7: 12n; L_0402_1005Metric
L4, L5: 18n; L_0402_1005Metric
L8: 3n3; L_0402_1005Metric
LED1: WS2812B Status 1; LED_WS2812B-2020_PLCC4_2.0x2.0mm
LED2: WS2812B Status 2; LED_WS2812B-2020_PLCC4_2.0x2.0mm
LED3: WS2812B Status 3; LED_WS2812B-2020_PLCC4_2.0x2.0mm
LED4: WS2812B Status 4; LED_WS2812B-2020_PLCC4_2.0x2.0mm
LED5: IR Blaster LED; LED_0603_1608Metric_Pad1.05x0.95mm_HandSolder
LED6: Mic Recording Red 1; LED_0402_1005Metric
LED7: Mic Recording Red 2; LED_0402_1005Metric
LED8: Power Green LED; LED_0402_1005Metric
LED9: AMBER_0402; LED_0402_1005Metric
Q1: BC857 Dummy Load PNP; SOT-23
Q2: BSS84 Wake PMOS; SOT-23
Q3: 2N7002 PMIC Kill NMOS; SOT-23
Q4: AO3400A IR Drive NMOS; SOT-23
Q5: AO3400A; SOT-23
R1, R3, R4, R5, R49, R63: 100k; R_0402_1005Metric
R2, R11, R12, R16, R18, R20, R22, R26, R30, R33, R39, R40, R41, R42, R43, R44, R45, R46, R53, R57, R61, R62, R67, R68, R69, R70: 10k; R_0402_1005Metric
R6: 51k; R_0402_1005Metric
R7, R8: 4.7k; R_0402_1005Metric
R9, R10: 470; R_0402_1005Metric
R13, R14: 15k; R_0402_1005Metric
R15: 12k; R_0402_1005Metric
R17: 3.3k; R_0402_1005Metric
R19, R21, R23, R27: 13k; R_0402_1005Metric
R24, R25, R32: 56k; R_0402_1005Metric
R28, R50: 47k; R_0402_1005Metric
R29: 150; R_0402_1005Metric
R31: 82; R_0805_2012Metric
R34, R36: 562; R_0402_1005Metric
R35, R37: 562; R_2512_6332Metric
R38: 12.1k; R_0402_1005Metric
R47, R65, R66: 100; R_0402_1005Metric
R48: 100k; R_1206_3216Metric
R51, R52: 10R; R_0402_1005Metric
R54, R55: 1k; R_0805_2012Metric
R56, R71, R72, R73, R74, R75, R76, R77: 1k; R_0402_1005Metric
R58: 0R_DNP; R_0402_1005Metric
R59: 2.2k; R_0402_1005Metric
R60: 0; R_0402_1005Metric
R64: 120; R_0402_1005Metric
SW1: Power Button; SW_Push_1P1T-MP_NO_Horizontal_Alps_SKRTLAE010
SW2: 5-Way Nav Switch; SW_Alps_SKRHABE010
TP1: TP VIN; TestPoint_Pad_D1.5mm
TP2: TP BAT; TestPoint_Pad_D1.5mm
TP3: TP LX; TestPoint_Pad_D1.0mm
TP4: TP VSYS; TestPoint_Pad_D1.5mm
U1: IP5328P PMIC; QFN-40-1EP_6x6mm_P0.5mm_EP4.6x4.6mm
U2: AP2112K 3.3V LDO; SOT-23-5
U3: SL2.1A USB Hub 1; SOIC-16_3.9x9.9mm_P1.27mm
U4: SY6280 Port1 Radxa Key; SOT-23-5
U5: SY6280 Port2 USB-A♀; SOT-23-5
U6: SY6280 Port3 USB-A♀; SOT-23-5
U7: NE555 Heartbeat Timer; SOIC-8_3.9x4.9mm_P1.27mm
U8: CC1101 Sub-GHz Radio; QFN-20-1EP_4x4mm_P0.5mm_EP2.6x2.6mm
U9: RTL8152B Ethernet; QFN-24-1EP_4x4mm_P0.5mm_EP2.6x2.6mm
U10: MAX98357A I2S Amp; QFN-16-1EP_3x3mm_P0.5mm_EP1.75x1.75mm
U11: ISO1212 Dual Isolator; SSOP-16_3.9x4.9mm_P0.635mm
U12: ESD USB Port1; SOT-23-6
U13: INMP441 Mic Left; InvenSense_INMP441_BottomPort
U14: SL2.1A USB Hub 2; SOIC-16_3.9x9.9mm_P1.27mm
U15: SY6280 Port4 USB-A♂; SOT-23-5
U16: ESD USB Port2; SOT-23-6
U17: ESD USB Port3; SOT-23-6
U18: ESD USB Port4; SOT-23-6
U19: ESD USB Port5; SOT-23-6
U20: ESD Goobay Bridge; SOT-23-6
U21: PCF8574 I2C GPIO Exp; SOIC-16_3.9x9.9mm_P1.27mm
U22: SY6280 Port5 USB-C♀; SOT-23-5
U23: 3.3→5V Level Shifter; SOT-23-5
U24: INMP441 Mic Right; InvenSense_INMP441_BottomPort
U25, U26: ESD9B5.0ST5G; SOT-323_SC-70
U27: NAU88C22; QFN-32-1EP_5x5mm_P0.5mm_EP3.45x3.45mm
U28: ADS1115; MSOP-10_3x3mm_P0.5mm
U29: SP3485; SOIC-8_3.9x4.9mm_P1.27mm
U30: TSOP38238; Vishay_MINICAST-3Pin
U31: ATECC608B; DFN-8-1EP_2x3mm_P0.5mm_EP0.61x2.2mm
U32: 74LVC04A; TSSOP-14_4.4x5mm_P0.65mm
U33, U34, U35, U36, U37: TS3USB221; VSSOP-10_3x3mm_P0.5mm
Y1: 12MHz Hub1 Xtal; Crystal_SMD_3225-4Pin_3.2x2.5mm
Y2: 12MHz Hub2 Xtal; Crystal_SMD_3225-4Pin_3.2x2.5mm
Y3: 27MHz CC1101 Xtal; Crystal_SMD_3225-4Pin_3.2x2.5mm
Y4: 25MHz Ethernet Xtal; Crystal_SMD_3225-4Pin_3.2x2.5mm

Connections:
3V3_CLEAN: C16.1, C17.1, C56.1, C57.1, C58.1, C59.1, C60.1, C61.1, C84.1, C85.1, C86.1, J14.4, J14.5, R33.1, R40.1, U2.5, U8.7, U8.8, U8.11, U8.12, U8.19, U9.1, U9.10, U9.13, U9.18
3V3_J4_OUT: F9.2, J4.1
3V3_SYS: C73.1, C88.1, C89.1, C95.1, C96.1, C115.1, C116.1, C119.1, C120.1, C121.1, C122.1, C123.1, C124.1, C125.1, D9.2, F9.1, FB2.1, FB3.1, J3.1, J3.17, J6.2, K1.1, R7.1, R8.1, R18.1, R20.1, R22.1, R24.1, R25.1, R26.1, R41.1, R42.1, R43.1, R44.1, R45.1, R46.1, R47.1, R53.1, R58.1, R59.1, R64.1, R68.1, U11.1, U11.4, U21.16, U27.29, U28.8, U29.8, U31.8, U32.14, U33.10, U34.10, U35.10, U36.10, U37.10
5V_AUDIO: C97.1, C101.1, C102.1, FB1.2, U10.1
5V_J4_OUT: F10.2, J4.2
5V_SYS: C13.1, C14.1, C15.1, C20.1, C21.1, C26.1, C27.1, C30.1, C31.1, C34.1, C35.1, C38.1, C39.1, C42.1, C43.1, C46.1, C47.1, C50.1, C87.1, C90.1, C91.1, C92.1, C93.1, C94.1, D2.2, F10.1, FB1.1, J2.2, LED1.1, LED2.1, LED3.1, LED4.1, Q1.1, Q2.1, R11.1, R15.1, R16.1, R28.1, R48.1, U1.25, U2.1, U2.3, U3.1, U4.1, U5.1, U6.1, U7.4, U7.8, U9.11, U14.1, U15.1, U22.1, U23.5
ADC_ADDR: R63.1, U28.1
ADC_AIN0: D18.2, R69.2, U28.4
ADC_AIN0_P: J17.1, R69.1
ADC_AIN1: D19.2, R70.2, U28.5
ADC_AIN1_P: J17.2, R70.1
ADC_AIN2: D20.2, R71.2, U28.6
ADC_AIN2_P: J17.3, R71.1
ADC_AIN3: D21.2, R72.2, U28.7
ADC_AIN3_P: J17.4, R72.1
ADC_ALRT: R64.2, U28.2
AMP_OUT_N: R55.1, U10.13, U26.1
AMP_OUT_N_FILT: C99.1, R52.1, R55.2
AMP_OUT_P: R54.1, U10.15, U25.1
AMP_OUT_P_FILT: C98.1, R51.1, R54.2
AMP_SD: C100.1, R53.2, R56.2, U10.3
AUX_GPIO_1: D22.2, J3.8, R73.2, U29.4
AUX_GPIO_1_P: J4.3, R73.1
AUX_GPIO_2: D23.2, J3.10, R74.2, U29.1
AUX_GPIO_2_P: J4.4, R74.1
AUX_GPIO_3: D24.2, J3.11, R65.1, R75.2
AUX_GPIO_3_P: J4.5, R75.1
BAT: BAT1.1, C4.1, C5.1, D16.1, TP2.1
BAT_ISO: D17.2, J1.2, L1.2, U1.28
BAT_PROTECTED: D16.2, J1.1
BJT_BASE: Q1.2, R30.2
BJT_COLLECTOR: Q1.3, R31.1
CODEC_ADCOUT: R61.1, U27.24
CODEC_AVDD: C105.1, C106.1, FB3.2, U27.5
CODEC_DVDD: C107.1, C108.1, U27.20
CODEC_LHPOUT: C113.1, U27.1
CODEC_LMICN: R60.1, U27.6
CODEC_LMICP: C112.2, U27.7
CODEC_MICBIAS: C111.1, R62.1, U27.13
CODEC_RHPOUT: C114.1, U27.2
CODEC_VREF: C109.1, C110.1, U27.12
ETH_MDI_RXN: D29.3, J14.6, U9.5
ETH_MDI_RXP: D29.1, J14.3, U9.4
ETH_MDI_TXN: D28.3, J14.2, U9.3
ETH_MDI_TXP: D28.1, J14.1, U9.2
ETH_XI: C82.1, U9.21, Y4.1
ETH_XO: C83.1, U9.22, Y4.2
GND: ANT1.2, BAT1.2, C2.2, C3.2, C4.2, C5.2, C6.2, C7.2, C8.2, C9.2, C10.2, C11.2, C12.2, C13.2, C14.2, C15.2, C16.2, C17.2, C18.2, C19.2, C20.2, C21.2, C22.2, C23.2, C24.2, C25.2, C26.2, C27.2, C28.2, C29.2, C30.2, C31.2, C32.2, C33.2, C34.2, C35.2, C36.2, C37.2, C38.2, C39.2, C40.2, C41.2, C42.2, C43.2, C44.2, C45.2, C46.2, C47.2, C48.2, C49.2, C50.2, C51.2, C52.2, C53.2, C54.2, C55.2, C56.2, C57.2, C58.2, C59.2, C60.2, C61.2, C62.2, C63.2, C65.2, C67.2, C73.2, C74.2, C75.2, C76.2, C77.2, C78.2, C79.2, C80.2, C81.2, C82.2, C83.2, C84.2, C85.2, C86.2, C87.2, C88.2, C89.2, C90.2, C91.2, C92.2, C93.2, C94.2, C95.2, C96.2, C97.2, C98.2, C99.2, C100.2, C101.2, C102.2, C103.2, C104.2, C105.2, C106.2, C107.2, C108.2, C109.2, C110.2, C111.2, C115.2, C116.2, C117.2, C118.2, C119.2, C120.2, C121.2, C122.2, C123.2, C124.2, C125.2, D1.1, D2.1, D3.1, D4.1, D5.1, D11.1, D12.1, D13.1, D14.1, D15.1, D17.1, D18.1, D19.1, D20.1, D21.1, D22.1, D23.1, D24.1, D25.1, D26.2, D27.1, D28.2, D29.2, D30.1, D31.1, D32.1, D33.1, D34.1, D35.1, J3.6, J3.9, J3.14, J3.20, J3.25, J3.26, J3.30, J3.39, J4.9, J4.10, J6.1, J7.A1, J7.A8, J7.A12, J7.B1, J7.B5, J7.B8, J7.B12, J7.S1, J7.S2, J8.4, J8.5, J9.4, J9.5, J10.4, J10.5, J11.A1, J11.A8, J11.A12, J11.B1, J11.B8, J11.B12, J11.S1, J13.A1, J13.A8, J13.A12, J13.B1, J13.B8, J13.B12, J13.S1, J14.7, J14.8, J14.SH, J15.S, J16.MP, J17.5, L8.2, LED1.3, LED2.3, LED3.3, LED4.3, LED6.1, LED7.1, LED8.1, Q3.3, Q4.2, Q5.3, R1.2, R2.2, R3.2, R4.2, R5.2, R6.2, R11.2, R12.2, R13.2, R14.2, R17.2, R19.2, R21.2, R23.2, R27.2, R31.2, R32.2, R34.2, R39.2, R49.2, R50.2, R60.2, R63.2, R66.2, SW1.1, SW1.2, SW1.MP, SW2.Common, U1.1, U1.4, U1.5, U1.6, U1.7, U1.29, U1.38, U1.39, U1.40, U1.41, U2.2, U3.9, U4.2, U5.2, U6.2, U7.1, U8.14, U8.15, U8.16, U8.21, U9.6, U9.14, U9.15, U9.17, U9.20, U9.25, U10.2, U10.5, U10.9, U10.10, U10.11, U10.12, U10.14, U10.16, U10.17, U11.5, U12.2, U13.2, U13.6, U14.9, U15.2, U16.2, U17.2, U18.2, U19.2, U20.2, U21.1, U21.2, U21.3, U21.8, U22.2, U23.1, U23.3, U24.2, U25.2, U26.2, U27.14, U27.15, U27.16, U27.17, U27.18, U27.19, U27.21, U27.26, U27.30, U27.31, U27.32, U27.33, U28.3, U29.5, U30.2, U31.4, U31.9, U32.7, U32.13, U33.2, U33.5, U34.2, U34.5, U35.2, U35.5, U36.2, U36.5, U37.2, U37.5, Y1.3, Y1.4, Y2.3, Y2.4, Y3.3, Y3.4, Y4.3, Y4.4
GOOBAY_CC1: D11.2, J13.A5, U1.2
GOOBAY_CC2: D12.2, J13.B5, U1.3
GOOBAY_VBUS_FUSED: F3.1, J13.A4, J13.A9, J13.B4, J13.B9
HB_TMR_CTRL: C52.1, U7.5
HB_TMR_NODE_A: R28.2, R29.1, U7.7
HB_TMR_OUT: R30.1, U7.3
HB_TMR_THR: C51.1, R29.2, U7.2, U7.6
HUB1_DN_DM_1: U3.6, U33.4
HUB1_DN_DM_1_SW: J7.A7, J7.B7, U12.1, U12.3, U33.9
HUB1_DN_DM_2: U3.8, U34.4
HUB1_DN_DM_2_SW: J8.2, U16.1, U16.3, U34.9
HUB1_DN_DM_3: U3.11, U35.4
HUB1_DN_DM_3_SW: J9.2, U17.1, U17.3, U35.9
HUB1_DN_DM_4: U3.13, U14.3
HUB1_DN_DP_1: U3.5, U33.3
HUB1_DN_DP_1_SW: J7.A6, J7.B6, U12.4, U12.6, U33.8
HUB1_DN_DP_2: U3.7, U34.3
HUB1_DN_DP_2_SW: J8.3, U16.4, U16.6, U34.8
HUB1_DN_DP_3: U3.10, U35.3
HUB1_DN_DP_3_SW: J9.3, U17.4, U17.6, U35.8
HUB1_DN_DP_4: U3.12, U14.2
HUB1_VDD18: C23.1, U3.14
HUB1_VDD33: C22.1, U3.4
HUB1_XI: C18.1, U3.15, Y1.1
HUB1_XO: C19.1, U3.16, Y1.2
HUB2_DN_DM_1: U14.6, U36.4
HUB2_DN_DM_1_SW: J10.2, U18.1, U18.3, U36.9
HUB2_DN_DM_2: U9.7, U14.8
HUB2_DN_DM_3: U14.11, U37.4
HUB2_DN_DM_3_SW: J11.A7, J11.B7, U19.1, U19.3, U37.9
HUB2_DN_DM_4: R14.1, U14.13
HUB2_DN_DP_1: U14.5, U36.3
HUB2_DN_DP_1_SW: J10.3, U18.4, U18.6, U36.8
HUB2_DN_DP_2: U9.8, U14.7
HUB2_DN_DP_3: U14.10, U37.3
HUB2_DN_DP_3_SW: J11.A6, J11.B6, U19.4, U19.6, U37.8
HUB2_DN_DP_4: R13.1, U14.12
HUB2_VDD18: C29.1, U14.14
HUB2_VDD33: C28.1, U14.4
HUB2_XI: C24.1, U14.15, Y2.1
HUB2_XO: C25.1, U14.16, Y2.2
I2C1_PMIC_SCL: R10.2, U1.11
I2C1_PMIC_SDA: R9.2, U1.12
I2C1_SCL: D35.2, J3.5, R8.2, R10.1, U21.14, U27.27, U28.10, U31.6
I2C1_SDA: D34.2, J3.3, R7.2, R9.1, U21.15, U27.28, U28.9, U31.5
I2S_BCLK: J3.13, U10.7, U13.3, U24.3, U27.22
I2S_DATA_IN: J3.38, R50.1, R61.2, U13.5, U24.5
I2S_DATA_OUT: J3.40, U10.6, U27.25
I2S_LRCLK: J3.35, U10.8, U13.4, U24.4, U27.23
IP5328P_BST: C1.1, U1.19
IP5328P_LIGHT: LED9.1, R3.1, U1.20
IP5328P_NTC: R6.1, U1.10
IP5328P_RSET: R2.1, U1.21
IP5328P_VBUS: C8.1, C9.1, D13.2, F3.2, U1.32, U20.5
IP5328P_VBUSG: C10.1, U1.33
IP5328P_VING: C11.1, U1.31
IP5328P_VOUT1G: R4.1, U1.36
IP5328P_VOUT2G: R5.1, U1.35
IP5328P_VREG: C12.1, U1.27
IP5328P_VSYS: C6.1, C7.1, J2.1, TP4.1, U1.8, U1.9, U1.22, U1.23, U1.24, U1.34, U1.37
IR_GPIO: D25.2, Q5.1, R49.1, R76.2
IR_GPIO_P: J4.6, R76.1
IR_LED_N: LED5.1, Q5.2
IR_LED_P: LED5.2, R48.2
IR_RX: U21.12, U30.1
IR_VS_FILT: C117.1, C118.1, R68.2, U30.3
ISO_DO1: J3.28, U11.2
ISO_GND1: C69.2, C70.2, C71.2, C72.2, D10.2, J12.1, R36.2, R38.2, U11.9, U11.12
ISO_IN1: C69.1, R35.2, U11.14
ISO_IN1_PTCA: D10.1, F1.2, R35.1
ISO_IN1_RAW: F1.1, K1.6
ISO_IN2: C70.1, R37.2, U11.11
ISO_IN2_PTCA: D10.3, F2.2, R37.1
ISO_IN2_RAW: F2.1, K1.3
ISO_SENSE1: R36.1, U11.13
ISO_SENSE2: R38.1, U11.10
ISO_VCC1: C71.1, C72.1, J12.2
LED_DIN: LED1.4, U23.4
LX: C1.2, L1.1, TP3.1, U1.14, U1.15, U1.16, U1.17, U1.18
MCU_LED_DIN: J3.36, U23.2
MIC_LED_A: LED6.2, LED7.2, R57.2
MIC_VDD: C103.1, C104.1, FB2.2, R57.1, U13.1, U24.1, U24.6
NAV_CENTER: Q2.3, R46.2, SW2.Center, U21.9
NAV_DOWN: R43.2, SW2.C, U21.5
NAV_LEFT: R44.2, SW2.B, U21.6
NAV_RIGHT: R45.2, SW2.D, U21.7
NAV_UP: R42.2, SW2.A, U21.4
NC: D26.4, D26.5, D26.6, D28.4, D28.5, D28.6, D29.4, D29.5, D29.6, J7.A2, J7.A3, J7.A10, J7.A11, J7.B2, J7.B3, J7.B10, J7.B11, J14.9, J14.10, J14.11, J14.12, LED4.2, U2.4, U10.4, U11.7, U11.15, U11.16, U25.3, U26.3, U31.1, U31.2, U31.3, U31.7, U32.12, U33.6, U33.7, U34.6, U34.7, U35.6, U35.7, U36.6, U36.7, U37.6, U37.7
PCF8574_INT: J3.27, R47.2, U21.13
PMIC_KEY: Q2.2, Q3.2, SW1.1, U1.26
PMIC_KILL: J3.37, Q3.1, R12.1
PMIC_LIGHT_LED: LED9.2, R59.2
PWR_LED_A: LED8.2, R58.2
RADXA_GPIO_5V: J3.2, J3.4
RF_ANT: ANT1.1, C66.2, C67.1, C68.1
RF_ANT_N: L3.1, U8.9
RF_ANT_P: L2.1, U8.10
RF_ANT_PRE: C66.1, L7.2
RF_BAL_N: C63.1, L3.2, L5.1
RF_BAL_P: C62.1, C64.1, L2.2, L4.1
RF_CLK: J3.16, U8.1
RF_CS_N: J3.18, R33.2, U8.4
RF_DCOUPL: C55.1, U8.13
RF_FILT_MID: C65.1, L6.2, L7.1
RF_GDO0: U8.6, U21.11
RF_MISO: J3.15, U8.3
RF_MOSI: J3.12, U8.2
RF_NOTCH: C68.2, L8.1
RF_RBIAS: R32.1, U8.20
RF_SE_50: C64.2, L4.2, L5.2, L6.1
RF_XI: C53.1, U8.17, Y3.1
RF_XO: C54.1, U8.18, Y3.2
RLY_COIL_N: D9.1, K1.8, Q4.3
RS485_A: D26.1, J4.7, K1.5, R67.1, U29.6
RS485_B: D26.3, J4.8, K1.4, R67.2, U29.7
RS485_DE: R65.2, R66.1, U29.2, U29.3
RTL_AVDD10: C80.1, C81.1, U9.23
RTL_DVDD10: C78.1, C79.1, U9.16
RTL_DVDD10_UPS: C76.1, C77.1, U9.12
RTL_LANWAKEB: R40.2, U9.19
RTL_RSET: R39.1, U9.24
RTL_U2VDD10: C74.1, C75.1, U9.9
SCREEN_BL: J3.7, J6.8
SCREEN_DC: D33.2, J3.32, J6.6
SCREEN_RST: D32.2, J3.22, J6.5
SPI3_CLK: D30.2, J3.23, J6.3
SPI3_CS: J3.24, J6.7, R41.2
SPI3_MOSI: D31.2, J3.19, J6.4
SPK_N: F8.1, J16.2, R52.2
SPK_N_FUSED: C114.2, F8.2, J15.R1
SPK_P: F7.1, J16.1, R51.2
SPK_P_FUSED: C113.2, F7.2, J15.T
STINGER1_CC: D3.2, J7.A5, R15.2
STINGER5_CC1: D4.2, J11.A5, R24.2
STINGER5_CC2: D5.2, J11.B5, R25.2
STINGER_EN_1: J3.29, R16.2, U4.3, U32.1
STINGER_EN_2: J3.31, R18.2, U5.3, U32.3
STINGER_EN_3: J3.33, R20.2, U6.3, U32.5
STINGER_EN_4: J3.21, R22.2, U15.3, U32.9
STINGER_EN_5: R26.2, U21.10, U22.3, U32.11
STINGER_ISET_1: R17.1, U4.5
STINGER_ISET_2: R19.1, U5.5
STINGER_ISET_3: R21.1, U6.5
STINGER_ISET_4: R23.1, U15.5
STINGER_ISET_5: R27.1, U22.5
STINGER_OE_1: U32.2, U33.1
STINGER_OE_2: U32.4, U34.1
STINGER_OE_3: U32.6, U35.1
STINGER_OE_4: U32.8, U36.1
STINGER_OE_5: U32.10, U37.1
TRRS_RING2: C112.1, J15.R2, R62.2, R77.1
TRRS_RING2_P: D27.2, R77.2
USB_UP_DM: J13.A7, J13.B7, U3.3, U20.1, U20.3
USB_UP_DP: J13.A6, J13.B6, U3.2, U20.4, U20.6
USB_VBUS_1: C32.1, C33.1, F4.1, J7.A4, J7.A9, J7.B4, J7.B9, U4.4, U12.5
USB_VBUS_1_FUSED: D6.1, F4.2
USB_VBUS_2: C36.1, C37.1, D14.2, J8.1, U5.4, U16.5
USB_VBUS_3: C40.1, C41.1, D15.2, J9.1, U6.4, U17.5
USB_VBUS_4: C44.1, C45.1, F5.1, J10.1, U15.4, U18.5
USB_VBUS_4_FUSED: D7.1, F5.2
USB_VBUS_5: C48.1, C49.1, F6.1, J11.A4, J11.A9, J11.B4, J11.B9, U19.5, U22.4
USB_VBUS_5_FUSED: D8.1, F6.2
VIN: C2.1, C3.1, D1.2, D6.2, D7.2, D8.2, R1.1, TP1.1, U1.30
WAGO_COM1: J12.3, K1.7
WAGO_COM2: J12.4, K1.2
WAGO_MODE: J3.34, Q4.1, R34.1
WS2812B_DOUT_1: LED1.2, LED2.4
WS2812B_DOUT_2: LED2.2, LED3.4
WS2812B_DOUT_3: LED3.2, LED4.4

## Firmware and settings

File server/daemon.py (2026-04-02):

#!/usr/bin/env python3
"""
Daemon — Main orchestrator.
Spawns Claude Code, feeds it events (voice, USB, user input),
manages personality settling, and routes responses.
"""

import asyncio
import json
import os
import sys
import subprocess
from pathlib import Path
from datetime import datetime, timezone

from personality import (
    load_personality, save_personality, create_default_personality,
    add_to_history, detect_name_from_response, should_settle,
    run_settling, generate_settling_digest,
)
from memory import (
    ensure_collection, store_conversation_turn,
    build_memory_context, get_memory_stats,
)
try:
    from knowledge import (
        ensure_collections as ensure_knowledge,
        build_knowledge_context, get_knowledge_stats,
        store_conversation_summary,
    )
    HAS_KNOWLEDGE = True
except ImportError:
    HAS_KNOWLEDGE = False

# Project paths
DAEMON_ROOT = Path(__file__).parent.parent
SERVER_DIR = Path(__file__).parent
CONFIG_DIR = DAEMON_ROOT / "config"
SOUL_PATH = DAEMON_ROOT / "SOUL.md"
MCP_CONFIG_PATH = CONFIG_DIR / "mcp_tools.json"

CONFIG_DIR.mkdir(exist_ok=True)


def build_system_prompt(personality: dict) -> str:
    """Build system prompt from SOUL.md + personality state."""
    soul_template = ""
    if SOUL_PATH.exists():
        with open(SOUL_PATH) as f:
            soul_template = f.read()

    traits = personality["traits"]
    trait_lines = []
    for trait, value in traits.items():
        if value < 0.3:
            level = "low"
        elif value < 0.7:
            level = "moderate"
        else:
            level = "high"
        trait_lines.append(f"  {trait}: {value:.2f} ({level})")

    name = personality.get("name") or "unnamed"
    memories = personality.get("memory_highlights", [])
    memory_block = "\n".join(f"  - {m}" for m in memories[-20:]) if memories else "  (none yet)"

    prompt = f"""{soul_template}

## Current State

Name: {name}
Created: {personality.get('created_at', 'unknown')}
Interactions: {personality.get('interaction_count', 0)}

### Personality Traits (0.0 = low, 1.0 = high)
{chr(10).join(trait_lines)}

### Memory Highlights
{memory_block}

## Behavior Guide

Your personality traits shape HOW you communicate:
- directness {traits['directness']:.1f} → {"get to the point, skip hedging" if traits['directness'] > 0.6 else "explain your reasoning, add context" if traits['directness'] < 0.4 else "balanced directness"}
- humor {traits['humor']:.1f} → {"be witty, playful observations welcome" if traits['humor'] > 0.6 else "stay focused, humor only when natural" if traits['humor'] < 0.4 else "occasional humor"}
- warmth {traits['warmth']:.1f} → {"personal, reference past conversations, ask about the user" if traits['warmth'] > 0.6 else "professional, focus on the task" if traits['warmth'] < 0.4 else "friendly but task-oriented"}
- initiative {traits['initiative']:.1f} → {"proactively suggest and act" if traits['initiative'] > 0.6 else "wait for instructions" if traits['initiative'] < 0.4 else "suggest when relevant"}
- formality {traits['formality']:.1f} → {"structured, proper" if traits['formality'] > 0.6 else "casual, conversational" if traits['formality'] < 0.4 else "natural tone"}

{"If the user hasn't named you yet, start with: I'm here. Give me a name." if name == "unnamed" else ""}
"""
    return prompt


class DaemonProcess:
    """Manages Claude Code subprocess + personality lifecycle."""

    def __init__(self, model: str = "opus"):
        self.model = model
        self.session_id = None
        self.personality = load_personality()

    async def send_message(self, message: str) -> str:
        """Send message to Claude Code, return response."""
        system_prompt = build_system_prompt(self.personality)

        # Retrieve relevant knowledge + memories for this message
        if HAS_KNOWLEDGE:
            try:
                knowledge_context = build_knowledge_context(message, limit=5)
                if knowledge_context:
                    system_prompt += "\n\n" + knowledge_context
            except Exception as e:
                print(f"[knowledge] Recall failed: {e}")
        try:
            memory_context = build_memory_context(message, limit=3)
            if memory_context:
                system_prompt += "\n\n" + memory_context
        except Exception as e:
            print(f"[memory] Recall failed: {e}")

        cmd = [
            "claude", "-p", message,
            "--output-format", "json",
            "--model", self.model,
            "--system-prompt", system_prompt,
            "--permission-mode", "auto",
        ]

        # Add MCP tools if config exists
        if MCP_CONFIG_PATH.exists():
            cmd.extend(["--mcp-config", str(MCP_CONFIG_PATH)])
            cmd.extend([
                "--allowed-tools",
                "Bash", "Read", "Write", "Edit", "Glob", "Grep",
                "mcp__daemon-tools__ssh_run",
                "mcp__daemon-tools__list_devices",
                "mcp__daemon-tools__device_info",
                "mcp__daemon-tools__list_usb_devices",
                "mcp__daemon-tools__scan_i2c",
            ])

        # Resume session for conversation continuity
        if self.session_id:
            cmd.extend(["--resume", self.session_id])

        proc = await asyncio.create_subprocess_exec(
            *cmd,
            stdout=asyncio.subprocess.PIPE,
            stderr=asyncio.subprocess.PIPE,
        )
        stdout, stderr = await proc.communicate()

        if proc.returncode != 0:
            error = stderr.decode().strip()[:500]
            print(f"[daemon] Error: {error}")
            return f"[error communicating with Claude: {error[:100]}]"

        try:
            result = json.loads(stdout.decode())
            self.session_id = result.get("session_id")
            response_text = result.get("result", "")

            # Track interaction
            self.personality["interaction_count"] += 1
            save_personality(self.personality)

            # Save to history
            add_to_history("user", message)
            add_to_history("daemon", response_text)

            # Store in long-term memory (Qdrant)
            try:
                store_conversation_turn(
                    message, response_text,
                    daemon_name=self.personality.get("name", "daemon"),
                )
            except Exception as e:
                print(f"[memory] Store failed: {e}")

            return response_text
        except json.JSONDecodeError:
            return stdout.decode().strip()

    def process_response(self, user_msg: str, response: str):
        """Post-process a response: name detection, settling, etc."""
        # Name detection
        if not self.personality.get("name"):
            detected = detect_name_from_response(user_msg, response, self.personality)
            if detected:
                self.personality["name"] = detected
                save_personality(self.personality)
                print(f"[daemon] Name detected: {detected}")

        # Check if settling is due
        if should_settle(self.personality):
            print("[daemon] Running settling algorithm...")
            old_traits = dict(self.personality["traits"])
            self.personality = run_settling(self.personality)
            digest = generate_settling_digest(old_traits, self.personality["traits"])
            if digest:
                print(f"[settling] {digest}")
                # Could inject this as a daemon message next turn


async def interactive_loop(daemon: DaemonProcess):
    """Interactive text loop."""
    print("\n" + "=" * 60)
    name = daemon.personality.get("name")
    if name:
        print(f"  DAEMON [{name}] — Interactive Mode")
    else:
        print("  DAEMON — Interactive Mode (unnamed)")
    print("  Type a message. Ctrl+C to exit.")
    print("=" * 60 + "\n")

    # First-time intro
    if not daemon.personality.get("name") and daemon.personality.get("interaction_count", 0) == 0:
        response = await daemon.send_message(
            "(The user just started the daemon for the first time. "
            "You have no name yet. Introduce yourself briefly.)"
        )
        print(f"[daemon]: {response}\n")
        daemon.process_response("", response)

    while True:
        try:
            user_input = await asyncio.get_event_loop().run_in_executor(
                None, lambda: input("[you]: ")
            )
            if not user_input.strip():
                continue

            response = await daemon.send_message(user_input)
            print(f"\n[{daemon.personality.get('name', 'daemon')}]: {response}\n")

            # Post-process
            daemon.process_response(user_input, response)

        except (KeyboardInterrupt, EOFError):
            print(f"\n[daemon] Shutting down. Interactions: {daemon.personality['interaction_count']}")
            save_personality(daemon.personality)
            break


async def main():
    """Entry point."""
    personality = load_personality()
    name = personality.get("name", "unnamed")
    count = personality.get("interaction_count", 0)
    print(f"[daemon] Personality: {name} ({count} interactions)")
    print(f"[daemon] Traits: {json.dumps(personality['traits'])}")

    # Initialize memory + knowledge
    try:
        ensure_collection()
        stats = get_memory_stats()
        print(f"[daemon] Memory: {stats['total_memories']} memories")
    except Exception as e:
        print(f"[daemon] Memory unavailable: {e}")

    if HAS_KNOWLEDGE:
        try:
            ensure_knowledge()
            kstats = get_knowledge_stats()
            total = sum(kstats.values())
            print(f"[daemon] Knowledge: {total} entries ({kstats})")
        except Exception as e:
            print(f"[daemon] Knowledge unavailable: {e}")

    daemon = DaemonProcess(model="opus")

    # USB event queue
    usb_event_queue = asyncio.Queue()
    loop = asyncio.get_event_loop()

    def on_usb_event(event):
        asyncio.run_coroutine_threadsafe(usb_event_queue.put(event), loop)

    # Start USB monitor
    try:
        from devices import DeviceMonitor, configure_audio_device
        device_monitor = DeviceMonitor(on_event=on_usb_event)
        asyncio.create_task(device_monitor.start())
    except ImportError:
        print("[daemon] USB monitoring unavailable (pyudev not installed)")
        device_monitor = None

    # Voice pipeline
    voice_pipeline = None
    if "--voice" in sys.argv:
        try:
            from voice import VoicePipeline

            async def on_voice(text: str):
                response = await daemon.send_message(text)
                name = daemon.personality.get("name", "daemon")
                print(f"\n[{name}]: {response}\n")
                daemon.process_response(text, response)
                if voice_pipeline:
                    await voice_pipeline.speak(response)

            voice_pipeline = VoicePipeline(on_transcript=on_voice)
            asyncio.create_task(voice_pipeline.start_listening())
            print("[daemon] Voice pipeline active.")
        except ImportError:
            print("[daemon] Voice deps not installed (deepgram-sdk, sounddevice)")

    # USB event processor
    async def process_usb():
        while True:
            event = await usb_event_queue.get()
            if device_monitor:
                msg = device_monitor.format_event_for_daemon(event)
                if msg:
                    print(f"\n{msg}")
                    if event["type"] == "audio" and event["action"] == "add":
                        try:
                            from devices import configure_audio_device
                            await configure_audio_device()
                        except:
                            pass

    asyncio.create_task(process_usb())

    # Run
    await interactive_loop(daemon)

    # Cleanup
    if device_monitor:
        device_monitor.stop()
    if voice_pipeline:
        voice_pipeline.stop()


if __name__ == "__main__":
    asyncio.run(main())

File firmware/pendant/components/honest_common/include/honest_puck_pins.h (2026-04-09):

/*
 * Honest Puck v3.2 — pin map.
 *
 * Source of truth: /media/arthur/CA2247E02247D05D/projects/pendant/ARCHITECTURE.md
 * Do not change numbers here without also changing the KiCad netlist.
 */
#pragma once

#include "driver/gpio.h"

/* ---- Buttons (all active-low, external 10k pull-ups on the board) ---- */
#define HP_PIN_BTN_MAIN      GPIO_NUM_0   /* strapping — normal boot needs HIGH */
#define HP_PIN_BTN_PROG1     GPIO_NUM_1
#define HP_PIN_BTN_BATT      GPIO_NUM_9
#define HP_PIN_BTN_PROG2     GPIO_NUM_14

/* ---- Privacy interlock: Si2301BDS PMOS gate (ACTIVE LOW) ----
 * HIGH = mic VDD off + red LEDs off (rail dead).
 * LOW  = mic VDD on  + red LEDs lit (user is being recorded).
 * MUST be HIGH at boot. See components/honest_mic/honest_gate.c. */
#define HP_PIN_MIC_ENABLE_N  GPIO_NUM_4

/* ---- PDM microphone (IM73D122) ---- */
#define HP_PIN_PDM_CLK       GPIO_NUM_5
#define HP_PIN_PDM_DATA      GPIO_NUM_6

/* ---- LED boost enable (TPS61023) — powers WS2812C ring ----
 * Active high, 100k pull-down. */
#define HP_PIN_LED_BOOST_EN  GPIO_NUM_7

/* ---- WS2812C-2020 privacy LED ring (4 pixels, single data line) ---- */
#define HP_PIN_WS2812_DATA   GPIO_NUM_8
#define HP_LED_RING_COUNT    4

/* ---- QSPI NAND flash (W25N02KV) — handled by SPI bus driver ---- */
#define HP_PIN_FLASH_CS      GPIO_NUM_10
#define HP_PIN_SPI_MOSI      GPIO_NUM_11
#define HP_PIN_SPI_CLK       GPIO_NUM_12
#define HP_PIN_SPI_MISO      GPIO_NUM_13
#define HP_PIN_QSPI_IO2      GPIO_NUM_2
#define HP_PIN_QSPI_IO3      GPIO_NUM_3

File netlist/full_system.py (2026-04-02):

"""
netlist/full_system.py
ECO #2026-02-V2 – Final Release SKiDL Netlist: Daemon V0

Instantiates and wires every subsystem in the Daemon V0 architecture:

  Subsystem A  – IP5328P Power Management
    · IP5328P (QFN-40): high-current boost converter + Li-ion charger + I2C telemetry
    · 4.7µH high-current boost inductor (Isat > 5A) on the SW node
    · DFT test points TP1–TP4 and 0Ω isolation jumpers J1/J2
    · KEY pin wired to PMIC_KEY net (shared with A6 power UX circuit)
    · LED1/LED2/LED3 REMOVED (ECO #2026-03-E: I2C bus clamping conflict)

  Subsystem A5 – Goobay 74446 USB-C Mechanical Bridge
    · USB-C receptacle (B.Cu placement; 8.4mm vertical pitch to Radxa)
    · Upstream D+/D− feed SL2.1A hub directly

  Subsystem B  – SL2.1A 4-Port USB 2.0 Hub
    · SL2.1A (QFN-28): full-speed / high-speed USB 2.0 hub controller
    · 12 MHz crystal + 22 pF load caps; 12 kΩ RBIAS
    · Hub 1: Ports 1–3 → Stingers; Port 4 → Hub 2 cascade
    · Hub 2: Port 1 → Stinger 4; Port 2 → RTL8152B Ethernet

  Subsystem B2 – RTL8152B USB–Ethernet (NEW)
    · RTL8152B: USB 2.0 to 100Base-TX; PSELF=Low (bus-power), XTALDET=High
    · 25 MHz crystal reference
    · HanRun HR911105A MagJack; MDI TX+/TX−/RX+/RX− → RJ45 pins 1/2/3/6

  Subsystem A6 – Advanced Power UX (ECO #2026-03-D)
    · BSS84 PMOS wake-blocker: NAV_CENTER wakes when 5V OFF; isolated when ON
    · 2N7002 NMOS software kill: Radxa PMIC_KILL GPIO simulates double-tap
    · SW_PWR tactile button: always-on hard wake/sleep; SW_PWR_GPIO for long-press
    · 3-pin Power Management Header: PMIC_KILL / SW_PWR_GPIO / GND

  Subsystem C  – Stinger Ports (4 × SY6280AAC power-distribution switch)
    · One SY6280AAC (SOT-23-5) per stinger USB port + USBLC6-2SC6 ESD
    · 5V_SYS → SY6280 IN → USB_VBUS_x; 13 kΩ ISET (~500 mA OC limit, ECO #2026-03-H)

  Subsystem D  – 1.69″ SPI Display
    · 8-pin SIL connector for ST7789V2-based display module
    · SCK / MOSI / CS from Radxa SPI3 bus (pins 19/23/24); BL → GPIO4 / pin 7 (hardware PWM)

  Subsystem E  – Alps SKRHABE010 5-Way Navigation Switch (ECO #2026-03-NAV)
    · SMD 7.35×7.5mm tactile switch (UP/DOWN/LEFT/RIGHT/CENTER)
    · All digital GPIO (active-low, 10 kΩ pull-ups); no ADC needed
    · Replaces breakout analog joystick + ADS1015 I2C ADC

  Subsystem E2 – WS2812B Smart RGB LEDs × 4 (NEW)
    · Daisy-chained; data-in on LED_DIN (Radxa header pin 36)
    · 100 nF bypass per LED; 5V_SYS supply

  Subsystem E3 – Stealth IR Blaster (NEW)
    · VSMB294008 side-view SMD IR LED; front-edge placement
    · AO3400A N-MOSFET driver (Gate = IR_GPIO, Drain = LED−, Source = GND; ECO #2026-03-F)

  Subsystem F  – 40-Pin Radxa Expansion Header
    · 2×20 P2.54 mm connector; Raspberry Pi HAT / Radxa pinout
    · All 40 pins named: power rails, SPI3 (display), SoftSPI (CC1101),
      I2C1 (pins 3/5), I2S/PCM, screen BL/DC/RST, Stinger EN/FLAG, LED_DIN

  Subsystem G  – NE555 Heartbeat / Dummy-Load (SM-PWR-02)

  Subsystem H  – CC1101 Sub-GHz RF Transceiver
    · SoftSPI bus; 26 MHz crystal
    · Johanson 0915AT43A0026 chip antenna; Pi-network (C=0.5pF, L=10nH, C=4.7pF)
    · NOTE: SMA connector removed per ECO #2026-02-V2

  Subsystem J  – ISO1212 Industrial 24V Isolation + WAGO 2060-404
    · WAGO 2060-404 4-pos terminal block replaces pin-header field connector
    · Full IND-SAF-01 protection chain maintained (PTC/TVS/R/R/C per channel)

  Subsystem K  – MAX98357A + INMP441 Audio (ECO #2026-03-MERGE: merged from audio_subsystem.py)
    · MAX98357A I2S Class-D BTL amplifier + INMP441 MEMS microphone
    · 5V_SYS → ferrite bead → 5V_AUDIO (isolated amp supply)
    · ESD9B5.0ST5G bidirectional TVS diodes on AMP_OUT_P / AMP_OUT_N (SM-AUD-01)
    · Ferrite bead EMI filter on BTL outputs (SM-AUD-02)
    · TRRS NC switch topology for speaker auto-disconnect
    · Hardware mic-active privacy LED (always-on when mic powered)

  NOTE: CAN Bus (MCP2515 / MCP2551) REMOVED per ECO #2026-02-V2.
  NOTE: Hardware Reset Switch (A4) REMOVED per ECO #2026-03-D; replaced by A6 power UX.
  NOTE: USB Charging MUX (A3) REMOVED per ECO #2026-03-MERGE (dead circuit; orphan nets).

Power topology:
    Li-ion cell ──► IP5328P BAT ──► SW / inductor ──► VOUT
    VOUT ──[J2 0Ω]──► 5V_SYS ──► SL2.1A×2 VCC, SY6280×4 IN, WS2812B, Radxa 5V
    5V_SYS ──► AP2112K-3.3 ──► 3V3_CLEAN ──► CC1101, RTL8152B, ISO1212 logic side
    Radxa header 3.3V ──► 3V3_SYS ──► screen VCC, nav switch pull-ups

Custom KiCad symbol library required (add to ./lib/Daemon_V0.kicad_sym):
    IP5328P, SL2.1A×2, SY6280AAC×4, RTL8152B, ISO1212, USBLC6-2SC6×4, SKRHABE010

Usage:
    python -m netlist.full_system
    # → writes daemon_v0_full_system.net
"""

from __future__ import annotations

import sys
from pathlib import Path

try:
    import skidl
    from skidl import ERC, Net, Part, generate_netlist
    from skidl import TEMPLATE
except ModuleNotFoundError as exc:
    sys.exit(f"SKiDL not installed. Run: pip install skidl\n{exc}")

# ── KiCad 8 library setup ─────────────────────────────────────────────────────
# Add the project's custom symbol library directory so SKiDL can find
# Daemon_V0.kicad_sym (IP5328P, SL2.1A, SY6280AAC, RTL8152B, ISO1212, etc.)
_REPO = Path(__file__).resolve().parent.parent
_tool = skidl.get_default_tool()
_custom_lib = str(_REPO / "lib")
if _custom_lib not in skidl.lib_search_paths[_tool]:
    skidl.lib_search_paths[_tool].append(_custom_lib)

# ── Output ────────────────────────────────────────────────────────────────────

NETLIST_OUTPUT = "daemon_v0_full_system.net"

# ── Footprints ────────────────────────────────────────────────────────────────

# Power management
FP_IP5328P     = "Package_DFN_QFN:QFN-40-1EP_6x6mm_P0.5mm_EP4.6x4.6mm"
FP_INDUCTOR_5A = "Inductor_SMD:L_Bourns_SRR1260"  # 12.5×11.5mm package
# INDUCTOR MPN REQUIREMENT: must be TDK VLF12560T-4R7M7R9 (Isat=7.9A) or equiv.
# Peak inductor current: I_avg(3V→5V/2.46A,η=90%) + ΔI/2 = 4.56 + 0.34 = 4.90A
# Standard Bourns SRR1260-4R7Y has Isat≈4.3A — WILL SATURATE. Use VLF12560T only.
FP_LDO_SOT223  = "Package_TO_SOT_SMD:SOT-223-3_TabPin2"   # LM1117 (legacy; kept for reference)
FP_LDO_SOT23_5 = "Package_TO_SOT_SMD:SOT-23-5"            # AP2112K-3.3 (ECO #2026-03-GOLD)

# USB hub
FP_SL2_1A       = "Package_DFN_QFN:QFN-28-1EP_5x5mm_P0.5mm_EP3.35x3.35mm"
FP_XTAL_12M     = "Crystal:Crystal_SMD_3225-4Pin_3.2x2.5mm"
FP_USB_A_FEMALE = "Connector_USB:USB_A_Molex_67643_Horizontal"
FP_USB_A_MALE   = "Connector_USB:USB_A_CNCTech_1001-011-01101_Horizontal"
# ECO #2026-03-HWR: USB-C male stinger port (programmable unplug, same as USB-A)
FP_USB_C_PLUG   = "Connector_USB:USB_C_Plug_Molex_105444"

# Stinger switches
FP_SY6280       = "Package_TO_SOT_SMD:SOT-23-5"
# USB ESD protection (dual-channel, placed at each external connector)
FP_USBLC6       = "Package_TO_SOT_SMD:SOT-23-6"
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

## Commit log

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2026-02-23 Apply all red-team audit fixes across all four CI pipeline phases
    Phase 2 – Netlist (netlist/audio_subsystem.py, netlist/full_system.py):
    SM-LOG-03: Replace static 1MΩ SD_MODE pull-up with formula-computed 633kΩ
    (R_LARGE = 222.2 × V_DDIO − 100 at 3.3V VDDIO)
    SM-AUD-01: Add ESD9B5.0ST5G TVS diodes (SC-70-3) on AMP_OUT_P/N BTL rails
    to clamp inductive flyback from speaker voice-coil bounce
    SM-AUD-01: Replace direct TRRS detect wiring with 10kΩ/100nF RC debounce
    (τ=1ms) on TRRS_DETECT_RAW → AMP_SD path
    PDN-JMP-04: Upsize isolation jumpers J1/J2 from 0402 to 1225 wide-terminal
    reverse-geometry package (≥3.5A rated vs 0402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
    [audio_subsystem.py, configure_constraints.py, freerouting_dsn.py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]
2026-02-23 chore: initial commit before Step 2 fixes
    [full_system.py]
2026-02-23 fix: RF Balun network and ADS1015 Analog Domain Offload
    [full_system.py]
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2026-02-26 feat: ECO #2026-03-GOLD complete + post-GOLD hardware review fixes
    ECO #2026-03-GOLD (Golden Master Cleanup):
    - Replace LM1117-3.3 with AP2112K-3.3 LDO (250mV dropout, SOT-23-5)
    - Remove ESP32 from audio_subsystem.py; Radxa Zero 3W is I2S master
    - Rename RF Pi-network parts to C_RF1/L_RF1/C_RF2 for BOM traceability
    - Rename SPI0 nets to SPI3_MOSI/MISO/CLK/CS (correct Radxa designation)
    - Add gen_golden_netlist.py sync script
    Post-GOLD hardware review (A-20, A-21):
    - Inductor MPN hardened: TDK VLF12560T-4R7M7R9 (Isat=7.9A, Idc=5.0A)
    Worst-case peak = 4.90A; Bourns SRR1260-4R7Y (Isat≈4.3A) insufficient
    - BRINGUP-CRITICAL: VCCIO domain warning on I2C1 (GPIO0_B3/B4)
    If VCCIO=1.8V, ADS1015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
    [audio_subsystem.py, full_system.py, gen_golden_netlist.py]
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2026-03-07 fix: resolve hardware review blocker + warnings
    BLOCKER B-1 FIXED:
    - NE555 DIP-8 → NE555DR SOIC-8 (turnkey SMT compatible)
    - 100µF electrolytic (THT, 8mm tall) → 100µF tantalum Case-D (SMD, 2.8mm)
    - Eliminates all through-hole dependencies except RJ45 MagJack
    - Resolves Z-height collision risk with Radxa stack
    WARNING W-5 FIXED:
    - C_TANT voltage rating 6.3V → 10V (2x derating on 5V rail)
    HARDWARE REVIEW added (docs/HARDWARE_REVIEW.md):
    - 1 blocker (now fixed), 11 warnings (quantified), 15 verified stable
    - Power system, RF, audio, USB hub, Ethernet all verified stable
    - Key remaining risks: WS2812B level (firmware open-drain), LDO thermal margin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
    [daemon_v0.kicad_pcb]
2026-03-07 fix: 40-pin header to female socket, add mic power LED, edge-mount power button
    ECO #2026-03-HWR fixes:
    - J12: PinHeader_2x20 → PinSocket_2x20 (female socket mates with Radxa male pins)
    - SW1: PTS645 top-press → Alps SKRTLAE010 right-angle (flush with board edge)
    - Added red 0402 LED + 1k resistor on INMP441 VDD (hardware mic-active indicator)
    - Total components: 164 → 166 (mic LED + resistor added)
    - All 164 tests pass
    [daemon_v0.kicad_pcb]
2026-03-07 feat: cascaded USB hubs + 4 stinger ports (2 male + 2 female)
    Replace single SL2.1A hub with two cascaded hubs to support 5 downstream
    USB devices: 4 stinger ports + RTL8152B Ethernet.
    Hub topology:
    - Hub 1: ports 1-3 → stingers 1-3, port 4 → Hub 2 cascade
    - Hub 2: port 1 → stinger 4, port 2 → Ethernet
    Stinger port configuration:
    - Port 1: USB-C male plug (parasitic output)
    - Port 2: USB-A male plug (parasitic output)
    - Port 3: USB-A female receptacle (device input)
    - Port 4: USB-A female receptacle (device input)
    GPIO pin 21 (SPI3_MISO, unused by screen) repurposed for STINGER_EN_4.
    [full_system.py, prepare_layout_board.py]
2026-03-07 fix: NE555 R2 wiring bug + USB ESD protection + stale docs
    Critical fixes from deep architecture review (ECO #2026-03-HWR2):
    1. NE555 R2 wiring: both pins were on the same net (tmr_thr),
    shorting R2 out. Added intermediate node HB_TMR_NODE_A between
    R1 and R2, with DIS tapping node_a. Duty cycle now correct
    at 0.07% instead of ~50%.
    2. USB ESD: added USBLC6-2SC6 dual-channel TVS on all 4 stinger
    port D+/D- pairs. IEC 61000-4-2 compliant (±15kV air, ±8kV
    contact).
    3. USB-A male Shield pin: added try/except fallback for male plug
    footprints that may not expose separate Shield pads.
    4. Stale docs: pin 21 (SPI3_MISO → STINGER_EN_4), Ethernet port
    (Hub 2 port 2, not H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
    [full_system.py]
2026-03-07 fix: round 2 review — dead code, stale counts, comment accuracy
    - Remove unused ETH_USB_VBUS net (dead code, would cause ERC orphan)
    - Update SY6280 count in header: 3→4 throughout
    - Fix 555 timing formula comment: t_HIGH = 0.693×(R1+R2)×C
    - Fix display size: 1.47"→1.69" in section comment
    - Fix RTL8152B PSELF comment: clarify bus-powered descriptor intent
    - Fix stale _build_usb_hub reference → _build_sl21a_hub
    - Fix rf_gdo0 comment: not on header (polling mode)
    - Fix BOM footer: Stinger ports ×3 → ×4
    [full_system.py]
2026-03-07 fix: IP5328P missing GND + charging MUX isolation + BOM crystal count
    Round 3 review fixes:
    1. CRITICAL: IP5328P GND pin was never connected — PMIC had no
    ground return path. Added ic["GND"] += gnd.
    2. USB charging MUX (PDN-USB-01): VBUS_A and VBUS_C nets are
    created but never connected to external sources. The entire
    OR-diode circuit is isolated from the power path. Added TODO
    comment — needs integration or removal.
    3. BOM crystal count: 3 → 4 (2x 12MHz hub + 25MHz ETH + 26MHz RF)
    4. Fixed stale SoftSPI pin comments in _build_radxa_header signature
    [full_system.py]
2026-03-18 feat: golden netlist v0 — 247 components, 164 nets, full audit pass
    Major changes to golden netlist (gen_golden_netlist.py):
    - USB ports: 2× USB-A female, 1× USB-A male, 2× USB-C female, 1× USB-C male
    - Charging: SS34 Schottky diodes from 3 chargeable ports to IP5328P VIN
    - Safety: SMBJ5.0A TVS on VIN and 5V_SYS, battery PTC fuse (was 0Ω jumper)
    - ESD: ESD5Z3.3 on all USB-C CC lines (5 diodes total)
    - NE555: fixed timing (47k/150Ω, 3.3s cycle), dummy load 82Ω (61mA > 50mA threshold)
    - Audio: SD_MODE pull-up 47k for margin, TRRS detect comment corrected
    - IC pins: all physical pads declared (RTL8152B, MAX98357A, ISO1212, AP2112K)
    - Boot: port 1 EN and CC Rp pulled to 5V_SYS (not 3V3_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
    [gen_golden_netlist.py]
2026-03-18 fix: netlist pad numbering + KiCad import with full net assignments
    The netlist was outputting pin NAMES (CC1, VDD, EPAD, D+, etc.) but
    KiCad footprints use pad NUMBERS (1, 2, 3...). Every IC had zero net
    connections in KiCad because "CC1" != pad "2".
    Added PIN_MAPS dict to gen_golden_netlist.py mapping pin names to KiCad
    pad numbers for all 20+ IC/connector types (IP5328P QFN-40, SL2.1A,
    RTL8152B, MAX98357A, CC1101, ISO1212, PCF8574, NE555, AP2112K, SY6280,
    USB-C plug/receptacle, USB-A, TRRS jack, WS2812B, LEDs, MOSFETs, etc.)
    Updated import_netlist.py to use .net file pad assignments directly
    instead of trying to match pin names. Result: 802/802 pad-net
    connections assigned (was 0).
    Co-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
    [daemon_v0.kicad_pcb]
2026-03-19 feat: add NAU88C22 codec, ADS1115 ADC, SP3485 RS-485, TSOP38238 IR RX
    New components (278 total, +31):
    - NAU88C22 audio codec (QFN-32): full-duplex audio via TRRS jack,
    enables guitar pedal mode, headset mic, line-in. Shares I2S bus
    with INMP441 mics in TDM mode. I2C control at 0x1A.
    - ADS1115 16-bit ADC (MSOP-10): 4 analog inputs on I2C1 (0x48),
    broken out to J17 header for sensors, expression pedals, 4-20mA.
    - SP3485 RS-485 transceiver (SOIC-8): Modbus/DMX-512 on UART2
    (AUX_GPIO_1/2/3). 120ohm termination. J18 terminal header.
    - TSOP38238 IR receiver: demodulated output to PCF8574 P7,
    completes IR subsystem (TX+RX). Learns any remote protocol.
    - J19 UART debug header (1x4: GND/TX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
    [daemon_v0.kicad_pcb]
2026-03-19 fix: audit findings — I2S bus fight, IR filter, LIGHT LED, RS485 boot
    CRITICAL fixes:
    - NAU88C22 ADCOUT: separate CODEC_ADCOUT net (was sharing I2S_DATA_IN
    with INMP441 mics = bus fight). Added 0R DNP jumper for optional
    connection when mics are disabled in firmware.
    - TSOP38238: VCC filter was wired to IR_RX output instead of VS power
    pin. Created IR_VS_FILT net with proper 100R+100nF+4.7uF filtering.
    WARNING fixes:
    - IP5328P LIGHT LED: reversed polarity (open-drain sinks, can't source).
    Rewired as 3V3→1k→LED_A→LED_K→LIGHT pin.
    - SP3485 RS485_DE: added 100k pull-down for default receive mode during
    boot before GPIO is configured.
    280 components, 192 nets. All tests pas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
    [daemon_v0.kicad_pcb]
2026-03-21 fix: screen connector through-hole, female headers, antenna keepout
    - J6 screen connector: PinSocket→PinHeader (through-hole, screen sits
    flush against PCB bottom)
    - J17 (Analog-In), J18 (RS485), J19 (UART): male→female pin sockets
    - Added antenna keep-out zone (16×16mm rectangle on Dwgs.User)
    - Preserved 265 component placements from screenshot2
    - All 4581 drawings preserved (Radxa DXF + custom shapes)
    [daemon_v0.kicad_pcb]
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2026-03-21 feat: fortress mode — full port protection + ATECC608B secure element
    311 components (+33). Every external port now has protection:
    Protection additions:
    - J13 Goobay VBUS: PTC 1A fuse + SMBJ5.0A TVS (was ZERO protection)
    - J17 Analog inputs: 4x 10k series + 4x ESD5Z3.3 TVS (24V/ESD safe)
    - J4 GPIO pins: 4x 1k series + 4x ESD5Z3.3 TVS (24V/ESD safe)
    - BAT1: SS34 reverse-polarity diode + SMBJ5.0A overvoltage TVS
    - J15 TRRS: 2x PTC 200mA on speaker + 1k + TVS on Ring2 (48V safe)
    - J14 Ethernet: 2x SM712 TVS arrays (lightning/surge safe)
    - USB charging ports: 3x PTC 500mA fuses (sustained overvoltage)
    - RS-485 bus: SM712 asymmetric TVS (transient safe)
    - WAGO field power: SS14 reverse-polari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
    [gen_golden_netlist.py]
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2026-03-21 fix: red team findings — orphaned protection nets + new hardening
    Critical bugs fixed (protection components were added but not wired):
    - SS34 charging diodes now route through PTC fuses (were bypassing them)
    - BAT reverse-polarity SS34 now IN the current path (BAT→SS34→PTC→BAT_ISO)
    - Removed SS14 WAGO→3V3_SYS (was backfeeding 24V field power + defeating isolation)
    New protection added:
    - J6 display: ESD5Z3.3 TVS on all 4 SPI signals
    - I2C bus: ESD5Z3.3 TVS on SDA/SCL
    - J4 power pins: PTC fuses on 3V3/5V outputs
    - J4 GPIO pins: now go through 1k+TVS before reaching header
    - J17 analog pins: now go through 10k+TVS before reaching header
    - TRRS speaker lines: PTC between jack and am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
    [gen_golden_netlist.py]
2026-03-21 feat: USB data switches (TS3USB221) — true security disconnect
    CRITICAL security fix: SY6280 only cuts VBUS power, not D+/D- data.
    A self-powered device on a "disabled" port had full USB data access.
    Added:
    - 5x TS3USB221 USB 2.0 DPDT data switches (one per stinger port)
    - 1x 74LVC04A hex inverter (STINGER_EN active-high → OE active-low)
    - All USB connectors now use _SW (switched) data nets
    - USBLC6 ESD moved to connector side (after switch)
    When STINGER_EN=LOW: SY6280 kills VBUS AND TS3USB221 opens D+/D-.
    True electrical isolation — no data path, no power, no enumeration.
    334 components, 235 nets. All tests pass.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
    [gen_golden_netlist.py]
2026-03-21 fix: round 2 red team — TVS on USB-A host VBUS (body diode backfeed)
    USB-A host ports 2/3 had no overvoltage protection on VBUS.
    SY6280 body diode could backfeed >6V to 5V_SYS, killing SL2.1A hubs
    and AP2112K LDO. Added SMBJ5.0A TVS directly on USB_VBUS_2/3.
    Round 2 findings status:
    - I2C lockup: accepted for V0 (firmware recovery, V1 adds bus switch)
    - Boot race: not vulnerable (ports 2-5 have no VBUS during boot)
    - SY6280 backfeed: FIXED (TVS on each USB-A VBUS)
    - I2S no TVS: accepted (internal connector, not user-facing)
    - Codec/amp contention: firmware manages (not hardware)
    336 components, 235 nets.
    [gen_golden_netlist.py]
2026-03-21 chore: KiCad re-import — 336 components, placements preserved
    Re-imported netlist into KiCad PCB:
    - 336/336 footprints placed (ATECC608B footprint fixed)
    - 1096 pad-net connections
    - 261 components in your placed positions (from screenshot2)
    - 75 new protection/security components in staging area
    - 4582 drawings preserved (Radxa DXF + custom shapes)
    [daemon_v0.kicad_pcb]
2026-03-21 fix: restore component flip/side from screenshot2 — 23 on back side
    Components correctly placed on B.Cu (back): BAT1, J3, J7-J11, J14-J16,
    L1, LED5, SW1, U7, U10, U12, U13, U16, U18, U24, U30, Y4, C13.
    [daemon_v0.kicad_pcb]
2026-03-21 fix: screenshot3 sync + 3D model paths + J6 back to female socket
    - Applied all 338 placements from screenshot3 (83 back-side components)
    - Fixed 3D model paths in custom footprints (KIPRJMOD/lib/3dmodels/)
    - J6 screen connector: back to PinSocket (female, on back side)
    - 4585 drawings preserved from screenshot3
    4 custom 3D models now resolve correctly:
    Antenna, RJ45 MagJack, Alps nav switch, USB-C receptacle
    Still need 3D models (not freely downloadable):
    USB-C plug, INMP441, TRRS jack, WAGO, JST speaker
    [daemon_v0.kicad_pcb]
2026-03-21 fix: flip J6 screen connector to B.Cu — female socket on back side
    [daemon_v0.kicad_pcb]
2026-03-21 fix: J6 screen connector — PinHeader through-hole pads for Mill-Max receptacles
    [daemon_v0.kicad_pcb]
2026-03-21 feat: 3D models — USB-C plug, INMP441, JST speaker now resolved
    Added/fixed 3D model references:
    - GCT USB4155 USB-C plug: STEP from user's downloaded zip
    - INMP441 MEMS mic: from KiCad Sensor_Audio library
    - JST SH SM02B speaker: from KiCad Connector_JST library
    - Fixed INMP441 model filename in footprint
    Still need manual download (require account):
    - CUI SJ2-2531X TRRS jack (TraceParts)
    - WAGO 2060-404 terminal (WAGO PartCommunity)
    3D models now resolved: 8 of 10 custom components.
    [daemon_v0.kicad_pcb]
2026-03-21 fix: WAGO 2060-403 (3-position) — 4-position doesn't exist
    WAGO 2060 series only goes up to 3-position. Removed ISO_VCC1 from
    terminal block (powered internally from 3V3_SYS, no need to expose).
    WAGO now has: GND, COM1 (ch1/RS485-A), COM2 (ch2/RS485-B).
    Using 4-pad footprint with pad 4 unconnected until we make a proper
    3-pad custom footprint.
    [gen_golden_netlist.py]
2026-03-21 fix: J6 screen connector — bare holes footprint (no 3D pin model)
    [gen_golden_netlist.py]
2026-03-21 feat: board ready for routing — 4-layer, 336 components, all placed
    - 4 copper layers: F.Cu, In1.Cu (GND), In2.Cu (PWR), B.Cu
    - All 336 components placed from screenshot4 (0 in staging)
    - 1095 pad-net connections
    - Mill-Max footprint for J6 screen (bare holes, no 3D model)
    - WAGO 3D model linked
    Set design rules in KiCad GUI before routing:
    Board Setup → Design Rules → Net Classes:
    - Clearance: 0.15mm
    - Track width: 0.2mm (signal), 0.4mm (power)
    - Via: 0.6mm pad / 0.3mm drill
    Board Setup → Board Stackup → 4 layers
    [daemon_v0.kicad_pcb]
2026-03-21 fix: correct rotation on all 23 back-side components (flip negated rotation)
    [daemon_v0.kicad_pcb]
2026-03-21 fix: restore board from screenshot4 (disk full corrupted file) + J6 rotated 180°
    [daemon_v0.kicad_pcb]
2026-03-22 fix: replace fake WAGO footprint with real Phoenix PT-1.5-3 screw terminal (3D model included)
    [gen_golden_netlist.py]
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2026-03-22 feat: Freerouting v1.9 complete — 3796 traces, 397 vias, 3h18m routing
    Freerouting v1.9.0 (stable) routed the board in 3 hours 18 minutes
    + 5 minutes optimization. v2.1.0 was broken (NullPointerExceptions,
    80% failure rate).
    Results:
    - 3399 copper traces
    - 397 vias
    - 4 copper layers (F.Cu, In1_Cu GND plane, In2_Cu power planes, B.Cu)
    - 5 copper fill zones (GND on F/In1/B, 5V_SYS + 3V3_SYS on In2)
    [daemon_v0.kicad_pcb]
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2026-03-22 fix: 73 new pad mappings — down from 135 to 51 unassigned
    Expanded PIN_MAPS for USB-C (26 pads each), USB-A (shield pad),
    RJ45 (LED+shield), relay (SMD pad numbers), SM712 (SOT-23-6 NC pads),
    ATECC608B, power button, speaker connector, INMP441.
    Remaining 51 unassigned are all QFN EPAD/thermal pads with empty
    pad names ("") — these connect via GND copper pour automatically.
    Terminal block switched to KF301-compatible (RND 205-00014).
    All copper zones and tracks cleared for fresh placement.
    [daemon_v0.kicad_pcb]
2026-03-22 fix: restore placements from screenshot4 (import had reset to grid)
    [daemon_v0.kicad_pcb]
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2026-03-22 feat: screenshot5 placements + fixed antenna footprint (7x2mm) + keep-out zone
    [daemon_v0.kicad_pcb]
2026-03-22 fix: critical — headphone output was wired to wrong side of TRRS NC switch
    Codec LHPOUT/RHPOUT connected to AMP_OUT_P/N_FILT (TipSwitch side)
    which DISCONNECTS when headphones are plugged in. Changed to
    SPK_P/N_FUSED (Tip/Ring1 contacts) which stay connected.
    Without this fix: headphones would produce zero audio. Speaker would
    work fine (masking the bug).
    Also noted from audit (document for BOM):
    - Relay must be G6K-2F-Y-DC3 (3V variant, not 5V)
    - NAU88C22 unused SPKOUT/RMIC/AUX pins should be grounded in layout
    - SCREEN_BL and SPI3_CS lack ESD TVS (minor)
    [gen_golden_netlist.py]
2026-03-22 fix: INMP441 footprint WRONG — pitch was 1.47mm (should be 1.33mm), pads were 0.62x0.77 (should be 0.40x0.60)
2026-03-22 feat: swap TRRS jack to PJ-320D 3.5mm (was 2.5mm SJ2-2531X)
    - PJ-320D: standard 3.5mm TRRS, SMD, LCSC C95562, $0.05
    - No NC switches — speaker/headphone switching via software
    (firmware controls MAX98357A SD_MODE pin)
    - KiCad built-in footprint + 3D model
    - Added 0R bridges from amp output to speaker/jack path
    (NC switches previously bridged these)
    - 338 components
    [gen_golden_netlist.py]
2026-03-22 feat: re-import with fixed footprints (antenna 7mm, INMP441 1.33mm pitch, PJ-320D 3.5mm jack)
    [daemon_v0.kicad_pcb]
2026-03-22 fix: remove dead TRRS detect circuit (PJ-320D has no detect pin)
    - Removed R56 (10k from TRRS_DETECT_RAW to AMP_SD) — dead end net
    - Removed TRRS_DETECT_RAW net entirely
    - Changed AMP_SD pull-up from 47k to 100k (gives 1.65V = left channel
    mono, correct for single speaker)
    - Headphone detection: via NAU88C22 codec impedance sensing (software)
    - Amp shutdown: firmware writes AMP_SD low via codec GPIO or I2C
    337 components, 234 nets. Zero dead-end signal nets.
    [gen_golden_netlist.py]
2026-03-22 fix: CRITICAL — USB data switches on 3V3_CLEAN (was 3V3_SYS = boot dead)
    74LVC04A inverter and all 5x TS3USB221 USB data switches were powered
    from 3V3_SYS (only available after Radxa boots, 2-3s delay). During
    boot, the data switches were unpowered = USB D+/D- blocked = Radxa
    could never enumerate on the hub = device appeared dead.
    Changed to 3V3_CLEAN (AP2112K LDO from 5V_SYS, available within ms).
    Also flagged for layout:
    - PTC 200mA in speaker path will trip at normal volume (peak 894mA)
    - 181uF on 5V_SYS may cause IP5328P startup hiccup
    - NAU88C22 needs pull-downs on I2S during boot
    - QFN thermal vias needed in layout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
    [gen_golden_netlist.py]
2026-03-22 fix: TRRS mic protection was dead-end stub — now 1k+TVS protects codec input
    [gen_golden_netlist.py]
2026-03-22 fix: CRITICAL — NAU88C22 MCLK was tied to GND (codec would be dead)
    NAU88C22 PLL requires 8-33MHz reference on MCLK pin. It CANNOT
    derive clock from BCLK — confirmed by datasheet and Linux driver.
    With MCLK=GND, codec produces no audio at all.
    Fix: Share GPIO3_A2 (J3 pin 12) between MCLK and RF_MOSI.
    Radxa firmware pin-muxes between I2S3_MCLK (audio mode) and
    GPIO/SPI (RF mode). Cannot use both simultaneously, which is
    fine — you don't TX sub-GHz radio while recording audio.
    Also confirmed by datasheet agent:
    - TS3USB221 at 3.3V: safe (max 3.6V), 1GHz bandwidth ✅
    - SL2.1A SOP-16: supports USB 2.0 High Speed (480Mbps) ✅
    - SP3485: 10Mbps at 3.3V, handles DMX-512 (250kbaud) easily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
    [gen_golden_netlist.py]
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2026-03-22 fix: add antenna copper keepout zone (10x7mm, no copper pour under ANT1)
    [daemon_v0.kicad_pcb]
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2026-03-22 fix: CRITICAL — NC net had 44 pins connected together, wasting autorouter resources. Now each NC pad has unique net.
    [gen_golden_netlist.py]
2026-03-23 feat: 6-layer board variant + NC net fix (44 phantom connections removed)
    - daemon_v0_6layer.kicad_pcb: 6-layer version with GND planes on
    In1/In2, power planes on In3, signal on F.Cu/In4/B.Cu
    - NC net split: was 1 net connecting 44 unrelated pads, now each NC
    pad has unique net. Autorouter was wasting massive resources routing
    these phantom connections.
    - Freerouting running overnight on 4-layer with GND fills
    - 6-layer DSN needs GUI export tomorrow
    - Try Quilter AI (quilter.ai) and DeepPCB (deeppcb.ai) for AI routing
    [daemon_v0_6layer.kicad_pcb]
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2026-04-01 Major update: security fixes, MCP plotting tools, auth flow, research docs
    - Fix pre-auth RCE: all Python exec uses env vars instead of string interpolation
    - Add bcrypt password hashing (with SHA256 fallback for existing users)
    - Add login by daemon name (not just email)
    - Add Google OAuth flow (Sign In with Google button)
    - Add login modal overlay on subdomain pages (name.daemon.page)
    - Add MCP tools: plot_sensor_web, plot_sensor_esp32, push_to_web
    - Fix esp32_command MCP tool to go through phone WiFi (not MSI serial)
    - Add sensor reading via SSH→Pixel→HTTP→ESP32 (read_sensor.sh)
    - Dynamic Y-axis on canvas sensor graph
    - Canvas hidden by default, pops up on SSE data, X to dismiss
    - C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
2026-04-03 feat: daemon platform — desktop apps, project management, billing, memory system
    Major session building Daemon from terminal tool to full platform:
    - Android DaemonService: bulletproof connectivity (exp backoff, heartbeat, network listener, wake lock)
    - WS server + reverse proxy architecture (proxy.js routes HTTP/WS on single port)
    - Node.js CLI bridge (daemon.mjs) — cross-platform, tested on Linux + Windows MSI
    - Tauri v2 Windows desktop app (Rust backend, WebSocket, shell exec, system tray)
    - Mac installer (curl | bash, LaunchAgent, no admin needed)
    - SQLite database layer (projects, threads, messages, usage, subscriptions, memory)
    - Claude Code history import (19K messages, 335 sessi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
    [build_memory.py, embed_conversations.py, import_claude_history.py]
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2026-04-03 feat: cross-device clipboard sync
    Copy on any device, paste on any other. Clipboard changes broadcast
    via WebSocket to all connected devices with 1-2s latency.
    - CLI (daemon.mjs): polls clipboard every 1s per platform (pbpaste/Get-Clipboard/xclip)
    - Android: polls ClipboardManager every 1.5s, writes on receive
    - WS server: broadcasts clipboard_update to all other devices, keeps 50-entry history
    - Echo prevention: source device ignored, lastClipboard tracked
    [claude_brain.py, gemini_live.py]
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2026-04-07 fix: arturito dev memory + /chat/[name] route + horizontal scroll
    - Cleaned arturito project memory: removed conversations from INSIDE the
    Arturito tool (HubSpot queries, contract drafting). Wrote correct dev memory
    describing actual code work: Composio isolation, session timeout, contract
    template injection (commit a42fb24)
    - Added /chat/[name] dynamic route — refresh-safe URLs like /chat/arturito
    - Chat page now syncs URL to /chat/{slug} and persists last project in localStorage
    - Fixed horizontal scrollbar with explicit max-width:100vw on html/body and
    word-break on chat content (long URLs were pushing width)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
    [patent_fig1a.kicad_sch]
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

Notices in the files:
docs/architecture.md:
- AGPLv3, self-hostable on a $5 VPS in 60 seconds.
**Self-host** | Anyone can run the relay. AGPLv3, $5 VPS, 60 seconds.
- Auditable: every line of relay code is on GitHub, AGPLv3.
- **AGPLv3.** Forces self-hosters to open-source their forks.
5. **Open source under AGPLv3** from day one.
